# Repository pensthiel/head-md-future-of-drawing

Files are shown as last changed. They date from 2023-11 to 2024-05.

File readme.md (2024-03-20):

### Creation of the git

- *First upload on 2023-10-31*

# Contents

[**Process**](process) - [*log*](process/readme.md)

- Field researche and everything else I've been doing from the start, chronologically.

[**Presentations**](presentations) - [*log*](presentations/readme.md)

- Archives of my presentations

[**Electronics**](electronics) - [*log*](electronics/readme.md)

- Steps and references on building the electronics

[**Object**](object) - [*log*](object/readme.md)

- Thoughts, research and references on the final form of the device/object

[**UI and Programming**](programming) - [*log*Developing the program in Python

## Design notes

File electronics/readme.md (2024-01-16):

# Electronic

Shortcuts:

1. [2023-12-06](#2023-12-06) Setting up the Rasberry PI
2. [2023-12-07](#2023-12-07) Soldering ex.
3. [2023-12-21](#2023-12-21) controlling the projector
4. [2024-01-09](#2024-01-09) To do
5. [2024-01-10](#2024-01-10) Fritzing
6. [2024-01-13](#2024-01-13) Final schematic
7. [2024-01-16](#2024-01-16) Object

<br/><br/>

###### 2023-12-07

## Setting up the Rasberry PI

I plugged the PI to power and a screen but nothing appeared so I watched [this video](https://www.youtube.com/watch?v=2RHuDKq7ONQ) to flash the sd card. IT WORKED:

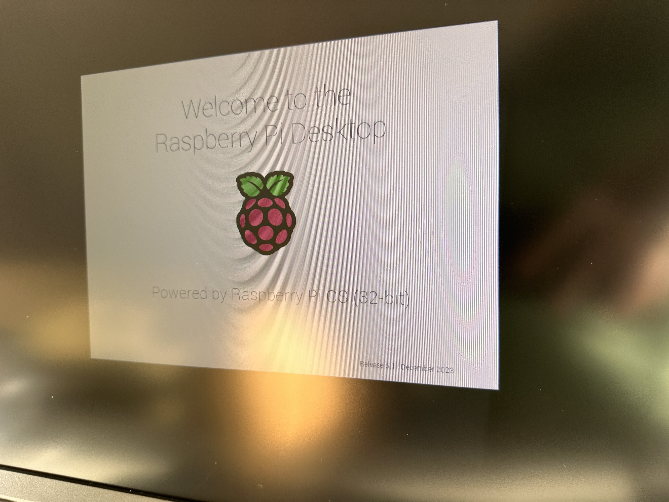
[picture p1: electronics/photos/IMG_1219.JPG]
pi


<br/>

###### 2023-12-06

## Soldering ex.

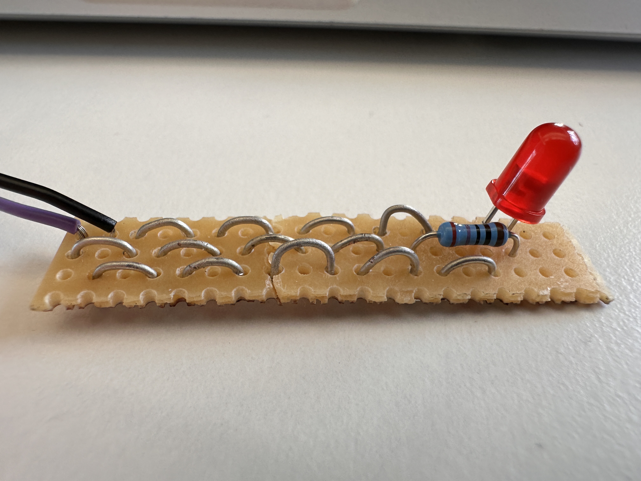
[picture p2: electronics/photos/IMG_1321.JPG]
solder
  
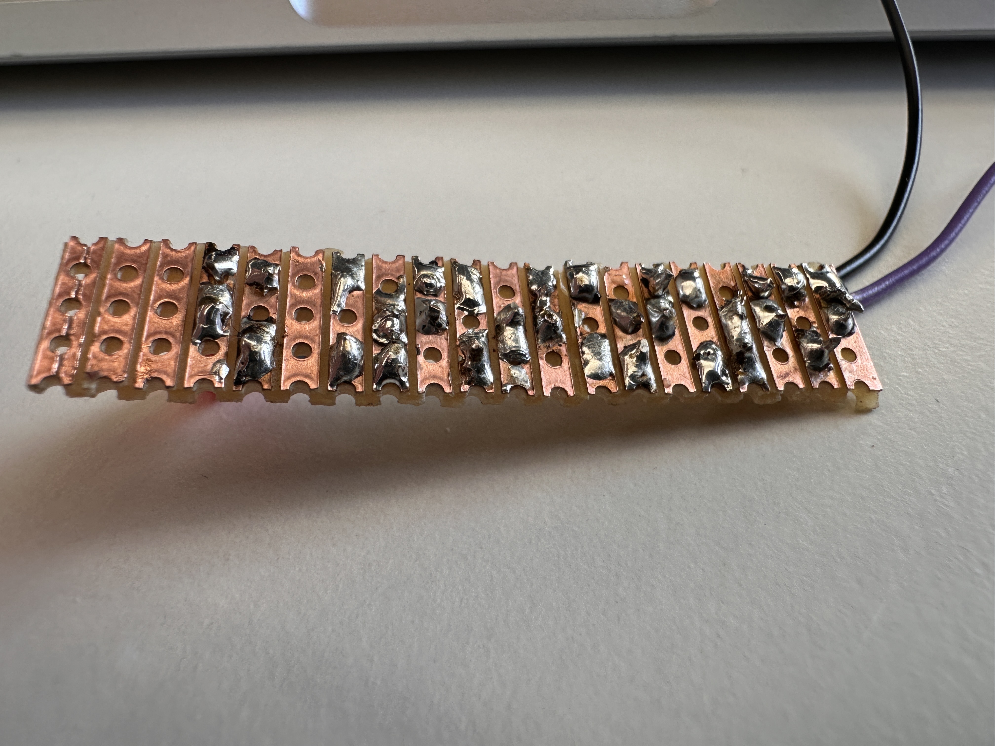
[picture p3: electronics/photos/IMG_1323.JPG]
solder2


<br/>

###### 2023-12-21

## controlling the projector

TRY to control it with HDMI with a Python library.

plan B :  
OCTO-ISOLATORs connected to buttons to control the projector buttons with the pi, you activate it as if u were turning on a led.

Don't forget we'll add LEDs to the house !

<br/>

###### 2024-01-09

## To do

- Projector control solution

I noticed there's an IR sensor and found the remote, I could read the remote's signals with the flipper zero so that I can send those signals from the rasberry with a IR led :-)

#### componants list

- <b><span style="color:rgba(244,63,94,1)">Pi</span></b>

**power switch**

GPIO pins 39 and 40. -> [link](https://www.makeuseof.com/tag/add-power-button-raspberry-pi/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't%2520get,GPIO%2520pins%252039%2520and%252040.)

**cherry button next frame**

GPIO 17 & GND -> [link](http://razzpisampler.oreilly.com/ch07.html)

**cherry button preview movie**

GPIO 18 & GND

**IR led**

[link](https://projects.raspberrypi.org/en/projects/infrared-bird-box/5) , [link](https://asimuzzaman.com/posts/send-infrared-ir-remote-signal-with-python) (directly to the 5 volt supply of the Raspberry Pi with a 220 ohm resistor inline)

**house led x4?**

[link](https://www.maskaravivek.com/post/controlling-multiple-leds-using-raspberry-pis-gpio-ports/) GPIO 27, 22, 23, 24

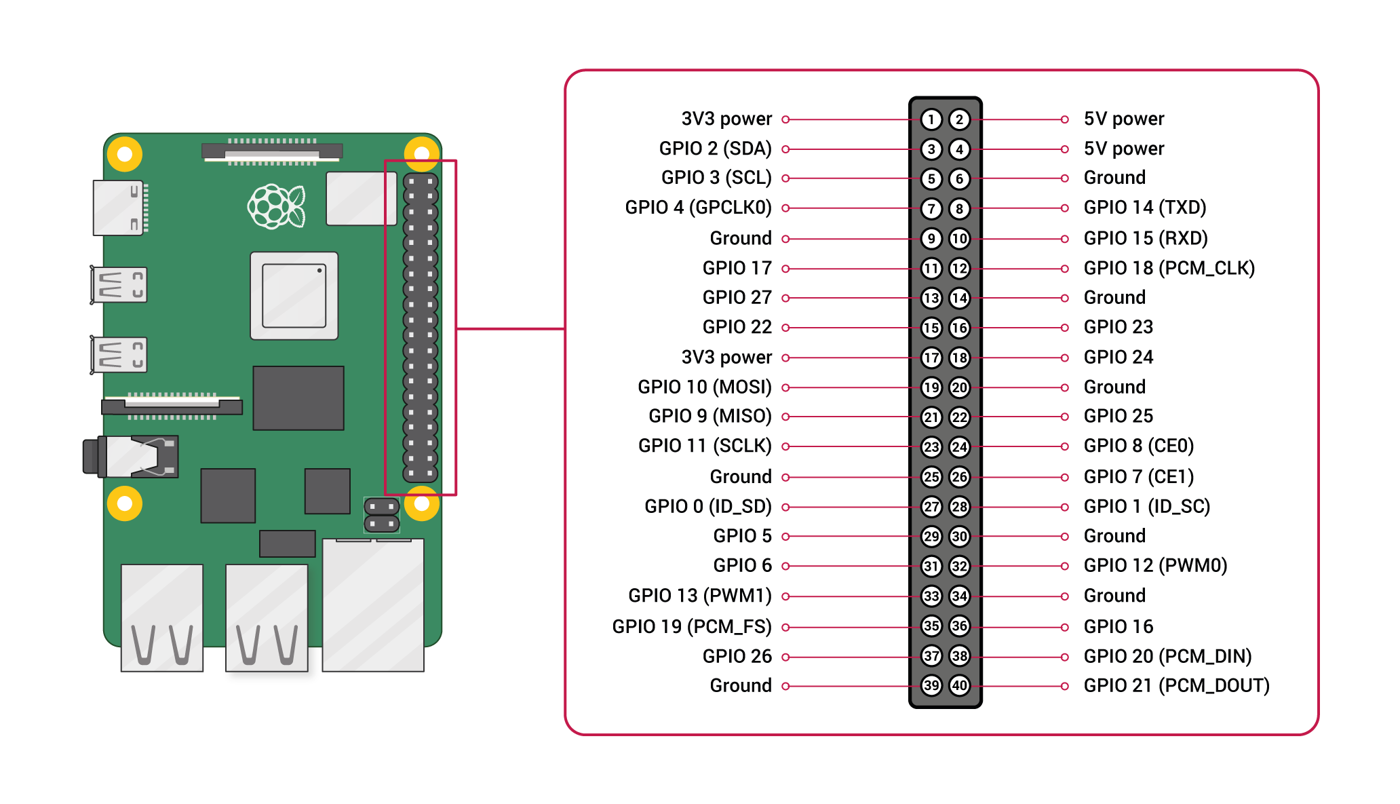
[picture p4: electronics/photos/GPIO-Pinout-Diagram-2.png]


###### 2024-01-10

## Fritzing

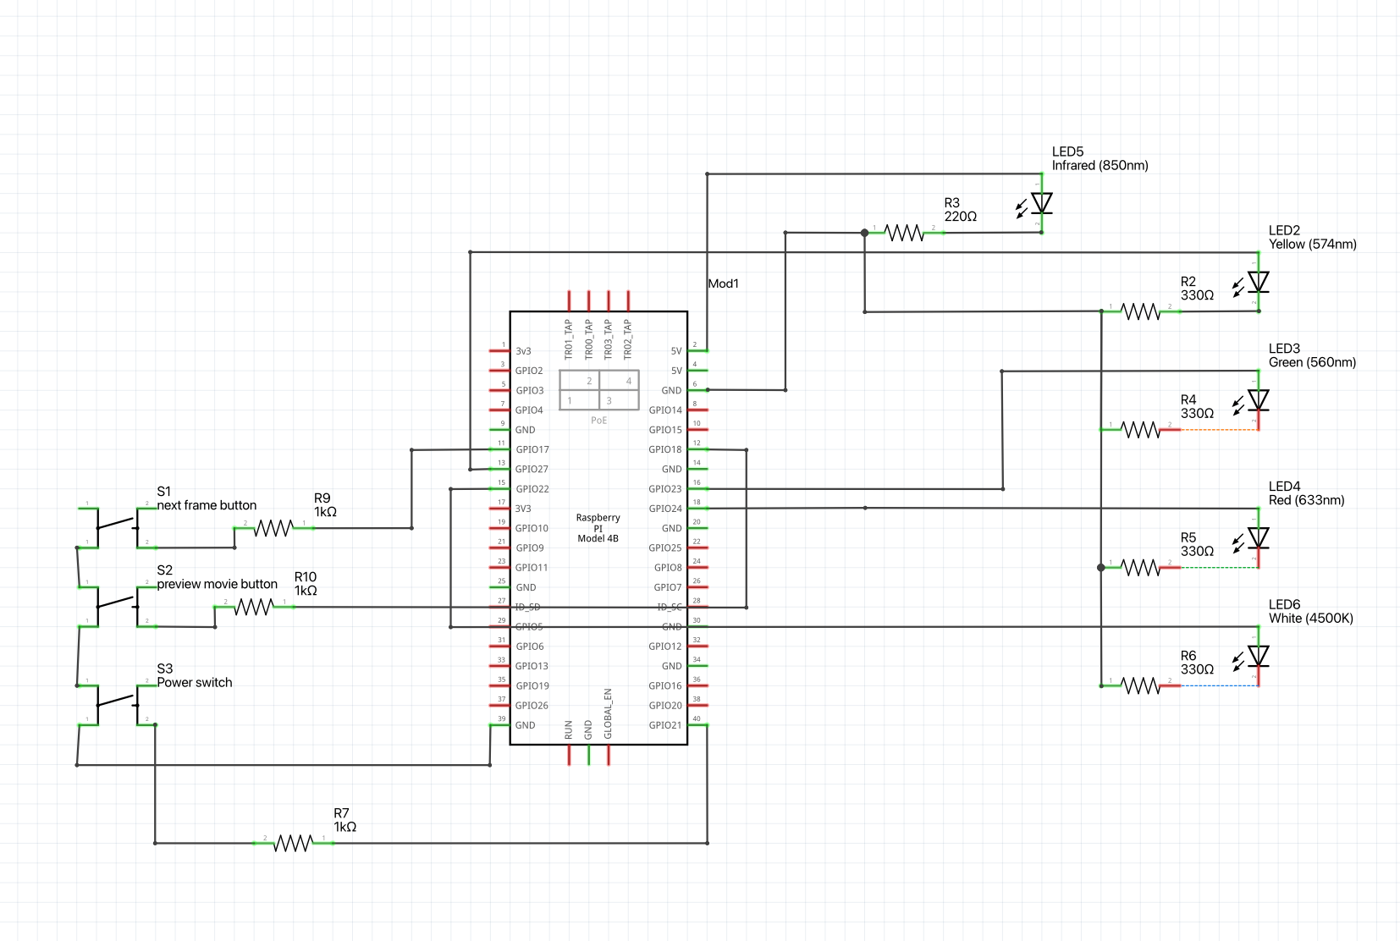
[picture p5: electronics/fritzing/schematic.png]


Needs to be verified by pierre

<br>

###### 2024-01-13

## Final schematic

Here's what we got :

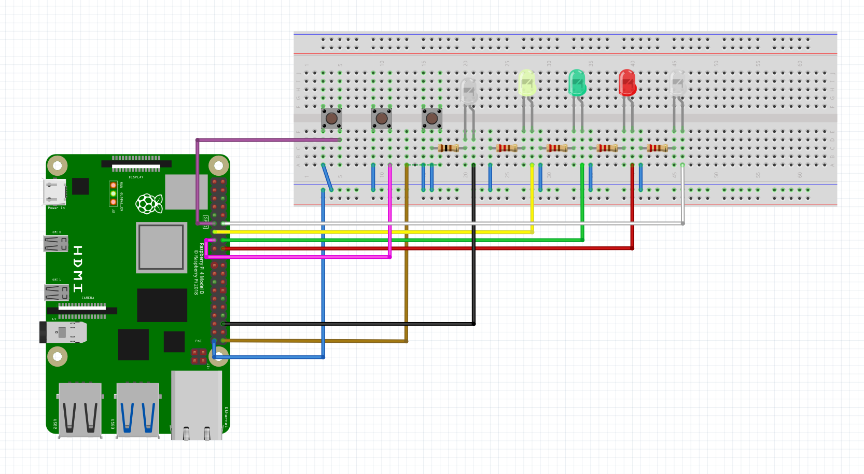
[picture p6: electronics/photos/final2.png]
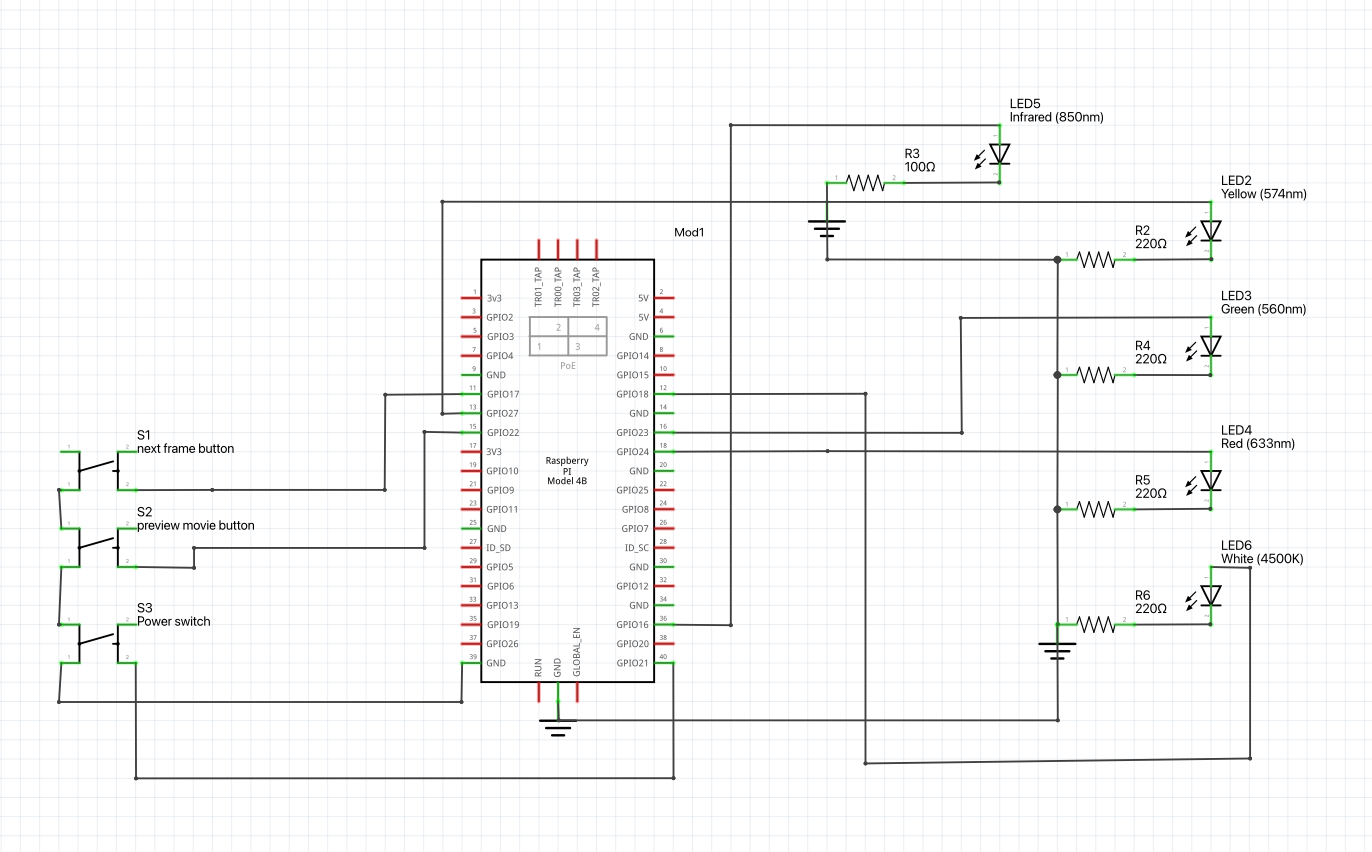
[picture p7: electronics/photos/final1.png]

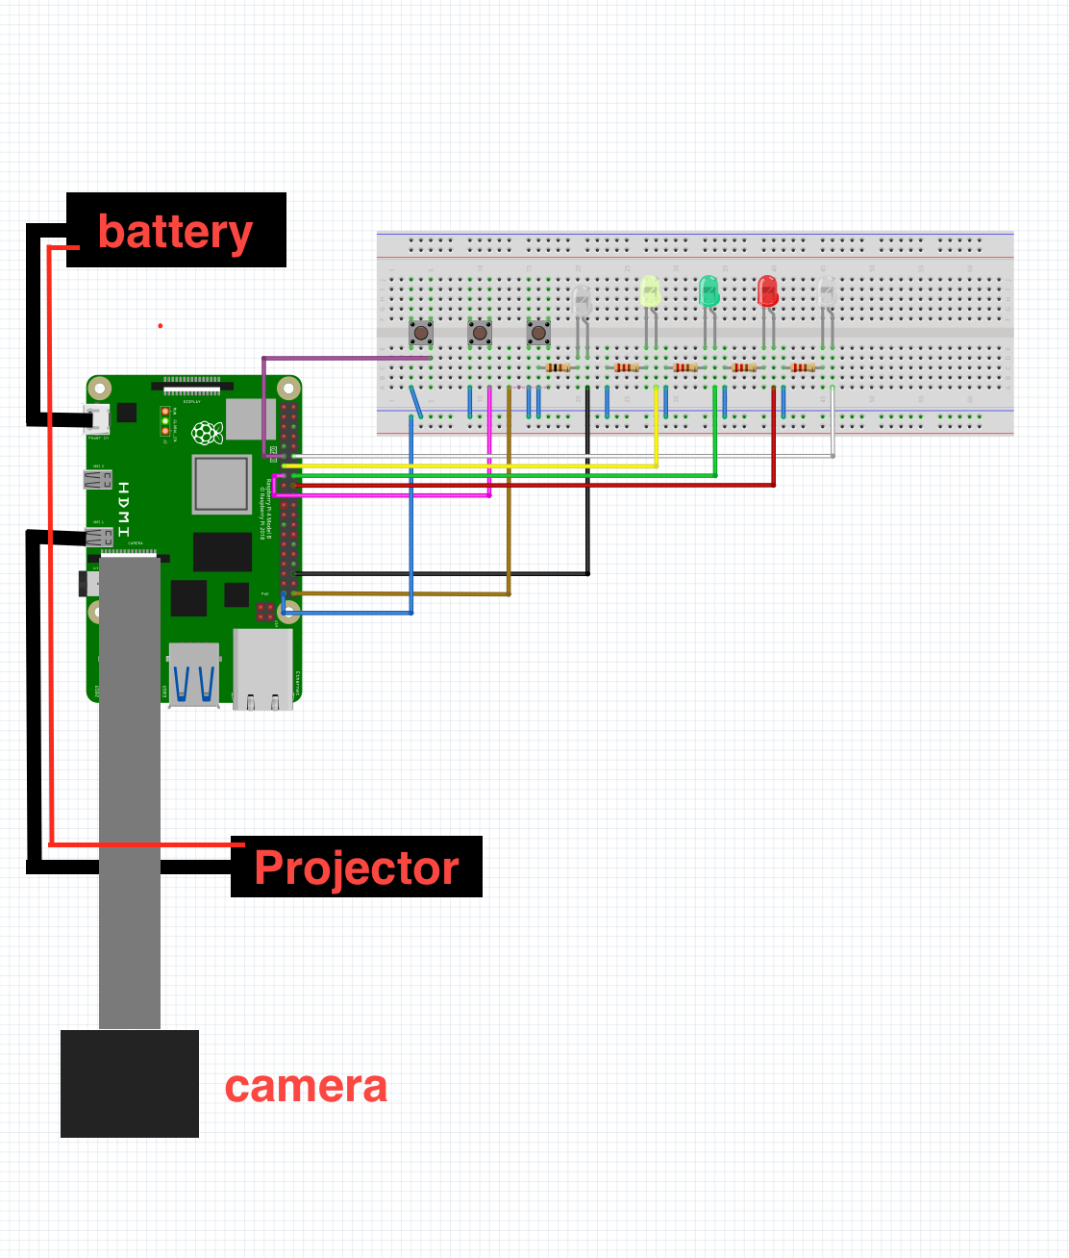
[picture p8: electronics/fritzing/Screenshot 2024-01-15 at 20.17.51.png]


<br>

###### 2024-01-16

## Object

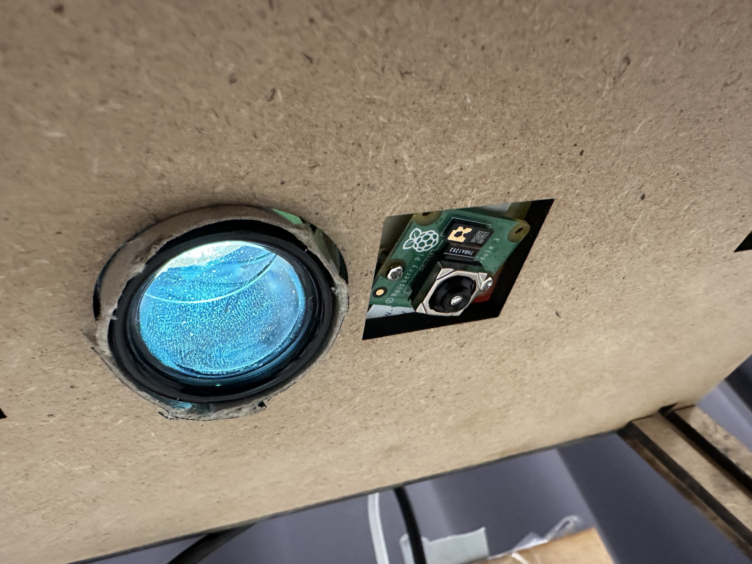
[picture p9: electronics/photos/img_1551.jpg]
photos

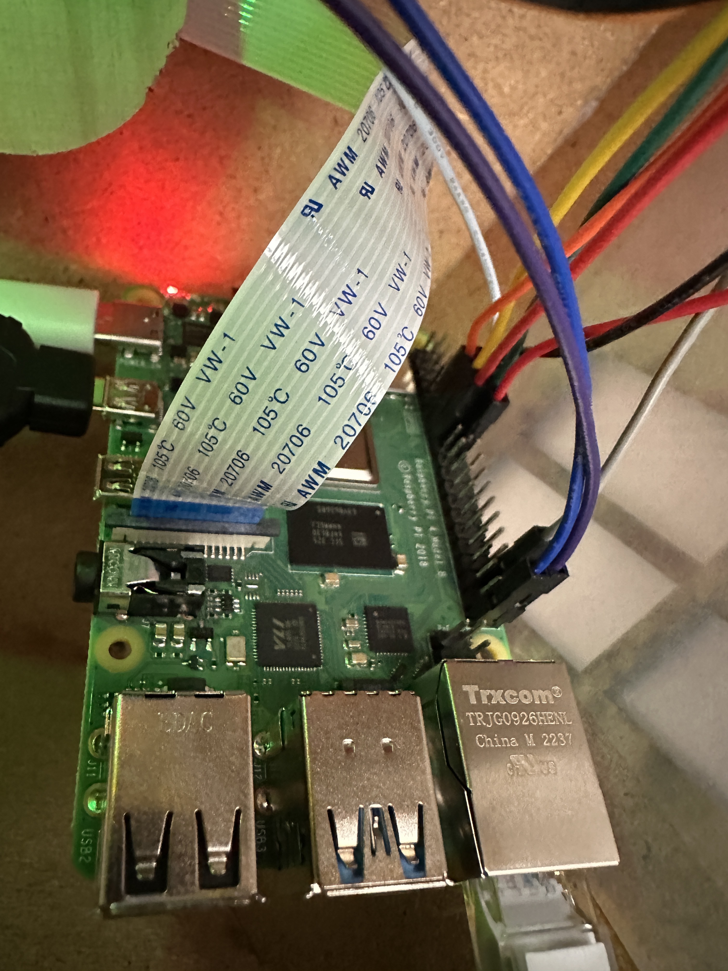
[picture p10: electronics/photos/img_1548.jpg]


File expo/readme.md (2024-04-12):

# For expo

Shortcuts:

1. Todo list
2. <br/>

## Todo list

PICO

- [ ] Find out IR commande for on/off so that we can emulate it

Mac mini programming

- [ ] transfer protocol
- [ ] frame player to display movie
- [ ] program autostart

RPI programming

- [ ] review and clean up code
- [ ] add code for IR signal to control pico (the led has been set up)
- [ ] remove part about playing the frames (since we will do that on mac-mini)
- [ ] find out if we can control the usb power output, and on/off the usb (for the lights)
- [ ] test and tweak timings and maybe add tutorial drawing ?
- [ ] calibrate camera focus and WB/aperture/colors
- [ ] calibrate alignement of camera - projection (write a program to micro-calibrate/deform for the alignment if needed)
- [ ] test sound on the pico speakers

Questions

- [ ] will we have wifi ?
- [ ] does it preview an animation the last few frame ? maybe right after the pic was taken, while we move the object
- [ ] how will ppl understand what to do and that we should move it a frame of indications could show?
- [ ] if there's live contact between rpi and projector we could display the tutorial at certain moments on the pojection on the wall

inside the objects



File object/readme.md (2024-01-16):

# Object

Shortcuts:

1. [2023-12-05](#2023-12-05) Planning the form
2. [2023-12-06](#2023-12-06) form research in Fusion 360
3. [2023-12-19](#2023-12-19) form research in Fusion 360
4. [2023-12-20](#2023-12-20) Components
5. [2023-12-21](#2023-12-21) Form as it is right now
6. [2024-01-08](#2024-01-08) Preparations for laser cutting
7. [2024-01-16](#2024-01-16) Finished!
<br/><br/>

###### 2023-12-05

## Planning the form

sketch  
I tried to measure all of my components to organize how they would fit into a box.

schematic  
sideview

I've gathered that the box should be around 20 x 10 x 10 cm to have space for everything (can probably be smaller though)

I now have to find out how to make it stand about 20 to 30cm above the paper and how the wheels will look.

The initial idea looked like that:  
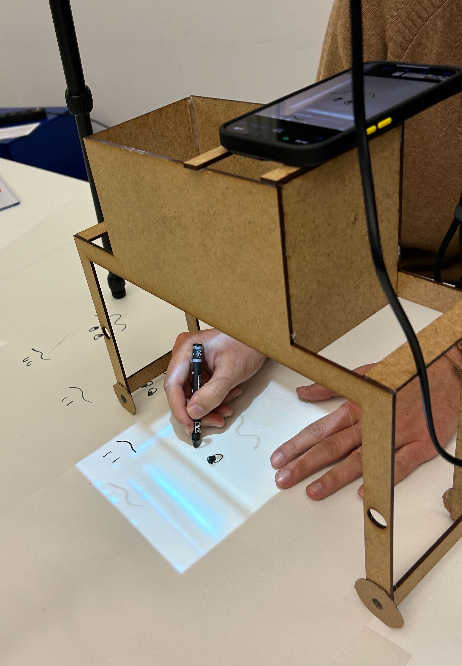
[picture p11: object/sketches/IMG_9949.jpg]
prototype3


This box was 20 x 10 x 12 cm and it was 20 cm above the paper, so an appropriate size already.

I had set the width to be above 30 cm so that it could fit the length of an A4 sheet. Just as a first try.

30cm was long enough because we didn't need to fit both hands under. Smaller could work but it might be uncomfortable to draw. Larger would be more comfortable but too bulky I'm afraid.

<br/>

###### 2023-12-06

## form research in Fusion 360

Here's some experiments  
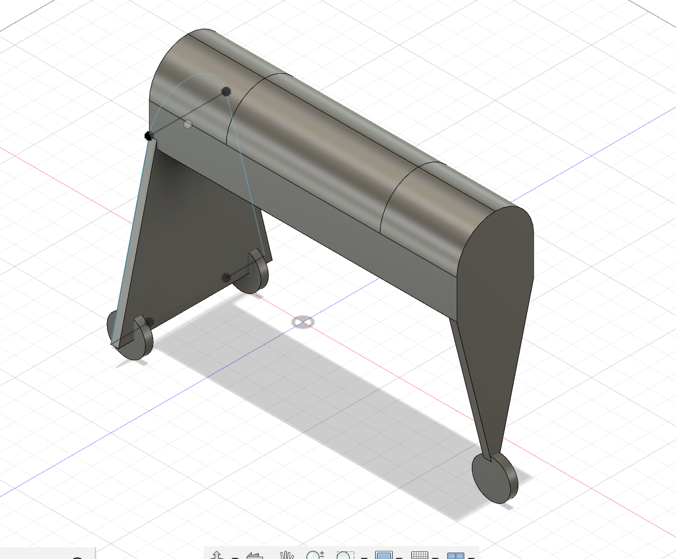
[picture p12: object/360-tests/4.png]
test4
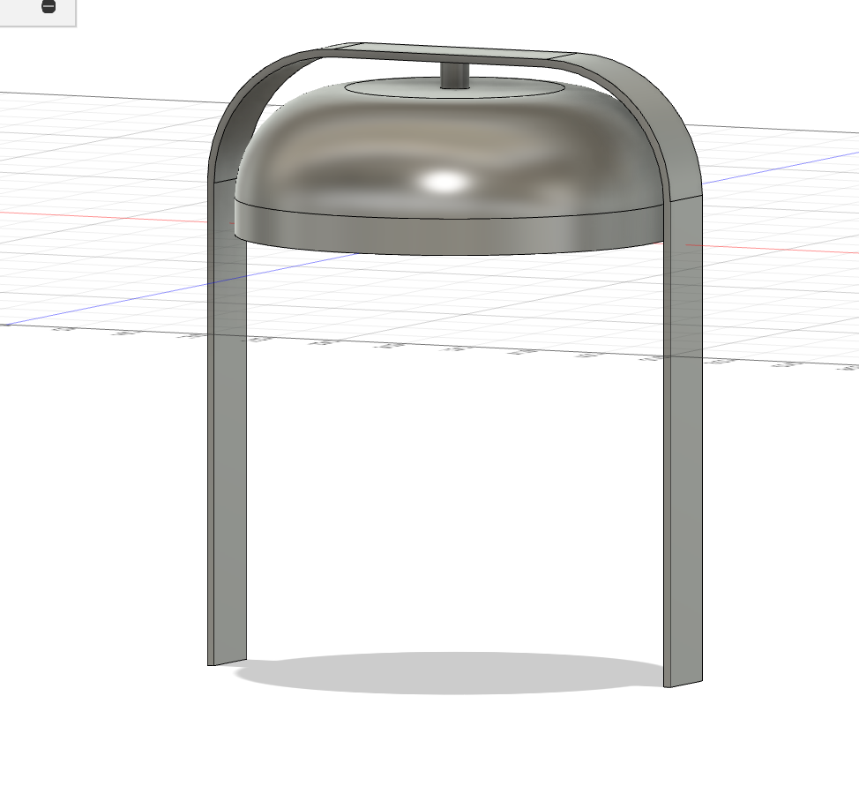
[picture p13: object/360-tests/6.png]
test6
test1 test3  test5 

<br/>

###### 2023-12-19

## form research in Fusion 360

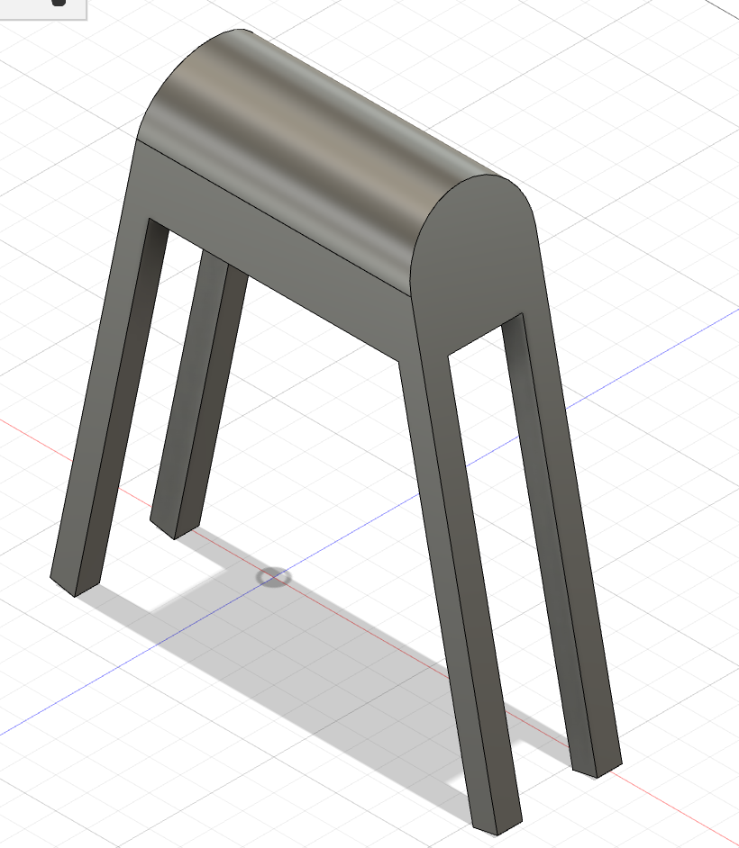
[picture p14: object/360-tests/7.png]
test7
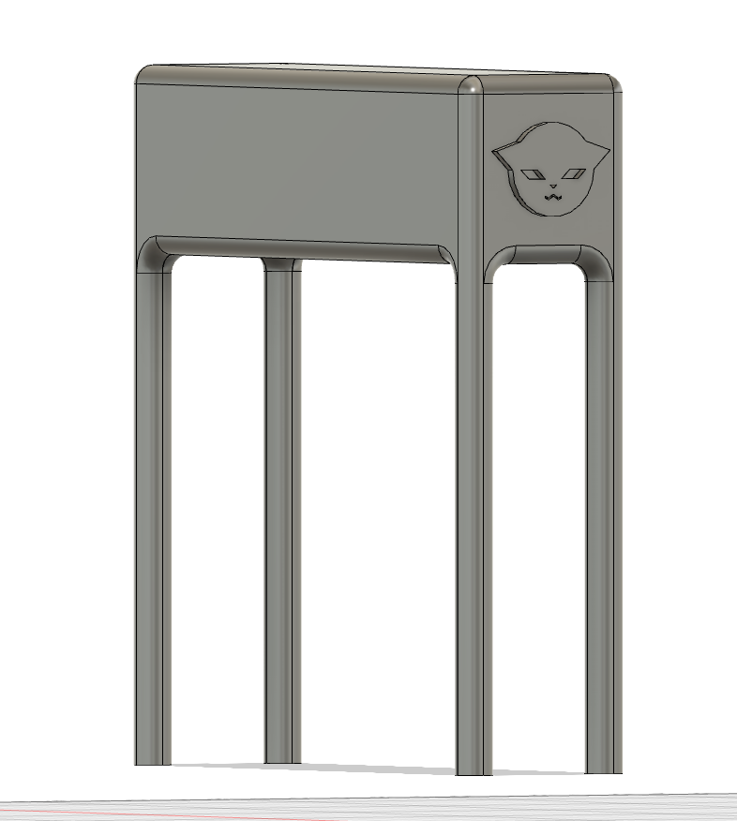
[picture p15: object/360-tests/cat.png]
cat
 

<br/>

###### 2023-12-20

## Components

- Rasberry PI
- battery
- SD card
- mini projector (projects onion skin and acts a display screen)
- PI camera (missing zoom lenses)
- button 1 - next frame (takes pic, moves, projects pic)
- button 2 (plays a video of the saved frames)
- switch on/off
- wheels
- step motor to move wheels
- cervo motor to turn wheels
- motor controller ?
- LEDs if i do the little house design

### Attempts at making the final form

v1  
v1  
v2  
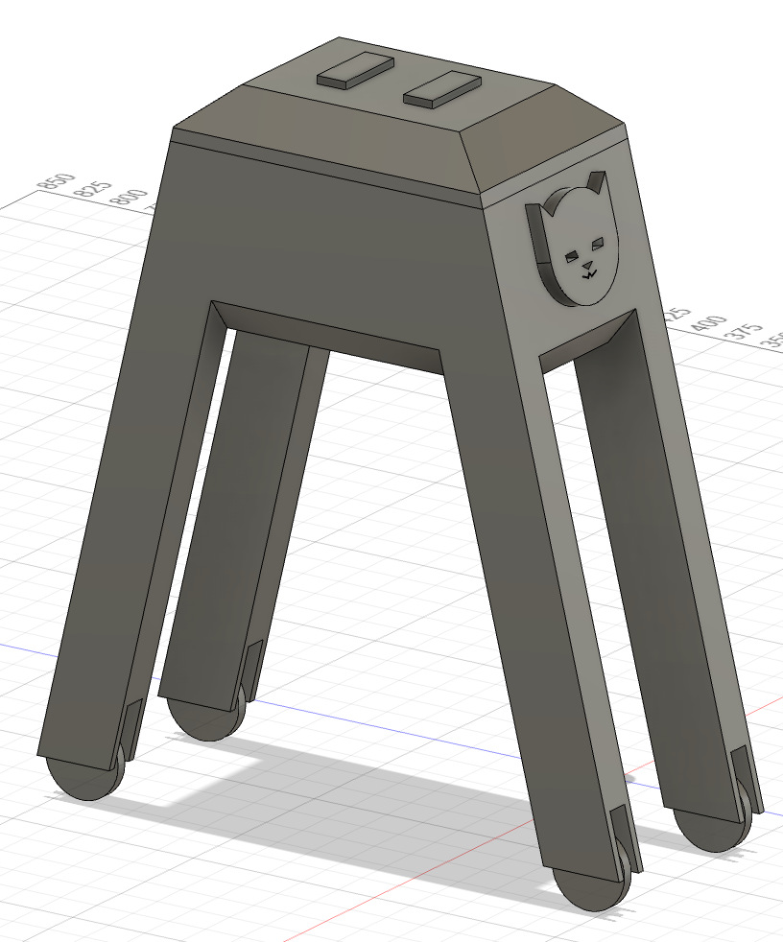
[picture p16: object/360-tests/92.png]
v2


This cat is too chonky, I think I prefer the house, however, I'm afraid the box is not deep enough and will need adjustments. maybe it should be longer too?

It would need to be made with wood.  
Which is warmer, cozier and smells good. I also want to add LEDs and blurry windows so that the house looks like it has lights in.

<br/>

For the house my inspirations were these kind of objects:

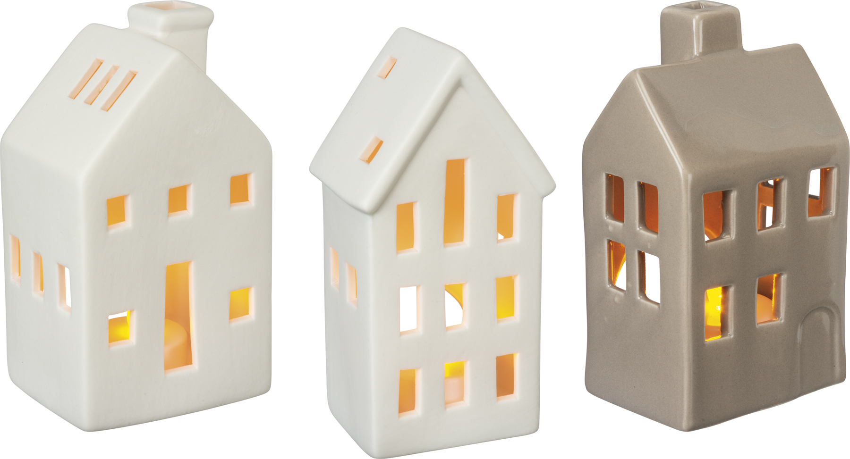
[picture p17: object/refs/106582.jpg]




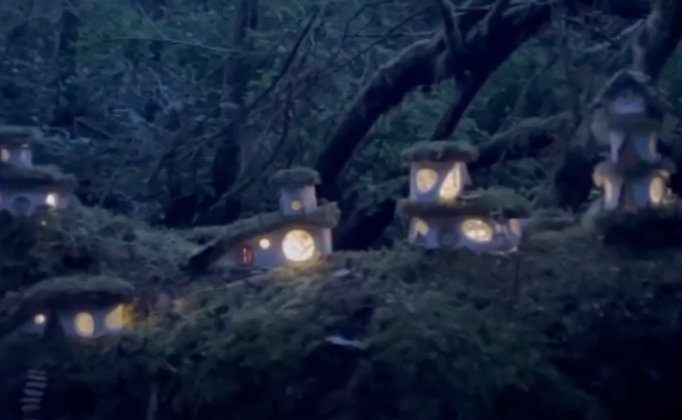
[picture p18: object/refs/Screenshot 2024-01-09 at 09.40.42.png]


Essentially I was thinking of like a dreamy / fairytail vibe, just like how animation films make me feel.

###### 2023-12-21

## Form as it is right now

view1  
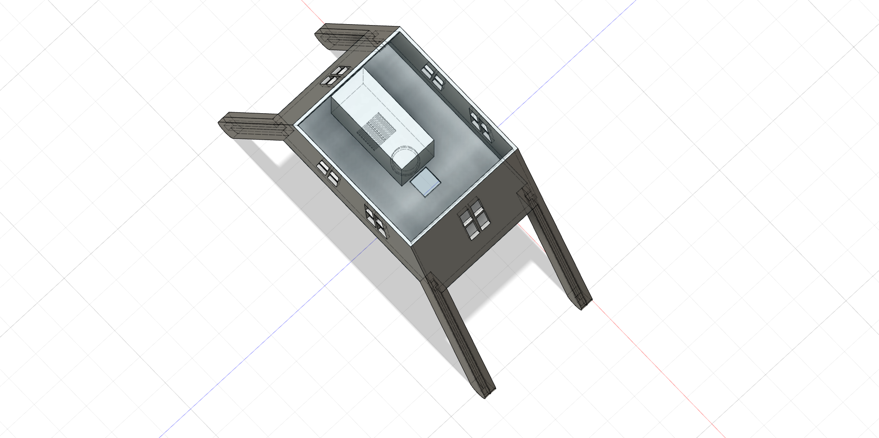
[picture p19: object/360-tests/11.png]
view2
  
view3

<br>

###### 2024-01-08

## Preparations for laser cutting

I've added last-minute holes and stuff to make it work.

flat

With the angles of the borders for later modifications.  
seams  
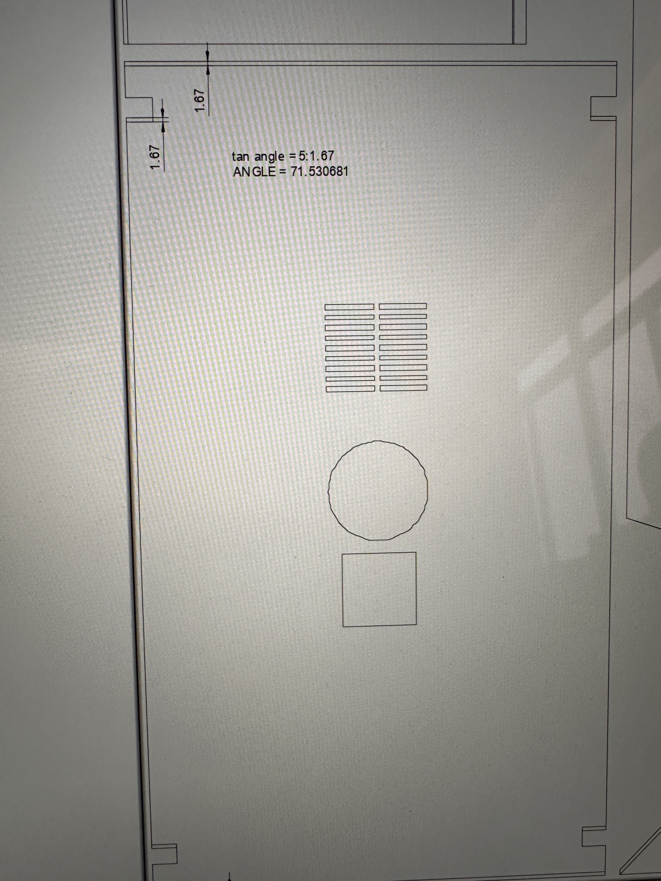
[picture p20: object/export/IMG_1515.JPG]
  
seams  
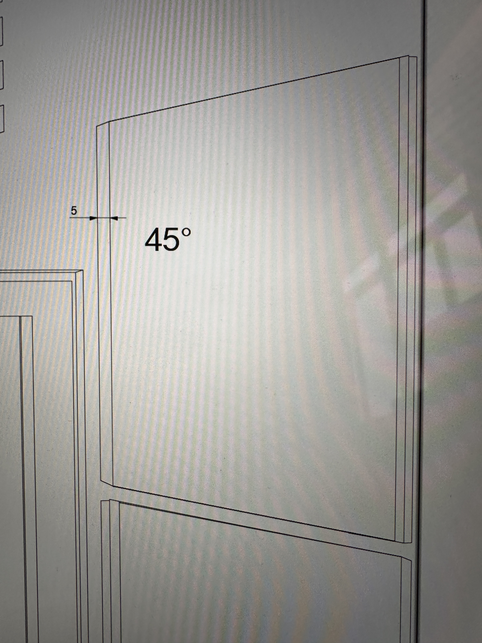
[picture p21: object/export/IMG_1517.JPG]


<br>

###### 2024-01-16

## Finished!

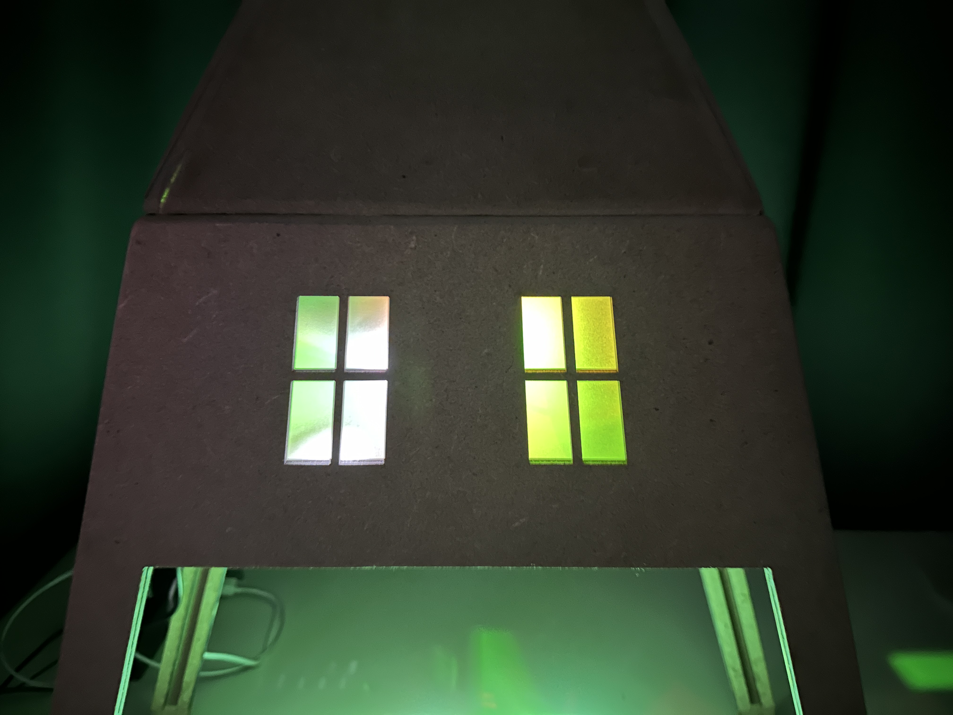
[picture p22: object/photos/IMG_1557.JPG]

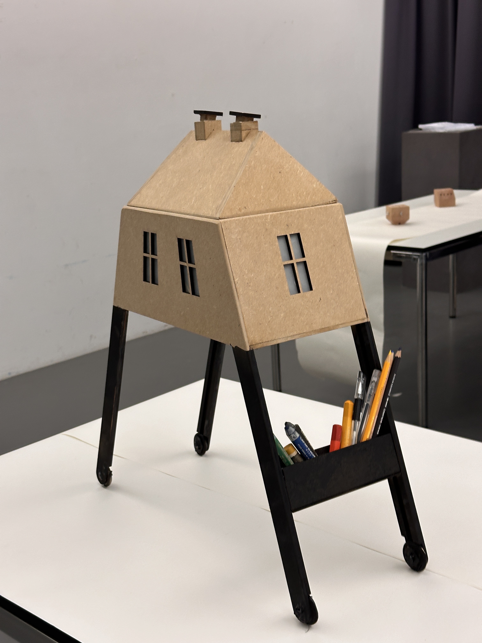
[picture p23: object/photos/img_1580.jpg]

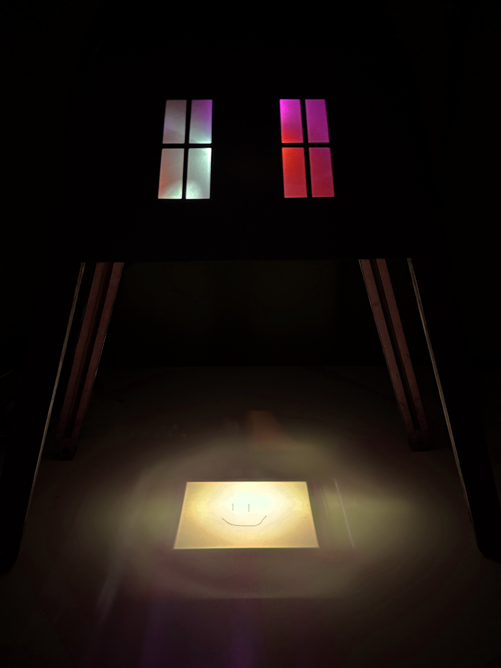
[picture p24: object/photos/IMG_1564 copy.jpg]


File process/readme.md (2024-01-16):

# Process

Shortcuts:

1. [2023-10-30](#2023-10-30) Research 1
2. [2023-10-31](#2023-10-31) Prototype 1
3. [2023-11-01](#2023-11-01) Testing 1
4. [2023-11-03](#2023-11-03) Pitch and key insights
5. [2023-11-13](#2023-11-13) Prototype 2 (fail)
6. [2023-11-14](#2023-11-14) Sketching and prototype number 3
7. [2023-12-04](#2023-12-04) Planning the electronics
8. [2023-12-05](#2023-12-05) Planning the form
9. [2023-12-07](#2023-12-07) ORGANIZATION
10. [2023-12-12](#2023-12-12) Sounds and design
11. [2023-12-13](#2023-12-13) Programming
12. [2023-12-14](#2023-12-14) Test day!
13. [2024-01-08](#2024-01-08) Happy New Year!
14. [2024-01-16](#2024-01-16) Last run

<br/><br/>

###### For 2023-10-16 until 2023-10-26:
Refer to the files in the process folder to view what was made before creating the git.

<br/><br/>

###### 2023-10-30
## Animation machine idea

### Interview
On my first interview test, my questions weren't very good but I had an insightful discussion with someone who said they don't draw much but they used to draw to make little animations, and that drawing is exciting because of the possibilities and all the things you can come up with and create.

### On the topic of animation
Following this discussion, I remembered that I was doing silly little animations too. I then dig up an old collection of little animations I had made in that quick, low expectation high spontaneousity and intuition flow. I realized that for me this is when drawing feels the best when you convey a story without worrying about how you draw when it happens quickly enough that you can almost create the scene in your head in real time, where it doesn't matter if it's stick figures. When it moves it comes alive.

### Ipad animation apps

In an app like "animatic" on the iPad, where you have a stylus to draw and the app is bare bone with very few options, it's very easy to be loose and spontaneous in your drawings, since there are lots of frames to do you want to be very quick and since it goes by fast there is no use in focusing on the details. the less you focus on doing it "well", the more expressive and fun the result will be.
The app is easy to use, and you have the most basic and necessary tools for hand-drawn animation:
Onion skin, new frame and export video.

Animations I've done on the iPad

### Resulting path I might go on

I absolutely love those iPad apps but when drawing on a tablet I lose all the sensory joy of traditional drawing tools such as the Caren d'ache products. My thought was that If I could make an app or tool that can provide tools such as Onion skin and "next frame" but physically to use with traditional tools, I could make hand-drawn or painted animation as accessible and as easy as when I use those iPad apps, we could make works as expressive as my digital examples but with the feeling of physical tools and with the beauty, colors and textures of Caren d'ache tools.

<br/>

### thoughts about the process

How could I redirect field research that way?
- rewrite interview questions
- make animation cadavre exquis with classmates and take notes
- prototype the paper roll mechanisme of my drawing

Things that the device could be doing:
- roll paper like a "parchemin" to get to the next blank frame automatically
- Projector for onion skin?
- camera to capture frames for onion skin
- the camera could double as quality export material like if you have a light and maybe a wall to block external lights and the fact that the drawing will be directly placed correctly for "prise de vue direct" and it would make the process even more accessible if you have direct export and no post process are needed.

### Paper size

Should probably be a small drawing area, as small drawings are quicker, less focused on details and its easier to loosen up..
small is transportable small you can leave on a desk and use it anytime.

### Goal ?

Remove all friction in the traditional animation workflow to make it more *accessible*, quicker, less scary easier to experient animating with all kinds of tools.
ipad-like silly animations but with ~ sensory pleasure ~ and *texture* and ALL THE TOOLS.

### Sketch
Drawing of my initial machine idea

### other unrelated ideas:


<br/><br/>

###### 2023-10-31
## Creation of the git, and building a cardboard prototype
we had a quick presentation of our process with the classe and then I started building my first animation machine prototype to test the idea of the rolling paper...

photos of the cardboard build
2nd picture

I've put a piece of clear plexiglass because I can't really test a projector, but on the iphone there's an app to draw with onion skin using the phone camera, it was made for stopmotion animations and it looks like that:

Stop motion studio
how it works

<br/><br/>

###### 2023-11-01
## Testing the prototype

### Person 1 
(doesn't draw)

She said it reminds her of the animation app on Nintendo DS, which was very simple, didn't have many options and was low stakes.
The toilet paper helped to lower the stakes even more so it was easy for her to relax and draw without pressure.
She really enjoyed it even if she does not normally draw.

### Person 2 
(illustrator)

he was excited by the device and loved using it,  he wanted to continue and not stop.
described that he would not normally do animation and that he had no idea that it could be done this way, the process made it a lot more accessible. 
Toilet paper was not ideal as it tears so it's hard to draw on
- A bigger screen would help
- The size is good
Loved the idea of using other mediums like ink.
Made him want to do a lot more animations.
having just to push 1 button to go to the next frame makes the process super quick and it makes you want to do more.
- wanted an accessible button like you could just draw with one hand, click with the other, draw again, etc... (note: he is left-handed, so the button would need to be movable ?)
said that normally the process for traditional animation is intimidating because you need like a camera or scanner and transparent paper or holes to align the paper but with this machine, it felt effortless.

### Person 3 
(illustrator)

- Had trouble understanding what needed to be done at first ( maybe I should have an illustrated tutorial somewhere ).
- Panicked a bit when she drew on the table.
- She did say "This machine is incredible!".
Drawing on toilet paper is tedious. 
- She had never animated with traditional drawing tools and she had fun, and said it's better than on the tablet. 

cadavre exquis they all made

### Takeaways
- needs better paper (I'm looking for some ticket machine rolls)
- people had fun
- makes traditional animation accessible and makes it a lot less intimidating
button with haptic?
only 2 steps, draw and press the button. simplicity=good
the paper roll feels a lot less scary than a white page, makes it easier to start without fearing of messing up, also because the last drawing disappears in the roll.
- small size makes it quicker
- makes people want to animate, and aniimate more
- we just continued the animation after each person so it made a collaborative cadavre exquis

film I made with the prototype

### Final notes of the day
- if I make it with the same system as the iPhone app I could have a bigger screen.
- the object right now is small enough to be portable or to be kept on my desk.
- having a light would make the pictures more homogenous and the camera gives better quality if the lighting is good but it would need to be an area light or ring light and not a spotlight.
- I thought it might be too small to draw comfortably but actually, since we only draw with one hand and the other hand would be with the button externally this size is good and those who tried like the size.
- height seems good too, too high you wouldn't see the screen and too low you would not be able to use taller paintbrushes....
- you canot be super precise but i think that's a good thing because the animation style is more expressive that way

USE " analogue " INSTEAD OF " traditional ".

### Teachers comments
Should be more than just a tool.
but it's good and works great, think of other forms, of storytelling? could it be a teacher? coach? tutorial but in a creative way? does the roll tell a story? (I would rather the roll stays blank)

### NEXT STEP
Get an A3 page of paper and draw a hundred different animation machines !
(to iterate and find unlikely forms and systems)

<br/>

###### 2023-11-03
## Pitch and key insights

### Project description
I'm on a mission to make analog animation more accessible and enjoyable for everyone, from hobbyists and indie filmmakers to kids. Animation, for me, is the ultimate worry-free way to bring creativity to life. Inspired by user-friendly iPad animation apps, my project aims to bring the simplicity and fun of digital animation to the tangible world. By creating a device that simplifies the animation process, I hope to eliminate the traditional complexities, making it quick and enjoyable. This project is dedicated to utilizing Caran d'Ache tools, providing a wide range of textures and creative possibilities that traditional animation offers.

### PITCH
This project is to build a user-friendly tool that simplifies analogue animation. Inspired by easy-to-use iPad animation apps, I am trying to bring that simplicity to analogue animation. Making animation accessible, quick, and fun for everyone, with the tactile joy of hand-drawn art. The object is dedicated to giving a fun project to do, providing a worry-free way to use the Caran d'Ache tools for minimal friction and maximal accessibility and creativity.

### key insights
I've tried to engage in as many discussions as possible about this subject with anyone I've recently met.
- People who have tried animation had fun drawing in that context, even if they don't normally draw.<br/><br/>
- Any drawings can result in interesting movements, but most people feel the drawings need to be "good," making animation seem inaccessible.<br/><br/>
- Even those who are comfortable with drawing still consider analog animation inaccessible due to the steps, complications, and time it involves. (iPad animation apps alleviate this, but not everyone enjoys digital drawing, and we don't all have an iPad.)<br/><br/>
- Professional animators are also interested in finding processes that can yield different and interesting results, and any reduction in friction is welcome in any process.<br/><br/>
- Traditional animation courses typically begin with a simple ball bouncing, which is a good way to explain how animation works in a simple, accessible manner, helping people get started.<br/><br/>
- I've encountered frustration when trying to convey to people that drawings don't need to look good and that it's possible to draw without worrying about how it looks. But how can I convey that with my project? How can I help people let go of perfectionism?<br/><br/>
- Children can naturally do this, but it becomes harder as we age, affecting everyone, both regular people and experienced illustrators alike.<br/><br/>
- Sometimes when I show examples of "bad" drawings that are fun, it helps.<br/><br/>
- In my studies of illustration and comics, I've encountered multiple ways in which drawing exercises are used to loosen up and help with letting go of perfectionism. These exercises include drawing with closed eyes, using the non-dominant hand, or applying constraints like designers do to enhance creativity. Constraints mean we can't achieve perfection, so we don't demand good results from ourselves, and we're not paralyzed by expectations. This unleashes creativity.<br/><br/>
- I've also attempted to study procrastination, and the desire to excel seems to paralyze people to the point where they can't even try at all.<br/><br/>
- Another thing that will paralyze anyone is feeling like we're not allowed to fail. In one of my experiments, non-illustrators felt that it was easier to draw on toilet paper (which is difficult to work with) than on normal paper because they felt that it was okay to fail on something that is destined to be thrown away. They have a hard time allowing themselves to waste paper.<br/><br/>
- It is most difficult to allow ourselves to fail or waste resources, like paper or nice pens and art tools such as Caran d'Ache products.<br/><br/>
- To be creative, one must be allowed to fail, destroy, and waste resources.<br/><br/>
- In animation, you HAVE to waste paper, so maybe that's why some people manage to draw more freely when drawing on paper rolls.<br/><br/>
- The final project needs to be more than just a tool. <br/><br/>
- For optimal use, one hand should have access to "next frame" button while the other hand is drawing.

<br/>

###### 2023-11-13
## Prototype 2
The tale of a failed experiment ._.


build

Jokes aside, I enjoyed building this, and I love the form and design. However, it doesn't work because physics don't operate that way, and I'm neither a scientist nor an engineer.

demo

<br/>

###### 2023-11-14
## Sketching and prototype number 3
Idea drawings

Projector on paper roll iterations
projector on paper roll drawings

I then realized that instead of the paper roll turning, the device could be moving on a large area of paper so that there is both an animation output and an analog cooperative artwork output.
Then the project becomes a mix of 2 different things, animation and cooperative doodling...

The thought is that for an exhibition context, it would be more interesting and entertaining for the drawings to output to something physical as well as digital.

Form and movement iterations
form and movement drawings

A rail mechanism like on drawing machines would work, but having an RC car type of device driving around would be infinitely more entertaining. Of course, it would be automatic, AI-driven.

Physical test with a projector
projector testing
projector testing

How it would work:
projector testing
projector testing

What the output could look like after many users used the device on the same canvas...
The canvas would be big like 1m x 1m on a table.

But perhaps it would make more sense on the floor? Then it could be even bigger...
But I'm not sure. I'm wondering if this is too much and maybe it was better as a simple tool.

projector testing

At least the projector part works, mine had to be placed far from the canvas but I've been told that some projectors are designed for shorter ranges.

I used my phone here but I would like it to have its own device that does camera + driving algorithm for the wheels + streaming to projector + screen for buttons and animation preview?

### Idea generator?

I would like the screen to feature a button for inspiration if someone doesn't know what story to draw...

button
prompts

As well as some naive art inspiration to loosen up when drawing
button2
naive-art

The text generator would be random words while the image output would be examples of kids' drawings or simple flipbook animations.

anim-example
anim-example2
anim-example3

<br/>

###### 2023-12-04
## Planning the electronics

notebook

I'm trying to find out what I'll need to build the final prototype for the presentation.

- Raspberry PI
- a projector I can dismantle (got one already)
- 2 buttons (included in the Arduino kit)
- USB camera ( I have one but I'm missing the cable)
- power bank (I have one)
- 3d printed wheels and turning mechanism?
- switch to turn on or off the whole thing
- motors for the wheels? 

The first thing will be the camera/projector part.
I can move the object on wheels by hand for the presentation,
coding motors can come later.

<br/>

###### 2023-12-05
## Planning the form

I guess I should rather continue in the "object" folder.

--> [Link](../object/readme.md) <--

<br/>

###### 2023-12-06
## Projector test and wheel turning mechanism

test1

So I moved the lense to get a sharp image on the paper.
That worked but there are 2 things to note:

1. The image was too small so I'll have to place the projector higher, about 30 cm from the paper ( it was 20 cm away here )

2. It does not boot automatically so I'll need to find a way to trigger the booting when I power on the PI.

I also came up with an idea to turn the wheels with the servo motor, idk if it would work.

turning-mechanism

<br/>

###### 2023-12-07
## ORGANISATION / STEPS

1. Electronics / components and cables
    - PI
        - camera
        - projector
        - buttons
        - motors

    CABLES
    - power -> PI
    - power -> Projector
    - camera <-> PI
    - PI -> Projector
    - buttons -> PI
    - switch on/off -> PI and Projector
    - step motor -> PI
    - servo motor -> PI

2. Coding / Make the program
    
    - it should, on a button press, display a white screen, take a picture and then display the picture fullscreen, until the next time the button is pressed.
    - plays film of all the frames at 6 or 12 fps when we press preview.
    - will need to control the motors if we have time. step motor and servo motor.
    - to do :needs to launch at wake on the pi and connect to camera and HDMI projector.

3. Design / decide on the form
    - find a good form
    - fusion 360 final design

4. Details / figure out the buttons and all that
    - on/off for both PI and projector
    - next frame button
    - preview button

5. Build / put it all together
    - cut wood
    - build metal? solder ?
    - assemble / screw / glue

#### Inputs
- camera
- button on/off
- button next frame
- button preview

#### Outputs
- projector
- step motor
- servo motor

#### size
Approx. 40x40x20 cm for the whole thing

#### Power
10'000 mah usb power bank powering the pi and the projector.
(both can work on 5 volt usb)

#### Things I have yet to figure out
- how do I turn on the projector and PI at the same time?
- what materials for the form
- where do the buttons go (most comfortable and accessible place)
- how do I build the wheels
- turning mechanism
- should I cut the cables to make them shorter?
- holes !
    - for ventilaion !
    - to charge the battery !
    - for buttons !

<br/>

###### 2023-12-12
## Sounds and design

I had an Idea!

Since we have speakers, as feedback, when we press "next frame" or "preview", it could make a sound.

I thought of styling the form to make it cute, but I wasn't sure if it was relevant...

However, I thought about it more and actually it would make sense to make it like a cat or something, as a reference to big animation classics such as the Miyasaki ghibli movies, which are probably the biggest inspiration for most animators.

So the sound feedback could be a cute miaou! and for the preview, the cat could be humming a song.

Jonas said would be nice if the projector came out of the face but idk.

<br/>

###### 2023-12-13
## Programming
Refer to the prog readme :-)

--> [Link](../programming/readme.md) <--

<br/>

###### 2023-12-14
## Test day!

test day picture

I asked everyone about where to place the buttons and I had interesting insights:

1. the sides are not ideal because some people are left-handed.
2. the front is more visible and straightforward.
3. it could be icons, no need to write words.
4. doesn't need to be as accessible as I thought since the object moves anyway so the flow is interrupted in any case.
5. if there are buttons on the front it might tilt the object so it might need to be touch-style buttons.

<br/>

###### 2024-01-08
## Happy new year!

Today I've been preparing files for laser cutting (for tomorrow) and I did some Python coding.

I realized we really don't have much time left so I need to focus on the most important steps for next Wednesday.

There's also the PDF file to do as well as the documentation and handover files ! !!! !!

<br/>

###### 2024-01-16
## Last run

We had to rush at the end but I'm pretty happy with my project.
See the final presentation --> [PDF](../presentations/2024-01-final/Dossier 240117_HEAD-MD1_Caran-d-Ache_Thiel_Lauren_Home_Studio/240117_HEAD-MD1_Caran-d-Ache_Lauren-Thiel_Magic-house.pdf)

Check out the code in Programming and the form in Object.
Thank you for reading through!

(Also we have a new name: Magic house)

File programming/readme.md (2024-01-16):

# UI and Programming

1. [2023-12-08](#2023-12-08) Research
2. [2023-12-13](#2023-12-13) Programming day 1
3. [2024-01-08](#2024-01-08) Working script 1
4. [2024-01-08](#2024-01-08) GPIO mapping and Preview program
5. [2024-01-13](#2024-01-13) New cam new program (had to start over)
6. [2024-01-16](#2024-01-16) FINAL CODE

<br/><br/>

###### 2023-12-08

## Research

Doug recommended I use OpenCV to use the camera as imput instead of physical buttons.  
I found [this](https://github.com/amarlearning/Finger-Detection-and-Tracking) but it's in PYTHON, I would like to do everything in python to learn it but teachers will probably recommend using Processing java...

Is Processing Python an option ?????

<br/>

###### 2023-12-13

## Programming day 1

Processing is no good for handling video feeds, I found that out on my first test so I switched to Python. I also realized it has more resources online that are also more accessible.

Hadn't done Python in a while so GPT helped me ease back into it.

1. PI

Had to setup the PI but I had the 32bit version which was no good so I re-flashed it to 64bit

2. github

This was harder than anticipated because git won't let you log in with a password in the terminal anymore. So I had to use SSH which was confusing but Jonas helped me.

The PI is Linux and doesn't have GitHub desktop support so I learned to use the terminal too.

3. Remote Desktop setup

I usually use DWservices which had PI support but it wasn't working at first because of XWayland. Fixed it using raspi-config.

4. Python and OpenCV

I has able to get a simple script with a virtual environment running pretty fast, thanks to the courses I had with Vitas last year.

I tested out an example of using color detection to activate buttons using OpenCV and I got it working but I feel like it wouldn't be reliable enough for use on my projects and it's still better to use real buttons.

There's also not enough space on the screen so if I were putting buttons there they would get activated by mistake.

However, the idea of adding storytelling or instructions on the projected image would still be a good idea and with shape detection like I tested I could detect when someone starts drawing.

5. Base onionskinning program for test day

I tried to make a program, it had to display the video stream and then pictures full screen. I did not succeed in doing that just with openCV, in the end, I used Pygame and some other things..

I had some difficulty coding at first but with that exercise, my skills got a lot better already.

### Things to watch out for

- Need to add zoom lenses or something to the camera so that in can be next to the projector. also will need a lot of fine-tuning.
- the code could be improved, made less resource-intensive, as the PI is having trouble.
- will need to add a blank screen when taking the pic
- gotta make the program to display the film
- i wanna add sound too

<br>

###### 2024-01-08

## Working script 1

#### (to display the pictures taken)

````

import cv2
import pygame
from pygame.locals import *
import os
import random

#how much time we give the pi to save the image
SaveDelay = 2000 # 2 seconds in milliseconds

# Use Pygame's clock to handle the timing
clock = pygame.time.Clock()
start_ticks = pygame.time.get_ticks()  # Starter tick

# Set the current working directory to the script's location
script_dir = os.path.dirname(os.path.abspath(__file__))
os.chdir(script_dir)

# Initialize Pygame
pygame.init()

# Set display size
screen_size = (0, 0)  # Set to (0, 0) for full screen
screen = pygame.display.set_mode(screen_size, pygame.FULLSCREEN)

# Get the current display info
screen_info = pygame.display.Info()
width = screen_info.current_w
height = screen_info.current_h

# Initialize the camera
cap = cv2.VideoCapture(0)  # Use 0 for the default camera

# Fetch the frame width and height
frame_width = cap.get(cv2.CAP_PROP_FRAME_WIDTH)
frame_height = cap.get(cv2.CAP_PROP_FRAME_HEIGHT)

# Calculate the ratio
ratio = frame_width / frame_height
new_width = int(height * ratio)

# Frame count initialization
frame_number = 0
# Generate a random integer from 1 to 10
rand_int = random.randint(1, 1000)
print(f"Random integer between 1 and 1000: {rand_int}")

# Create 'frames' directory if it doesn't exist
os.makedirs(f"frames{rand_int}")
frames_d = (f"frames{rand_int}")

y_key_pressed = False

frame_to_display = None

# Function to save the frame
def save_frame(image, directory=frames_d, prefix='frame', file_format='jpg'):
    global frame_number, frame_to_display  # Declare both as global
    filename = f"{prefix}_{frame_number}.{file_format}"
    filepath = os.path.join(directory, filename)
    cv2.imwrite(filepath, image)
    print(f"{filepath} Saved")
    frame_to_display = filepath
    frame_number += 1  # Increment the frame number

def play_vid(frame):
    frame = cv2.resize(frame, (new_width, height))
    img = cv2.cvtColor(frame, cv2.COLOR_BGR2RGB)
    img = pygame.surfarray.make_surface(img.swapaxes(0, 1))
    screen.blit(img, (0, 0))
    pygame.display.flip()
    print("playing video")

try:
    while True:
        seconds = (pygame.time.get_ticks() - start_ticks) / 1000
        image_loaded = False
        ret, frame = cap.read()

        # Handle events
        for event in pygame.event.get():
            if event.type == pygame.QUIT or (event.type == pygame.KEYDOWN and event.key == pygame.K_q):
                print("q to quit")
                raise StopIteration  # Break out of the loop

            # Check for 'y' key press to save the frame
            if event.type == pygame.KEYDOWN and event.key == pygame.K_y:
                print("key event detected")
                if not y_key_pressed:  # Check if the 'Y' key was not already pressed
                    screen.fill((255, 255, 255))
                    pygame.display.flip()  # Ensure the screen updates before capturing the frame
                    save_frame(frame)  # Save the frame with an auto-incremented number

                    # Delay before loading and displaying the image
                    save_delay_ticks = SaveDelay  
                    start_save_delay_ticks = pygame.time.get_ticks()

                    while pygame.time.get_ticks() - start_save_delay_ticks < save_delay_ticks:
                        pygame.event.pump()
                        clock.tick(60)

                    try:
                        image = pygame.image.load(frame_to_display)
                        print(frame_to_display + " loaded")
                        image = pygame.transform.scale(image, (new_width, height))
                        screen.blit(image, (0, 0))
                        pygame.display.flip()
                        image_loaded = True
                        print(frame_to_display + " displayed")

                    except Exception as e:
                        print(f"Failed to load image: {e}")

                    y_key_pressed = True  # Set the variable to True after the action

        if event.type == pygame.KEYUP and event.key == pygame.K_y:
            y_key_pressed = False  # Reset the variable when the 'Y' key is released

except StopIteration:
    pass  # Exit the loop when 'q' is pressed or the window is closed

finally:
    # Release resources
    pygame.quit()
    cap.release()
````

It seems that on the py it wasn't displaying the right picture because it was taking too much time to save on the drive, but I added a delay to give it some time.

### next

I still haven't scripted the video playback and at the end I'll have to reassign the buttons because right now it triggers with the keyboard.

to install to pi:

````
sudo pip3 install gpiozero
````

[this](https://www.makeuseof.com/tag/add-power-button-raspberry-pi/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't%252520get,GPIO%252520pins%25252039%252520and%25252040.)

````
$ sudo apt-get install python-rpi.gpio python3-rpi.gpi

````

````

sudo nano /boot/config.txt
````

There, find these lines:

````
#dtoverlay=gpio-ir,gpio_pin=17
#dtoverlay=gpio-ir-tx,gpio_pin=18
````

And uncomment only those lines to enable IR transmission:

````
dtoverlay=gpio-ir,gpio_pin=17
dtoverlay=gpio-ir-tx,gpio_pin=18
````

Now restart the Raspberry Pi by running `sudo reboot`.

````
sudo apt update
sudo apt install lirc -y
````

sudo nano /etc/lirc/lirc_options.conf

````
driver          = default
device          = /dev/lirc0
````

`sudo reboot` and after rebooting, check whether the LIRC daemon is running or not.

````
sudo /etc/init.d/lircd status
````

you will see you will see `**active (running)**`

pip install lirc

<br>

###### 2024-01-08

## GPIO mapping and Preview program

So this code works about the wiring is unstable on the buttons, I wanted to be able to unplug replug but that won't work

````
import cv2
import pygame
from pygame.locals import *
from gpiozero import Button
import RPi.GPIO as GPIO # Import Raspberry Pi GPIO library
import os
import random

GPIO.setmode(GPIO.BCM)     # set up BCM GPIO numbering  

GPIO.setup(17, GPIO.IN, pull_up_down=GPIO.PUD_UP)   # NEXT FRAME
GPIO.setup(22, GPIO.IN, pull_up_down=GPIO.PUD_UP)   # PREVIEW

GPIO.setup(21, GPIO.IN, pull_up_down=GPIO.PUD_UP)   # shutdown?

GPIO.setup(18, GPIO.OUT)   # output (LED)  WHITE
GPIO.setup(24, GPIO.OUT)    # RED
GPIO.setup(27, GPIO.OUT)    # YELLOW
GPIO.setup(23, GPIO.OUT)    # GREEN

GPIO.setup(16, GPIO.OUT) # IR 

# Initialize Pygame
pygame.init()

# LED ON yELLOW
GPIO.output(27,GPIO.HIGH) 

#how much time we give the pi to save the image
SaveDelay = 2000 # 2 seconds in milliseconds
VidFrameRate = 100

# Use Pygame's clock to handle the timing
clock = pygame.time.Clock()
start_ticks = pygame.time.get_ticks()  # Starter tick

# Set the current working directory to the script's location
script_dir = os.path.dirname(os.path.abspath(__file__))
os.chdir(script_dir)

# Set display size
screen_size = (0, 0)  # Set to (0, 0) for full screen
screen = pygame.display.set_mode(screen_size, pygame.FULLSCREEN)

# Get the current display info
screen_info = pygame.display.Info()
width = screen_info.current_w
height = screen_info.current_h

# Initialize the camera
cap = cv2.VideoCapture(0)  # Use 0 for the default camera

# Fetch the frame width and height
frame_width = cap.get(cv2.CAP_PROP_FRAME_WIDTH)
frame_height = cap.get(cv2.CAP_PROP_FRAME_HEIGHT)

# Calculate the ratio
ratio = frame_width / frame_height
new_width = int(height * ratio)

# Frame count initialization
frame_number = 0
preview_number = 0
# Generate a random integer from 1 to 10
rand_int = random.randint(1, 1000)
print(f"Random integer between 1 and 1000: {rand_int}")

# Create 'frames' directory if it doesn't exist
os.makedirs(f"frames{rand_int}")
frames_d = (f"frames{rand_int}")

y_key_pressed = False

frame_to_display = None
next_button_pressed = False
preview_button_pressed = False
filepath2 = None

# Function to save the frame
def save_frame(image, directory=frames_d, prefix='frame', file_format='jpg'):
    global frame_number, frame_to_display  # Declare both as global
    filename = f"{prefix}_{frame_number}.{file_format}"
    filepath = os.path.join(directory, filename)
    cv2.imwrite(filepath, image)
    print(f"{filepath} Saved")
    frame_to_display = filepath
    frame_number += 1  # Increment the frame number

#def play_vid(frame):
#   frame = cv2.resize(frame, (new_width, height))
#   img = cv2.cvtColor(frame, cv2.COLOR_BGR2RGB)
#   img = pygame.surfarray.make_surface(img.swapaxes(0, 1))
#   screen.blit(img, (0, 0))
#   pygame.display.flip()
#   print("playing video")

try:

    while True:
        seconds = (pygame.time.get_ticks() - start_ticks) / 1000
        image_loaded = False
        ret, frame = cap.read()

        # TEST
        if not GPIO.input(21): 
            print("black button is LOW (pressed), playing the next frame event as test")
            next_button_pressed = True

        # NEXT BUTTON
        if not GPIO.input(17): # if port 17 == 0  
            print("next frame button is LOW (pressed)")
            next_button_pressed = True
        # PREVIEW 
        if not GPIO.input(22): 
            print("preview button is LOW (pressed)")
            preview_button_pressed = True

        if next_button_pressed:

                screen.fill((255, 255, 255))
                pygame.display.flip()  # Ensure the screen updates before capturing the frame
                save_frame(frame)  # Save the frame with an auto-incremented number

                # Delay before loading and displaying the image
                save_delay_ticks = SaveDelay  
                start_save_delay_ticks = pygame.time.get_ticks()

                while pygame.time.get_ticks() - start_save_delay_ticks < save_delay_ticks:
                    pygame.event.pump()
                    clock.tick(60)

                try:
                    image = pygame.image.load(frame_to_display)
                    print(frame_to_display + " loaded")
                    image = pygame.transform.scale(image, (new_width, height))
                    screen.blit(image, (0, 0))
                    pygame.display.flip()
                    image_loaded = True
                    print(frame_to_display + " displayed")

                except Exception as e:
                    print(f"Failed to load image: {e}")
                
                # Delay before u can press the button again
                save_delay_ticks = SaveDelay  
                start_save_delay_ticks = pygame.time.get_ticks()
                while pygame.time.get_ticks() - start_save_delay_ticks < save_delay_ticks:
                    pygame.event.pump()
                    clock.tick(60)
                next_button_pressed = False  # Set the variable to True after the action

        # PREVIEW 
        if preview_button_pressed:

            filepath2 = os.path.join(frames_d, f"frame{preview_number}.jpg")
            image = pygame.image.load(filepath2)
            print(filepath2 + " loaded")
            image = pygame.transform.scale(image, (new_width, height))
            screen.blit(image, (0, 0))
            pygame.display.flip()
            image_loaded = True
            print(frame_to_display + " displayed")
            preview_number += 1
            VidFrameRate_ticks = VidFrameRate 
            start_VidFrameRate_ticks = pygame.time.get_ticks()
            while pygame.time.get_ticks() - start_VidFrameRate_ticks < VidFrameRate_ticks:
                pygame.event.pump()
                clock.tick(60)

            if preview_number > frame_number:
                preview_number = 0
                preview_button_pressed = False

        # Handle events
        for event in pygame.event.get():
            if event.type == pygame.QUIT or (event.type == pygame.KEYDOWN and event.key == pygame.K_q):
                print("q to quit")
                raise StopIteration  # Break out of the loop

            # Check for 'y' key press to save the frame
            if event.type == pygame.KEYDOWN and event.key == pygame.K_y:
                print("key event detected")
                if not y_key_pressed:  # Check if the 'Y' key was not already pressed
                    screen.fill((255, 255, 255))
                    pygame.display.flip()  # Ensure the screen updates before capturing the frame
                    save_frame(frame)  # Save the frame with an auto-incremented number

                    # Delay before loading and displaying the image
                    save_delay_ticks = SaveDelay  
                    start_save_delay_ticks = pygame.time.get_ticks()

                    while pygame.time.get_ticks() - start_save_delay_ticks < save_delay_ticks:
                        pygame.event.pump()
                        clock.tick(60)

                    try:
                        image = pygame.image.load(frame_to_display)
                        print(frame_to_display + " loaded")
                        image = pygame.transform.scale(image, (new_width, height))
                        screen.blit(image, (0, 0))
                        pygame.display.flip()
                        image_loaded = True
                        print(frame_to_display + " displayed")

                    except Exception as e:
                        print(f"Failed to load image: {e}")

                    y_key_pressed = True  # Set the variable to True after the action

            if event.type == pygame.KEYUP and event.key == pygame.K_y:
                y_key_pressed = False  # Reset the variable when the 'Y' key is released

except StopIteration:
    pass  # Exit the loop when 'q' is pressed or the window is closed

finally:
    # Release resources
    pygame.quit()
    cap.release()
    GPIO.cleanup()

````

###### 2024-01-13

## New cam new programe

Okay so we finally received the componants but when I replaced the usb cam by the PI cam 3 (because the other one couldnt do what i needed) I ran into a big problem : 

Pi cameras work very differantly, thought I needed picamera but it dont work so picamera2 but I couldnt install, saw its not compatible on some OS but then after 3 days fo debugging and trying things i finally got picamera 2 to work, turns out it doesnt work in a virtual enviroment so i switched to installing my pakages system wide and ran my script there.

Then It's a whole other libabry so I had to reado the code from scratch and AIs weren't much help because picamera2 is pretty recent so i had to go in and read the whole [doc](chrome-extension://efaidnbmnnnibpcajpcglclefindmkaj/https://datasheets.raspberrypi.com/camera/picamera2-manual.pdf)

after some trials, errors and lots of debugging i got that:

````
#!/usr/bin/python3

# Import necessary libraries
from picamera2 import Picamera2, Preview
import RPi.GPIO as GPIO
import os
import random
import time
import pygame
from pygame.locals import *

GPIO.setmode(GPIO.BCM)
GPIO.setup(17, GPIO.IN, pull_up_down=GPIO.PUD_UP)  # NEXT FRAME
GPIO.setup(22, GPIO.IN, pull_up_down=GPIO.PUD_UP)  # PREVIEW
GPIO.setup(21, GPIO.IN, pull_up_down=GPIO.PUD_UP)  # test/quit button
GPIO.setup(18, GPIO.OUT)  # output (LED)  WHITE
GPIO.setup(24, GPIO.OUT)  # RED
GPIO.setup(27, GPIO.OUT)  # YELLOW
GPIO.setup(23, GPIO.OUT)  # GREEN
GPIO.setup(16, GPIO.OUT)  # IR

# Initialize Pygame
pygame.init()
screen_size = (0, 0)  # Set to (0, 0) for full screen
screen = pygame.display.set_mode(screen_size, pygame.FULLSCREEN) # Set display size
screen_info = pygame.display.Info() # Get the current display info
width = screen_info.current_w
height = screen_info.current_h

# Create a Picamera2 instance
picam2 = Picamera2()
print("picam init")

zoom = 0.95 # copped image /1

# Set the current working directory to the script's location
script_dir = os.path.dirname(os.path.abspath(__file__))
os.chdir(script_dir)

# Generate a random integer from 1 to 1000
rand_int = random.randint(1, 1000)
print(f"Random integer between 1 and 1000: {rand_int}")

# Create 'frames' directory if it doesn't exist
os.makedirs(f"frames{rand_int}")
frames_d = (f"frames{rand_int}")

y_key_pressed = False
frame_to_display = None
next_button_pressed = False
preview_button_pressed = False
filepath = None
filepath2 = None

# Frame count initialization
frame_number = 0
preview_number = 0

preview_config = picam2.create_preview_configuration()
picam2.configure(preview_config)
picam2.start()
print("picam2 started")
# Wait for 2 seconds to allow the camera to initialize
time.sleep(2)

picam2.capture_metadata()
size = picam2.capture_metadata()['ScalerCrop'][2:]
full_res = picam2.camera_properties['PixelArraySize']
picam2.capture_metadata()
size = [int(s * zoom) for s in size]
offset = [(r - s) // 2 for r, s in zip(full_res, size)]
picam2.set_controls({"ScalerCrop": offset + size})

def save_frame(directory=frames_d, prefix='frame', file_format='jpg'):
    try:
        global frame_number, frame_to_display  # Declare both as global
        filename = f"{prefix}_{frame_number}.{file_format}"
        print(filename)
        filepath = os.path.join(directory, filename)
        print(filepath)
        screen.fill((255, 255, 255))
        picam2.capture_metadata()
        picam2.capture_file(filepath)
        frame_to_display = filepath
        frame_number += 1
        led_signal()
    except Exception as error:
        print(f"Failed to take and save frame: {error}")

def debounce(button_pin):
    time.sleep(0.05)  # Adjust the sleep time based on your requirements
    return GPIO.input(button_pin)

def LEDS_on():
    GPIO.output(18, GPIO.HIGH)
    GPIO.output(24, GPIO.HIGH)
    GPIO.output(27, GPIO.HIGH)
    GPIO.output(23, GPIO.HIGH)

def LEDS_off():
    GPIO.output(18, GPIO.LOW)
    GPIO.output(24, GPIO.LOW)
    GPIO.output(27, GPIO.LOW)
    GPIO.output(23, GPIO.LOW)

def led_signal():
    LEDS_off()
    time.sleep(0.05)
    LEDS_on()

screen.fill((200, 150, 250))
LEDS_on()
try:
    while True:
        pygame.display.flip()

        if not debounce(17):
            print("next button pressed")
            next_button_pressed = True
        
        if not debounce(21):
            print("exit button pressed")
            break

        if not debounce(22):
            print("preview button pressed")
            preview_button_pressed = True

        if next_button_pressed:
            print("next frame starts")
            try:
                screen.fill((255, 255, 255))
                save_frame()
            except Exception as next_frame_error:
                print(f"couldn't complete save_frame {next_frame_error}")
            try:
                if os.path.exists(frame_to_display):  # Checking for file existence outside the loop can speed things up significantly
                    try:
                        image = pygame.image.load(frame_to_display)
                        scaled_image = pygame.transform.scale(image, (width, height))
                        screen.blit(scaled_image, (0, 0)) 
                        pygame.display.flip()
                        led_signal()
                    
                    except Exception as load_error:
                        print(f"Failed to load image: {load_error}")
                    
            except Exception as file_error:
                print("Error occurred while loading image.")  # Use error handling to catch and report any issues smoothly.

            next_button_pressed = False

        if preview_button_pressed:
            print("preview starts")
            filepath2 = os.path.join(frames_d, f"frame_{preview_number}.jpg")
            preview_number += 1
            print(filepath2)
            if os.path.exists(filepath2):  # Checking for file existence outside the loop can speed up significantly
                try:
                    if not image is None and not image.get_rect().size == (0, 0):
                        image = pygame.image.load(filepath2)
                        scaled_image = pygame.transform.scale(image, (width, height))
                        print(filepath2 + " loaded")
                        screen.blit(scaled_image, (0, 0))
                        print(filepath2 + " displayed")
                        time.sleep(0.1)
                
                except Exception as file_error:
                    print("Error occurred while loading the image.")   # Use error handling to catch and report any issues smoothly.
          
            else:
                print("can't preview: Directory empty")
                preview_button_pressed = False

            if preview_number > frame_number:
                preview_number = 0
                preview_button_pressed = False

        for event in pygame.event.get():
            if event.type == pygame.QUIT or (event.type == pygame.KEYDOWN and event.key == pygame.K_q):
                led_signal()
                print("q to quit")
                break
            
            if event.type == pygame.KEYDOWN and event.key == pygame.K_y:
                print("y key event detected")
                if not y_key_pressed:
                    print("next frame triggered with y key")
                    next_button_pressed = True
                    y_key_pressed = True  # Set the variable to True after the action
                    
                if event.type == pygame.KEYUP and event.key == pygame.K_y:
                    y_key_pressed = False  # Reset the variable when the 'Y' key is released

finally:
    # Release resources
    GPIO.cleanup()
    picam2.stop()
    pygame.quit()
    quit()

````

<br>

###### 2024-01-16

## FINAL CODE

Added audio and fixed some stuff
````
#!/usr/bin/python3

# Import necessary libraries
from picamera2 import Picamera2, Preview
import RPi.GPIO as GPIO
import os
import random
import time
import pygame
from pygame.locals import *

zoom = 0.75 # copped image /1
offset_tweak_left = 195  # Change this value as needed
offset_tweak_top = -60  # Change this value as needed

GPIO.setmode(GPIO.BCM)
GPIO.setup(17, GPIO.IN, pull_up_down=GPIO.PUD_UP)  # NEXT FRAME
GPIO.setup(22, GPIO.IN, pull_up_down=GPIO.PUD_UP)  # PREVIEW
GPIO.setup(21, GPIO.IN, pull_up_down=GPIO.PUD_UP)  # test/quit button
GPIO.setup(18, GPIO.OUT)  # output (LED)  WHITE
GPIO.setup(24, GPIO.OUT)  # RED
GPIO.setup(27, GPIO.OUT)  # YELLOW
GPIO.setup(23, GPIO.OUT)  # GREEN
GPIO.setup(26, GPIO.OUT)  # big yellow
GPIO.setup(16, GPIO.OUT)  # IR

pygame.mixer.pre_init()
# Initialize Pygame
pygame.init()
screen_size = (0, 0)  # Set to (0, 0) for full screen
screen = pygame.display.set_mode(screen_size, pygame.FULLSCREEN) # Set display size
screen_info = pygame.display.Info() # Get the current display info
width = screen_info.current_w
height = screen_info.current_h

# Create a Picamera2 instance
picam2 = Picamera2()
print("picam init")

# Set the current working directory to the script's location
script_dir = os.path.dirname(os.path.abspath(__file__))
os.chdir(script_dir)

bell = pygame.mixer.Sound("samples/bell.mp3")
music = pygame.mixer.Sound("samples/music.mp3")
#pygame.mixer.Sound.play(bell)
#pygame.mixer.music.stop()
print("bell sound file path:", os.path.abspath("samples/bell.mp3"))
print("music sound file path:", os.path.abspath("samples/music.mp3"))
#pygame.mixer.Sound.play(music)
#pygame.mixer.music.stop()

# Generate a random integer from 1 to 1000
rand_int = random.randint(1, 1000)
print(f"Random integer between 1 and 1000: {rand_int}")

# Create 'frames' directory if it doesn't exist
os.makedirs(f"frames{rand_int}")
frames_d = (f"frames{rand_int}")

y_key_pressed = False
w_key_pressed = False
a_key_pressed = False
s_key_pressed = False
d_key_pressed = False
frame_to_display = None
next_button_pressed = False
preview_button_pressed = False
filepath = None
filepath2 = None

# Frame count initialization
frame_number = 0
preview_number = 0

preview_config = picam2.create_preview_configuration()
picam2.configure(preview_config)
picam2.start()
print("picam2 started")
# Wait for 2 seconds to allow the camera to initialize
time.sleep(2)

picam2.capture_metadata()
size = picam2.capture_metadata()['ScalerCrop'][2:]
full_res = picam2.camera_properties['PixelArraySize']
picam2.capture_metadata()
size = [int(s * zoom) for s in size]
#offset = [(r - s) // 2 for r, s in zip(full_res, size)]
#picam2.set_controls({"ScalerCrop": offset + size})

# Calculate offset based on the initial values
offset_width = (full_res[0] - size[0]) // 2 + offset_tweak_left
offset_height = (full_res[1] - size[1]) // 2 + offset_tweak_top

# Create a list with the individual offset values
offset = [offset_width, offset_height]
print(f"offset : {offset}")
# Set controls with individual offset values
picam2.set_controls({"ScalerCrop": offset + size})

def save_frame(directory=frames_d, prefix='frame', file_format='jpg'):
    try:
        global frame_number, frame_to_display  # Declare both as global
        filename = f"{prefix}_{frame_number}.{file_format}"
        print(filename)
        filepath = os.path.join(directory, filename)
        print(filepath)

        # Fill the screen with a white background
        screen.fill((255, 255, 255))
        pygame.display.flip()  # Update the display
        time.sleep(0.1)
        picam2.capture_metadata()
        screen.fill((255, 255, 255))
        pygame.display.flip()  # Update the display a second time
        time.sleep(0.1)
        picam2.capture_file(filepath)
        frame_to_display = filepath
        frame_number += 1
        led_signal()
    except Exception as error:
        print(f"Failed to take and save frame: {error}")

def debounce(button_pin):
    time.sleep(0.05)  # Adjust the sleep time based on your requirements
    return GPIO.input(button_pin)

def LEDS_on():
    GPIO.output(18, GPIO.HIGH)
    GPIO.output(24, GPIO.HIGH)
    GPIO.output(27, GPIO.HIGH)
    GPIO.output(23, GPIO.HIGH)
    GPIO.output(26, GPIO.HIGH)

def LEDS_off():
    GPIO.output(18, GPIO.LOW)
    GPIO.output(24, GPIO.LOW)
    GPIO.output(27, GPIO.LOW)
    GPIO.output(23, GPIO.LOW)
    GPIO.output(26, GPIO.LOW)

def led_signal():
    LEDS_off()
    time.sleep(0.05)
    LEDS_on()

screen.fill((200, 150, 250))
LEDS_on()
try:
    while True:
        pygame.display.flip()

        if not debounce(17):
            print("next button pressed")
            next_button_pressed = True
        
        if not debounce(21):
            print("exit button pressed")
            break

        if not debounce(22):
            print("preview button pressed")
            preview_button_pressed = True

        if next_button_pressed:
            print("next frame starts")
            try:
                pygame.mixer.Sound.play(bell)
            except Exception as e:
                print("Error playing sound:", e)
            try:
                save_frame()
            except Exception as next_frame_error:
                print(f"couldn't complete save_frame {next_frame_error}")
            try:
                if os.path.exists(frame_to_display):  # Checking for file existence outside the loop can speed things up significantly
                    try:
                        image = pygame.image.load(frame_to_display)
                        scaled_image = pygame.transform.scale(image, (width, height))
                        screen.blit(scaled_image, (0, 0)) 
                        pygame.display.flip()

                    except Exception as load_error:
                        print(f"Failed to load image: {load_error}")
                    
            except Exception as file_error:
                print("Error occurred while loading image.")  # Use error handling to catch and report any issues smoothly.

            led_signal()
            next_button_pressed = False

        if preview_button_pressed:
            print("preview starts")
            try:
                pygame.mixer.Sound.play(music)
            except Exception as e:
                print("Error playing sound:", e)
            filepath2 = os.path.join(frames_d, f"frame_{preview_number}.jpg")
            preview_number += 1
            print(filepath2)
            if os.path.exists(filepath2):  # Checking for file existence outside the loop can speed up significantly
                try:
                    if not image is None and not image.get_rect().size == (0, 0):
                        image = pygame.image.load(filepath2)
                        scaled_image = pygame.transform.scale(image, (width, height))
                        print(filepath2 + " loaded")
                        screen.blit(scaled_image, (0, 0))
                        print(filepath2 + " displayed")
                        time.sleep(0.1)
                
                except Exception as file_error:
                    print("Error occurred while loading the image.")   # Use error handling to catch and report any issues smoothly.
          
            else:
                print("can't preview: Directory empty")
                preview_button_pressed = False

            if preview_number > (frame_number - 1):
                preview_number = 0
                pygame.mixer.sound.stop(music)
                preview_button_pressed = False

            if preview_number > 50:
                preview_number = 0
                pygame.mixer.sound.stop()
                preview_button_pressed = False

        for event in pygame.event.get():
            if event.type == pygame.QUIT or (event.type == pygame.KEYDOWN and event.key == pygame.K_q):
                led_signal()
                print("q to quit")
                break
            
            if event.type == pygame.KEYDOWN and event.key == pygame.K_y:
                print("y key event detected")
                if not y_key_pressed:
                    print("next frame triggered with y key")
                    next_button_pressed = True
                    y_key_pressed = True  # Set the variable to True after the action
                    
                if event.type == pygame.KEYUP and event.key == pygame.K_y:
                    y_key_pressed = False  # Reset the variable when the 'Y' key is released
            
            if event.type == pygame.KEYDOWN and event.key == pygame.K_w:
                if not w_key_pressed:
                    print("up")
                    #offset_tweak_left = 320  # Change this value as needed
                    offset_tweak_top += 2

                    print(f": {offset_tweak_top}")
                    w_key_pressed = True  # Set the variable to True after the actio
                if event.type == pygame.KEYUP and event.key == pygame.K_w:
                    w_key_pressed = False  # Reset the variable when the 'Y' key is released

            if event.type == pygame.KEYDOWN and event.key == pygame.K_a:
                if not a_key_pressed:
                    print("left")
                    offset_tweak_left += 2  # Change this value as needed
       
                    print(f"left: {offset_tweak_left}")
                    a_key_pressed = True  # Set the variable to True after the actio
                if event.type == pygame.KEYUP and event.key == pygame.K_a:
                    a_key_pressed = False  # Reset the variable when the 'Y' key is released

            if event.type == pygame.KEYDOWN and event.key == pygame.K_d:
                if not d_key_pressed:
                    print("right")
                    offset_tweak_left -= 2 # Change this value
    
                    print(f"left: {offset_tweak_left}")
                    d_key_pressed = True  # Set the variable to True after the actio
                if event.type == pygame.KEYUP and event.key == pygame.K_d:
                    d_key_pressed = False  # Reset the variable when the 'Y' key is released

            if event.type == pygame.KEYDOWN and event.key == pygame.K_s:
                if not s_key_pressed:
                    print("down")
                    #offset_tweak_left -= 2 # Change this value
                    offset_tweak_top -= 2

                    print(offset_tweak_top)
                    s_key_pressed = True  # Set the variable to True after the actio
                if event.type == pygame.KEYUP and event.key == pygame.K_s:
                    s_key_pressed = False  # Reset the variable when the 'Y' key is released

except KeyboardInterrupt:
    pass  # Handle the Ctrl+C interrupt to gracefully exit the program

finally:
    # Release resources
    pygame.mixer.quit()
    GPIO.cleanup()
    picam2.stop()
    pygame.quit()
    quit()

````

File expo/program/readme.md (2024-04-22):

Original python code:

````
#!/usr/bin/python3

# Import necessary libraries
from picamera2 import Picamera2, Preview
import RPi.GPIO as GPIO
import os
import random
import time
import pygame
from pygame.locals import *

# Tweaking variables
zoom = 0.75
offset_tweak_left = 185 
offset_tweak_top = -10

# Initialize GPIO settings
GPIO.setmode(GPIO.BCM)
# Define GPIO pins for buttons and LEDs
GPIO.setup(17, GPIO.IN, pull_up_down=GPIO.PUD_UP)  # NEXT FRAME button
GPIO.setup(22, GPIO.IN, pull_up_down=GPIO.PUD_UP)  # PREVIEW button
GPIO.setup(21, GPIO.IN, pull_up_down=GPIO.PUD_UP)  # test/quit button
# Define GPIO pins for LEDs
GPIO.setup(18, GPIO.OUT)  # WHITE LED
GPIO.setup(24, GPIO.OUT)  # RED LED
GPIO.setup(27, GPIO.OUT)  # YELLOW LED
GPIO.setup(23, GPIO.OUT)  # GREEN LED
GPIO.setup(26, GPIO.OUT)  # BIG YELLOW LED
GPIO.setup(16, GPIO.OUT)  # IR LED

# Initialize Pygame
pygame.mixer.pre_init()
pygame.init()

# Get screen dimensions
screen_size = (0, 0)
screen = pygame.display.set_mode(screen_size, pygame.FULLSCREEN)
screen_info = pygame.display.Info()
width = screen_info.current_w
height = screen_info.current_h

# Initialize Picamera2
picam2 = Picamera2()
print("picam init")

# Set the current working directory to the script's location
script_dir = os.path.dirname(os.path.abspath(__file__))
os.chdir(script_dir)

# Load sound files
bell = pygame.mixer.Sound("samples/bell.mp3")
music = pygame.mixer.Sound("samples/music.mp3")
print("bell sound file path:", os.path.abspath("samples/bell.mp3"))
print("music sound file path:", os.path.abspath("samples/music.mp3"))

# Generate a random directory name for frames
rand_int = random.randint(1, 1000)
print(f"Random integer between 1 and 1000: {rand_int}")
os.makedirs(f"frames{rand_int}")
frames_d = (f"frames{rand_int}")

# Initialize key press flags
y_key_pressed = False
w_key_pressed = False
a_key_pressed = False
s_key_pressed = False
d_key_pressed = False

# Initialize frame numbers
frame_number = 0
preview_number = 0

# Configure Picamera2 preview
preview_config = picam2.create_preview_configuration()
picam2.configure(preview_config)
picam2.start()
print("picam2 started")
time.sleep(2)  # Wait for 2 seconds to allow the camera to initialize

# Capture metadata to determine image size
picam2.capture_metadata()
size = picam2.capture_metadata()['ScalerCrop'][2:]
full_res = picam2.camera_properties['PixelArraySize']
size = [int(s * zoom) for s in size]

# Calculate offset
offset_width = (full_res[0] - size[0]) // 2 + offset_tweak_left
offset_height = (full_res[1] - size[1]) // 2 + offset_tweak_top
offset = [offset_width, offset_height]
print(f"offset : {offset}")
picam2.set_controls({"ScalerCrop": offset + size})

# Function to save a frame
def save_frame(directory=frames_d, prefix='frame', file_format='jpg'):
    try:
        global frame_number, frame_to_display
        filename = f"{prefix}_{frame_number}.{file_format}"
        filepath = os.path.join(directory, filename)
        screen.fill((255, 255, 255))
        pygame.display.flip()
        time.sleep(0.1)
        picam2.capture_metadata()
        screen.fill((255, 255, 255))
        pygame.display.flip()
        time.sleep(0.1)
        picam2.capture_file(filepath)
        frame_to_display = filepath
        frame_number += 1
        led_signal()
    except Exception as error:
        print(f"Failed to take and save frame: {error}")

# Function to debounce button presses
def debounce(button_pin):
    time.sleep(0.05)
    return GPIO.input(button_pin)

# Functions to control LEDs
def LEDS_on():
    GPIO.output(18, GPIO.HIGH)
    GPIO.output(24, GPIO.HIGH)
    GPIO.output(27, GPIO.HIGH)
    GPIO.output(23, GPIO.HIGH)
    GPIO.output(26, GPIO.HIGH)

def LEDS_off():
    GPIO.output(18, GPIO.LOW)
    GPIO.output(24, GPIO.LOW)
    GPIO.output(27, GPIO.LOW)
    GPIO.output(23, GPIO.LOW)
    GPIO.output(26, GPIO.LOW)

# Function to flash LEDs
def led_signal():
    LEDS_off()
    time.sleep(0.05)
    LEDS_on()

# Hide the mouse cursor
pygame.mouse.set_visible(False)
screen.fill((200, 150, 250))
LEDS_on()

try:
    while True:
        pygame.display.flip()

        # Check button presses
        if not debounce(17):
            next_button_pressed = True
        if not debounce(21):
            break
        if not debounce(22):
            preview_button_pressed = True

        # Handle next button press
        if next_button_pressed:
            pygame.mixer.Sound.play(bell)
            save_frame()
            if os.path.exists(frame_to_display):
                try:
                    image = pygame.image.load(frame_to_display)
                    scaled_image = pygame.transform.scale(image, (width, height))
                    screen.blit(scaled_image, (0, 0))
                    pygame.display.flip()
                except Exception as load_error:
                    print(f"Failed to load image: {load_error}")
            led_signal()
            next_button_pressed = False

        # Handle preview button press
        if preview_button_pressed:
            pygame.mixer.Sound.play(music)
            filepath2 = os.path.join(frames_d, f"frame_{preview_number}.jpg")
            preview_number += 1
            if os.path.exists(filepath2):
                try:
                    image = pygame.image.load(filepath2)
                    scaled_image = pygame.transform.scale(image, (width, height))
                    screen.blit(scaled_image, (0, 0))
                    pygame.display.flip()
                    time.sleep(0.1)
                except Exception as file_error:
                    print("Error occurred while loading the image.")
            else:
                print("can't preview: Directory empty")
                preview_button_pressed = False
            if preview_number == frame_number or preview_number == 50:
                preview_number = 0
                pygame.mixer.stop()
                preview_button_pressed = False

        # Event handling
        for event in pygame.event.get():
            if event.type == pygame.QUIT or (event.type == pygame.KEYDOWN and event.key == pygame.K_q):
                break
            if event.type == pygame.KEYDOWN and event.key == pygame.K_y:
                if not y_key_pressed:
                    next_button_pressed = True
                    y_key_pressed = True
                if event.type == pygame.KEYUP and event.key == pygame.K_y:
                    y_key_pressed = False
            if event.type == pygame.KEYDOWN and event.key == pygame.K_w:
                if not w_key_pressed:
                    offset_tweak_top += 2
                    w_key_pressed = True
                if event.type == pygame.KEYUP and event.key == pygame.K_w:
                    w_key_pressed = False
            if event.type == pygame.KEYDOWN and event.key == pygame.K_a:
                if not a_key_pressed:
                    offset_tweak_left += 2
                    a_key_pressed = True
                if event.type == pygame.KEYUP and event.key == pygame.K_a:
                    a_key_pressed = False
            if event.type == pygame.KEYDOWN and event.key == pygame.K_d:
                if not d_key_pressed:
                    offset_tweak_left -= 2
                    d_key_pressed = True
                if event.type == pygame.KEYUP and event.key == pygame.K_d:
                    d_key_pressed = False
            if event.type == pygame.KEYDOWN and event.key == pygame.K_s:
                if not s_key_pressed:
                    offset_tweak_top -= 2
                    s_key_pressed = True
                if event.type == pygame.KEYUP and event.key == pygame.K_s:
                    s_key_pressed = False

except KeyboardInterrupt:
    pass

finally:
    # Cleanup and exit
    pygame.mixer.quit()
    GPIO.cleanup()
    picam2.stop()
    pygame.quit()
    quit()

````

to control usb:

````
import uhubctl

hubs = uhubctl.discover_hubs()

for hub in hubs:
    print(f"Found hub: {hub}")

    for port in hub.ports:
        print(f"   Found port: {port}")
        
        # You can use the optional argument `cached_results=False` for each of 
        # these 3 methods in order to invalidate the internal cache,
        # which is used for performance reasons
        print(f"      Description: {port.description()}")
        print(f"      Vendor ID: {port.vendor_id()}")
        print(f"      Product ID: {port.product_id()}")
````

[https://github.com/nbuchwitz/python3-uhubctl](https://github.com/nbuchwitz/python3-uhubctl)

````
from uhubctl import Hub, Port

hub = Hub("1-1")
port = hub.add_port(1)

print("Switch port 1-1.1 off")
port.status = False

print("Switch port 1-1.1 on")
port.status = True

print("Get port 1-1.1 status")
print(port.status)
````

add "move the house !" frame

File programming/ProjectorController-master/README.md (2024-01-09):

# ProjectorController

ProjectorController is a CLI written in Python which eases communication with Christie Digital® projectors supporting TCP/IP serial commands.

## Usage

**Note:** This software can currently only be used as a standalone tool - API is coming soon.

- For Windows users, execute `./windows/run.bat`

- For Unix users, execute `./unix/run.sh`

Afterwards, just follow the on-screen instructions. For help, type `-h` or `--help` on the command line.

## Contributing

Pull requests are welcome. For major changes or feature requests, please open an issue first to discuss your needs.

## License

This project is licensed under the terms of the [GNU General Public License Version 3](https://www.gnu.org/licenses/gpl-3.0.en.html) for non-commercial use only.

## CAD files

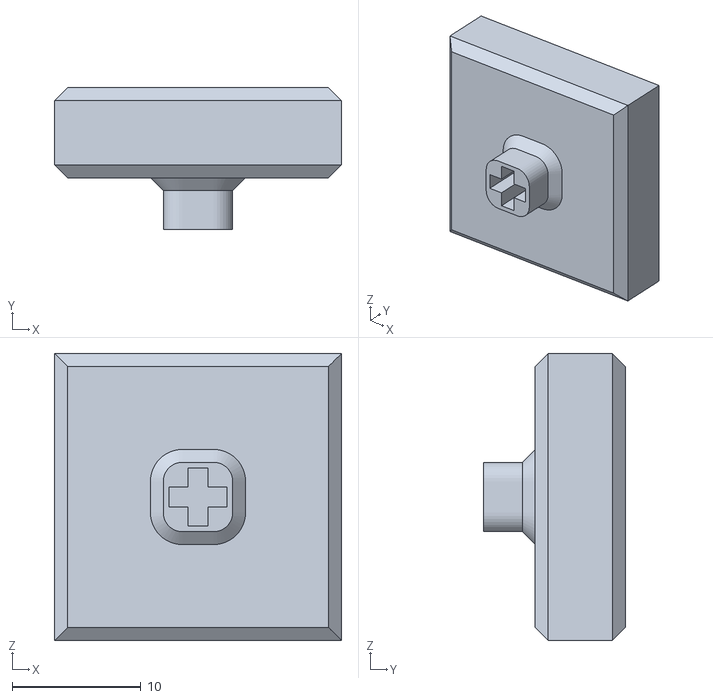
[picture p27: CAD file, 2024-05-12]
expo/3d/button_v6.stl
22.3 x 11.0 x 22.3

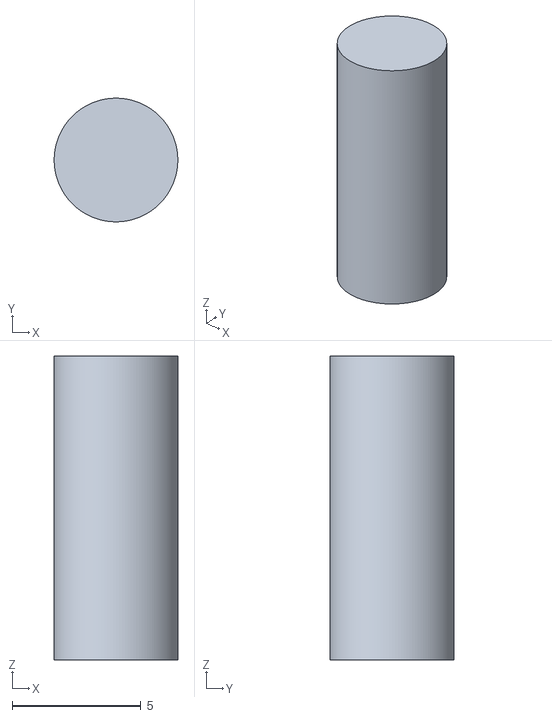
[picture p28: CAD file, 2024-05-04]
expo/3d/roueroulement.stl
4.80 x 4.80 x 11.8

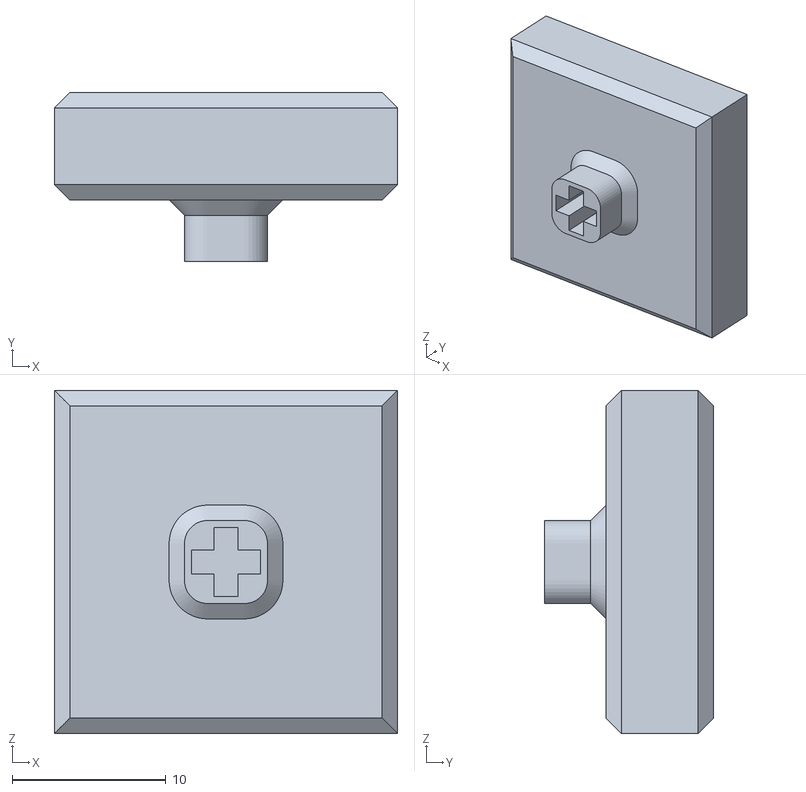
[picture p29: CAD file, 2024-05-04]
expo/3d/buttonv5.stl
22.3 x 11.0 x 22.3

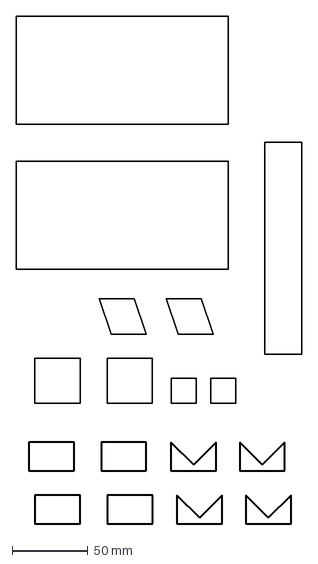
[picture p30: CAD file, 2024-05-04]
expo/3d/cnc-4mm.dxf
188.6 x 335.7 mm

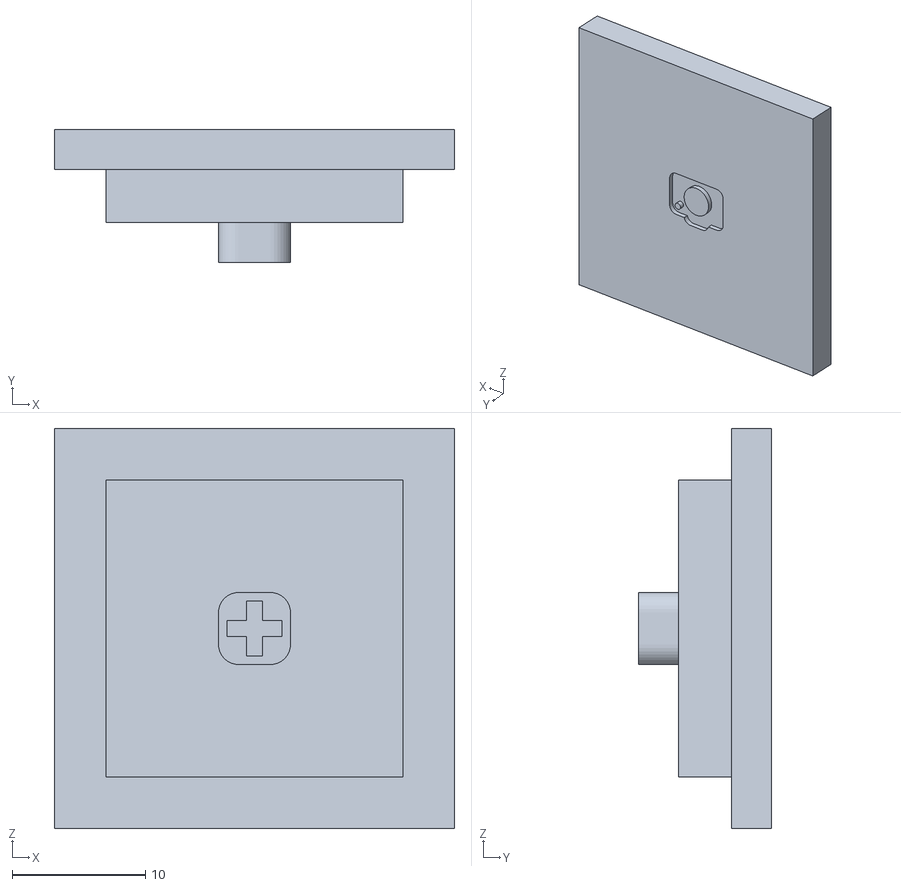
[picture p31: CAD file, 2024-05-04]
expo/3d/buttonv1.stl
30.0 x 10.0 x 30.0

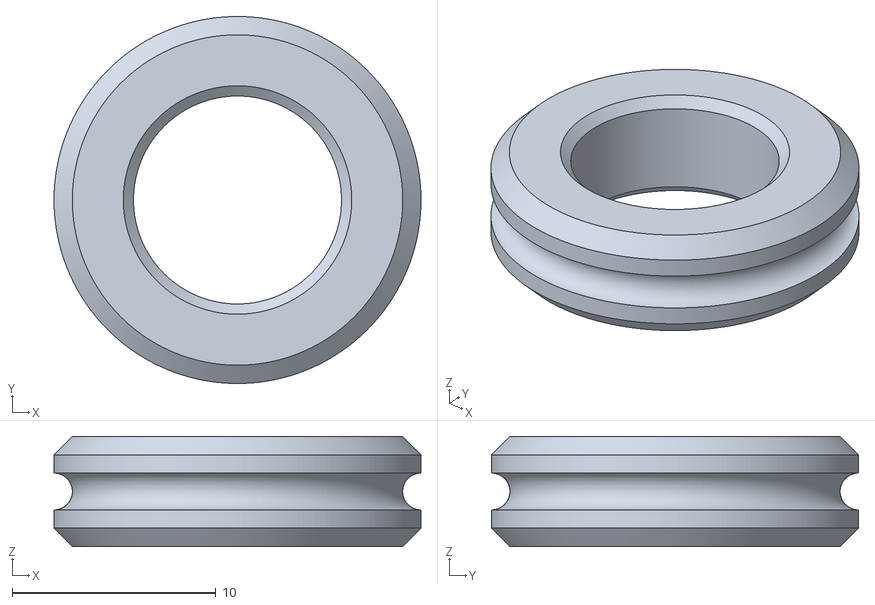
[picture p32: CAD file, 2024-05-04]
expo/3d/roue.stl
18.0 x 18.0 x 5.40

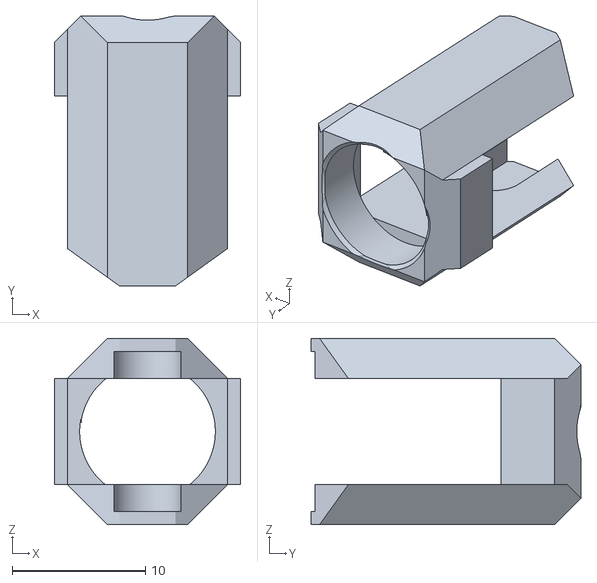
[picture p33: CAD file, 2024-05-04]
expo/3d/roueholder.stl
14.0 x 20.3 x 14.0

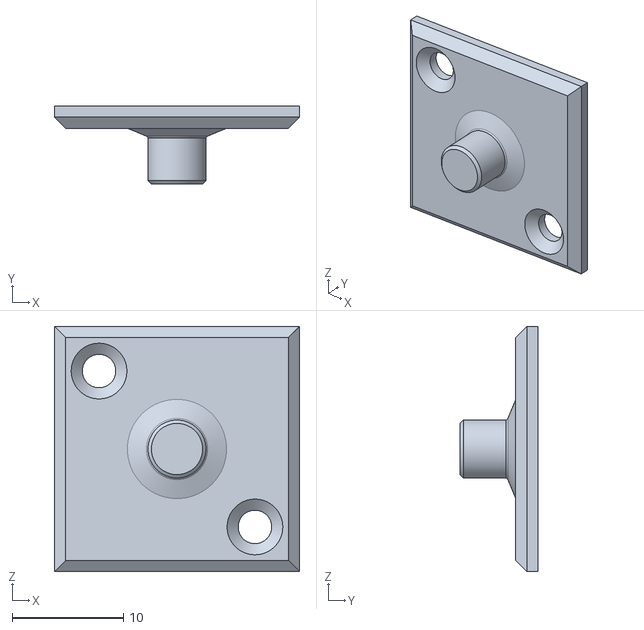
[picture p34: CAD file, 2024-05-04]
expo/3d/rouetop.stl
22.0 x 7.00 x 22.0

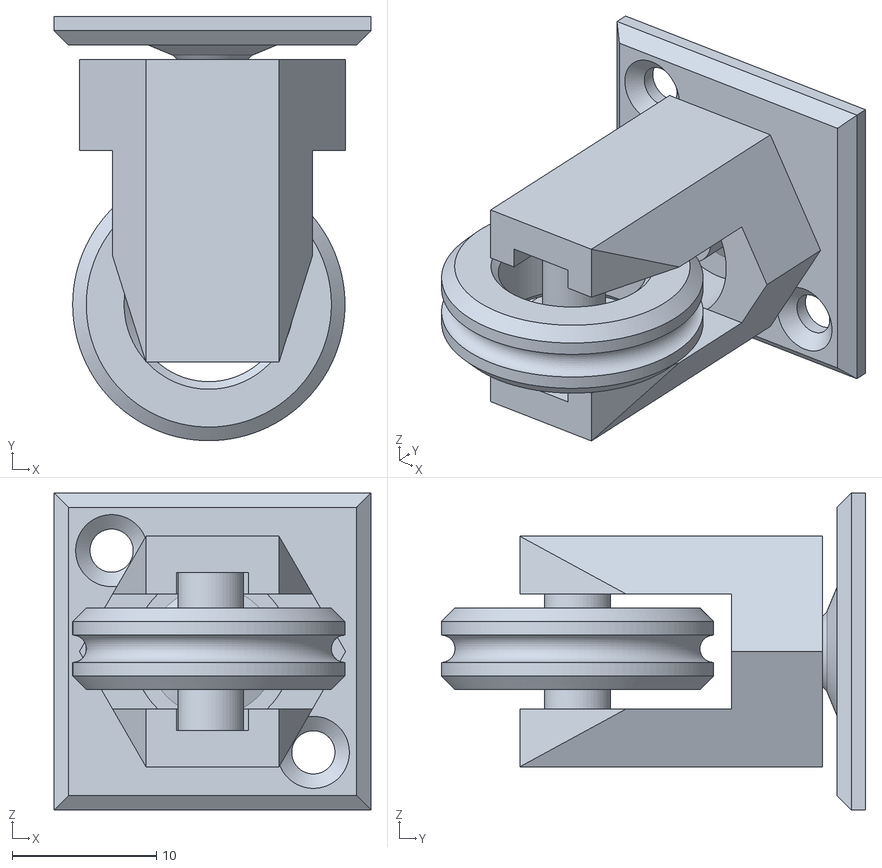
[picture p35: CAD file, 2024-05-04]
expo/3d/roues v4.stl
22.0 x 29.4 x 22.0

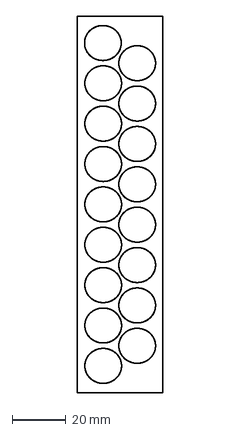
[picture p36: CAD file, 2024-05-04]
expo/3d/round.dxf
31.6 x 140.0 mm

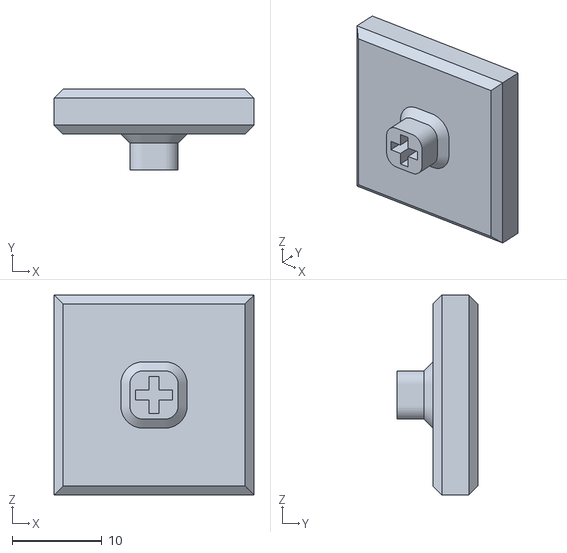
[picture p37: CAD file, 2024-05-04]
expo/3d/buttonv2.stl
22.3 x 9.00 x 22.3

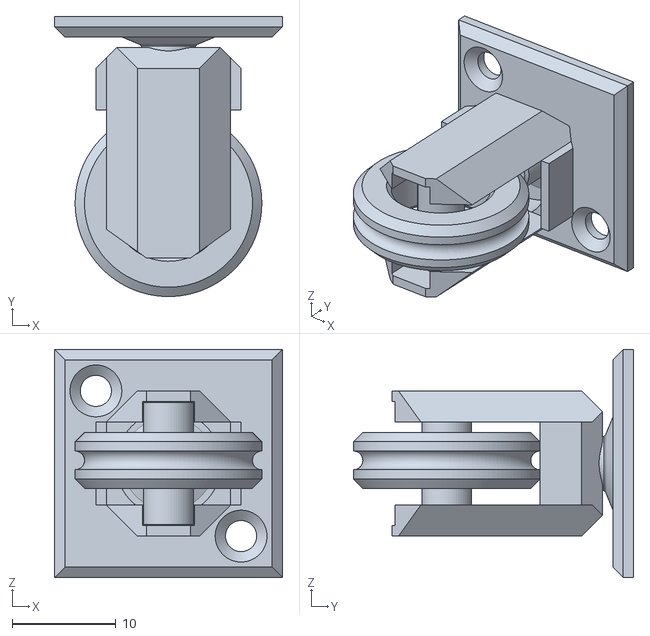
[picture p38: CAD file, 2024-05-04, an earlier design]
expo/3d/roues v3.stl
22.0 x 27.0 x 22.0

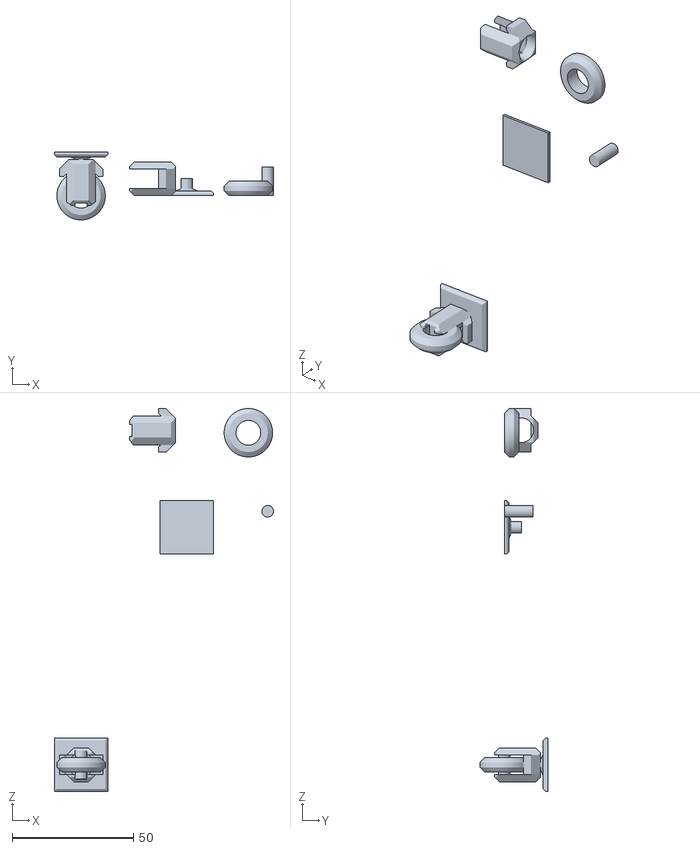
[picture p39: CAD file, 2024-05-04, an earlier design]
expo/3d/roues v2.stl
90.4 x 28.0 x 158.0

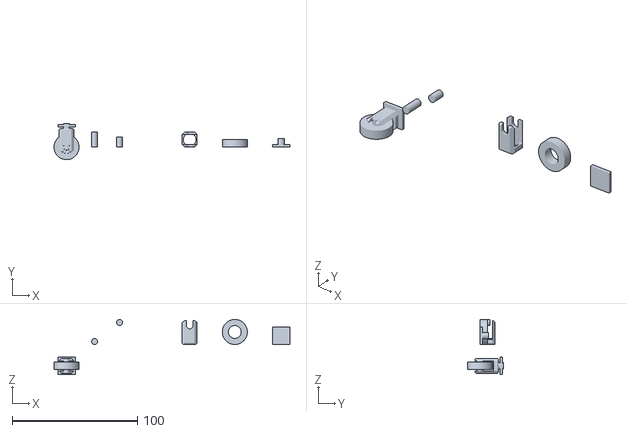
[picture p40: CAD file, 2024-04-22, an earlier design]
expo/3d/roues.stl
188.2 x 29.0 x 44.0

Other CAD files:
expo/3d/2024-03-20-magic-house.f3d
expo/3d/button v6.f3d
object/360-tests/cat v1.f3d
object/360-tests/form 8 v3.f3d
object/360-tests/form 9 v6.f3d
object/360-tests/form10 v5.f3d
object/360-tests/test_1 v3.f3d
object/360-tests/test_3 v2.f3d
object/360-tests/test_4 v1.f3d
object/360-tests/test_5 v1.f3d
object/360-tests/test_6 v2.f3d
object/360-tests/test_7 v2.f3d
object/export/Lauren_Thiel_animation_studio.f3d

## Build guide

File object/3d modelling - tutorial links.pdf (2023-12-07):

## YouTube Tutorials, Links

## Fusion 360

Autodesk Fusion 360 tutorial playlist (https://www.youtube.com/playlist?list=PLrZ2zKOtC_-C4rWfapgngoe9o2-ng8ZBr)

Demo Laure - Pencil Sharpener 2021 (https://www.youtube.com/watch?v=RM_Z7DA7P8E) Demo Laure -Soap Dispenser 2021 (https://youtu.be/NpFWygMTq0M?si=OqvVUuQTwHSrIGBs) Demo Laure -Tape Dispenser 2021 (https://youtu.be/iOxGRvAEJWI?si=wYyl5FscbPP_DP4v)

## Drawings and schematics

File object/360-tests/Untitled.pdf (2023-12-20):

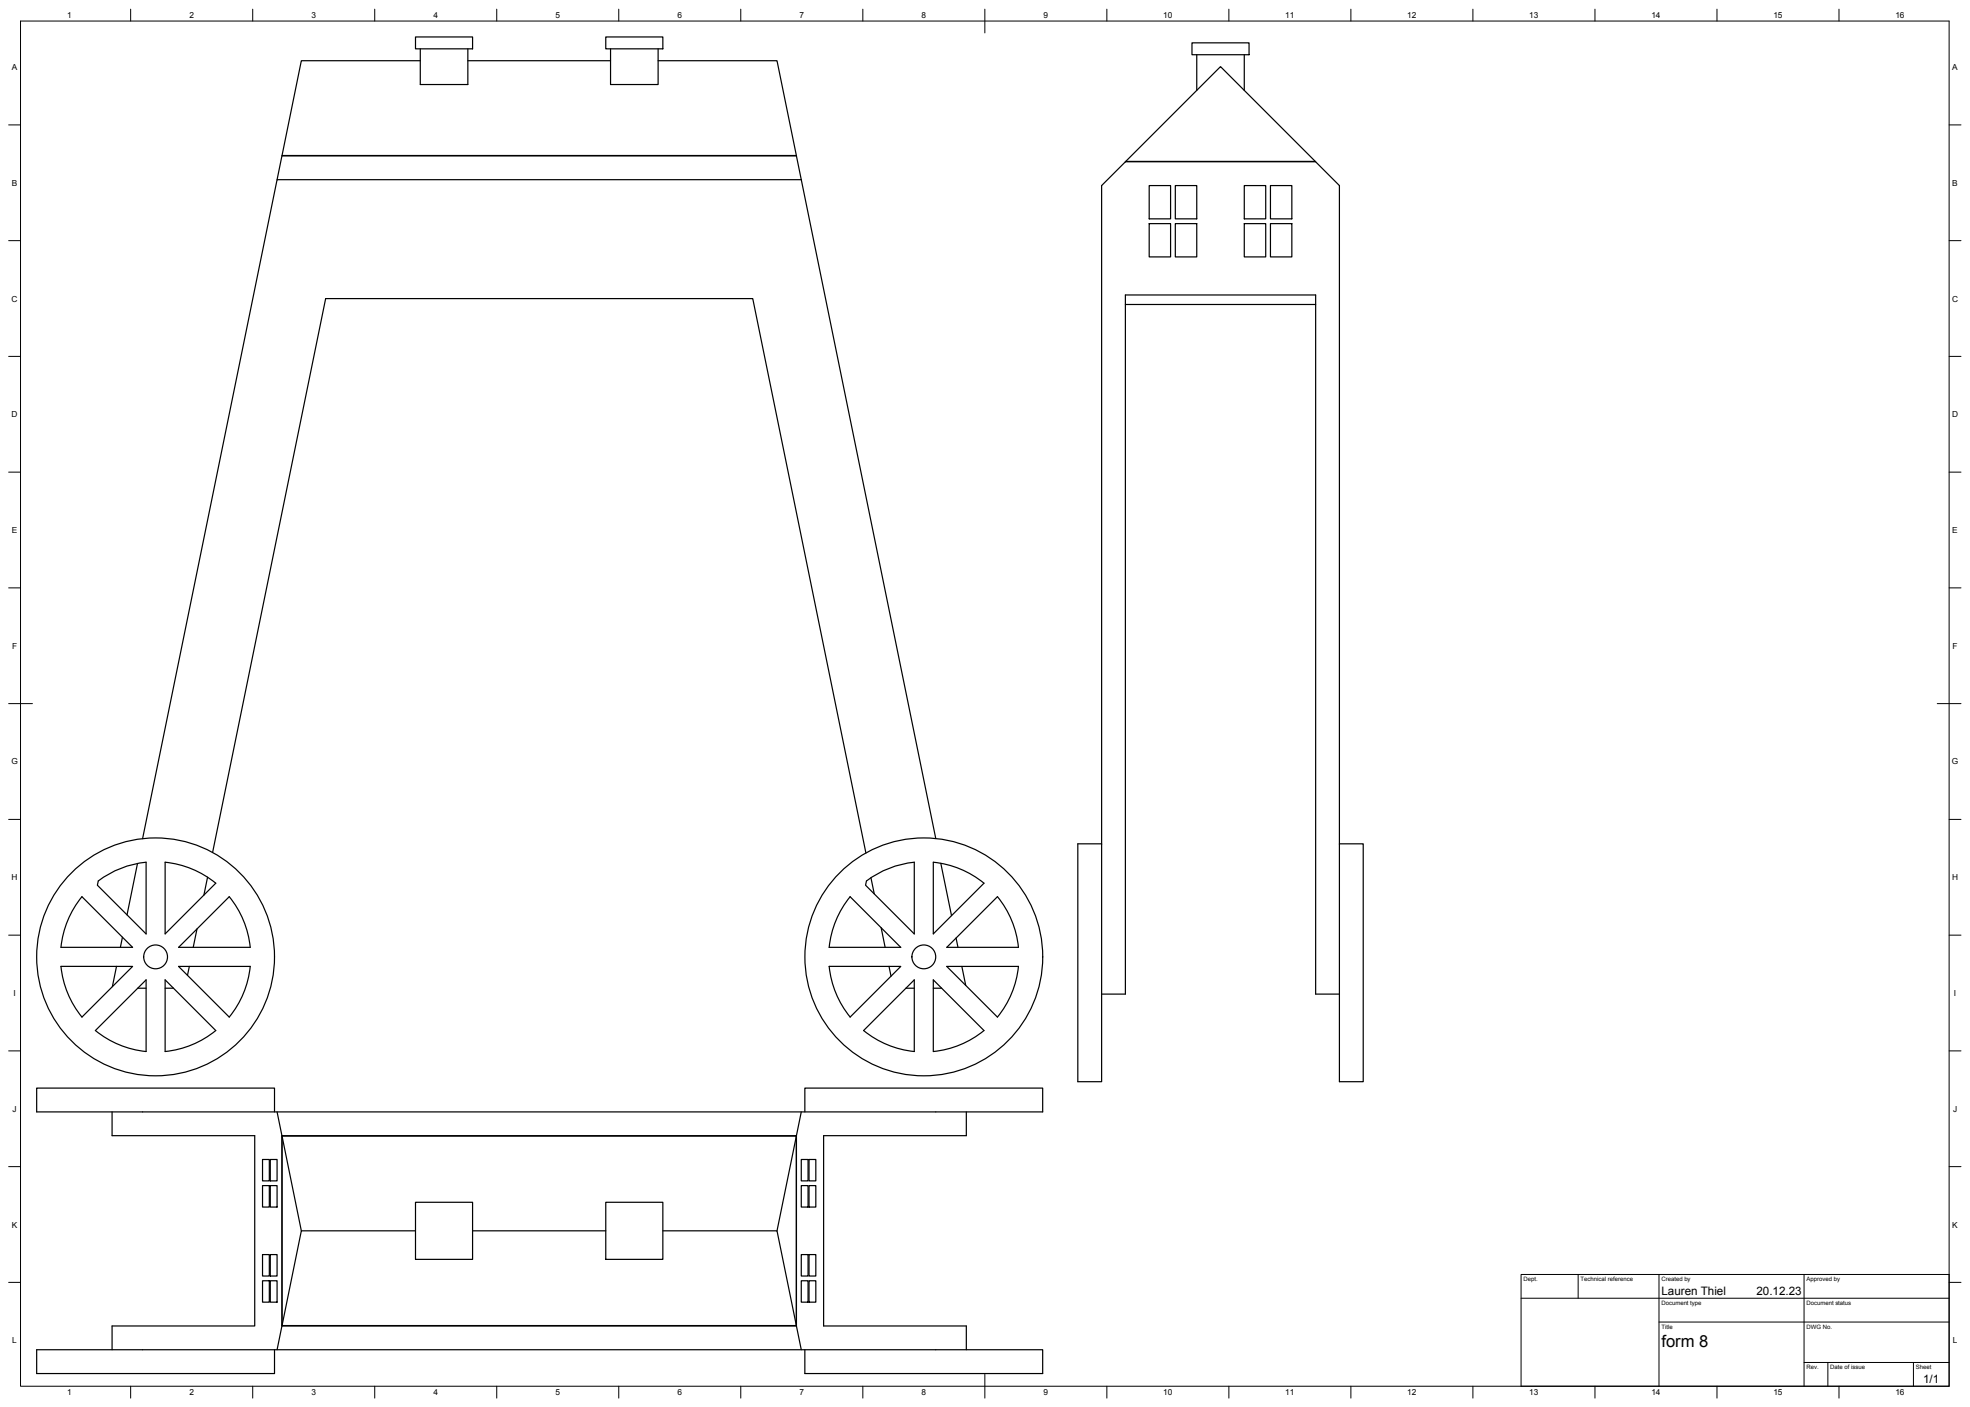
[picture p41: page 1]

Dept. | Technical reference | Created by Lauren Thiel 20.12.23 | Approved by

Document type | Document status

Title form 8 | DWG No.

Rev. | Date of issue | Sheet 1/1

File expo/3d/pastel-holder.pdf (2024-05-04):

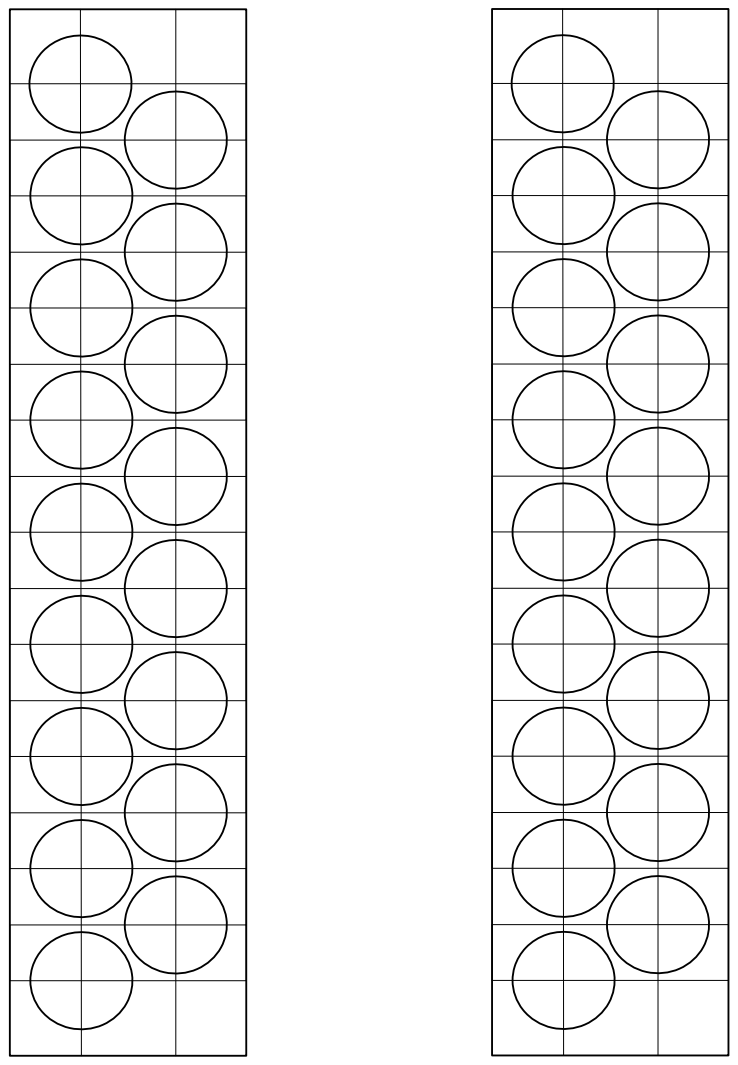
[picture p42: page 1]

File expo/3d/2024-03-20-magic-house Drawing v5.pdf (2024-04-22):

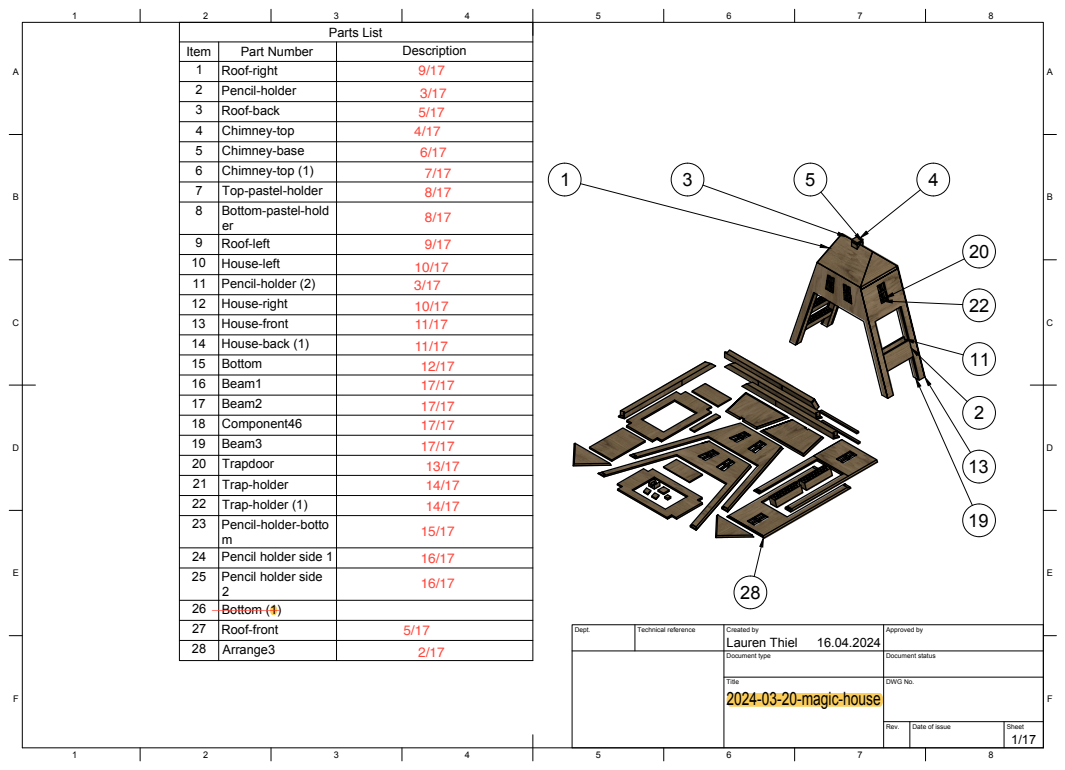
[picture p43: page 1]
8 BCDEF; ABCDEF; Title; DWG No.; Rev.; Date of issue; Sheet; Parts List; Item; Part Number; Description 1; Roof-right 2; Pencil-holder 3; Roof-back 4; Chimney-top 5; Chimney-base 6; Chimney-top (1) 7; Top-pastel-holder 8; Bottom-pastel-hold

Roof-left er 9

10 | House-left
11 | Pencil-holder (2)
12 | House-right
13 | House-front
14 | House-back (1)
15 | Bottom
16 | Beam1
17 | Beam2
18 | Component46
19 | Beam3
20 | Trapdoor
21 | Trap-holder
22 | Trap-holder (1)
23 | Pencil-holder-botto m

24 | Pencil holder side 1
25 | Pencil holder side 2

26 | Bottom (1)
27 | Roof-front
28 | Arrange3

Dept. | Technical reference | Created by Lauren Thiel 16.04.2024 | Approved by

Document type | Document status

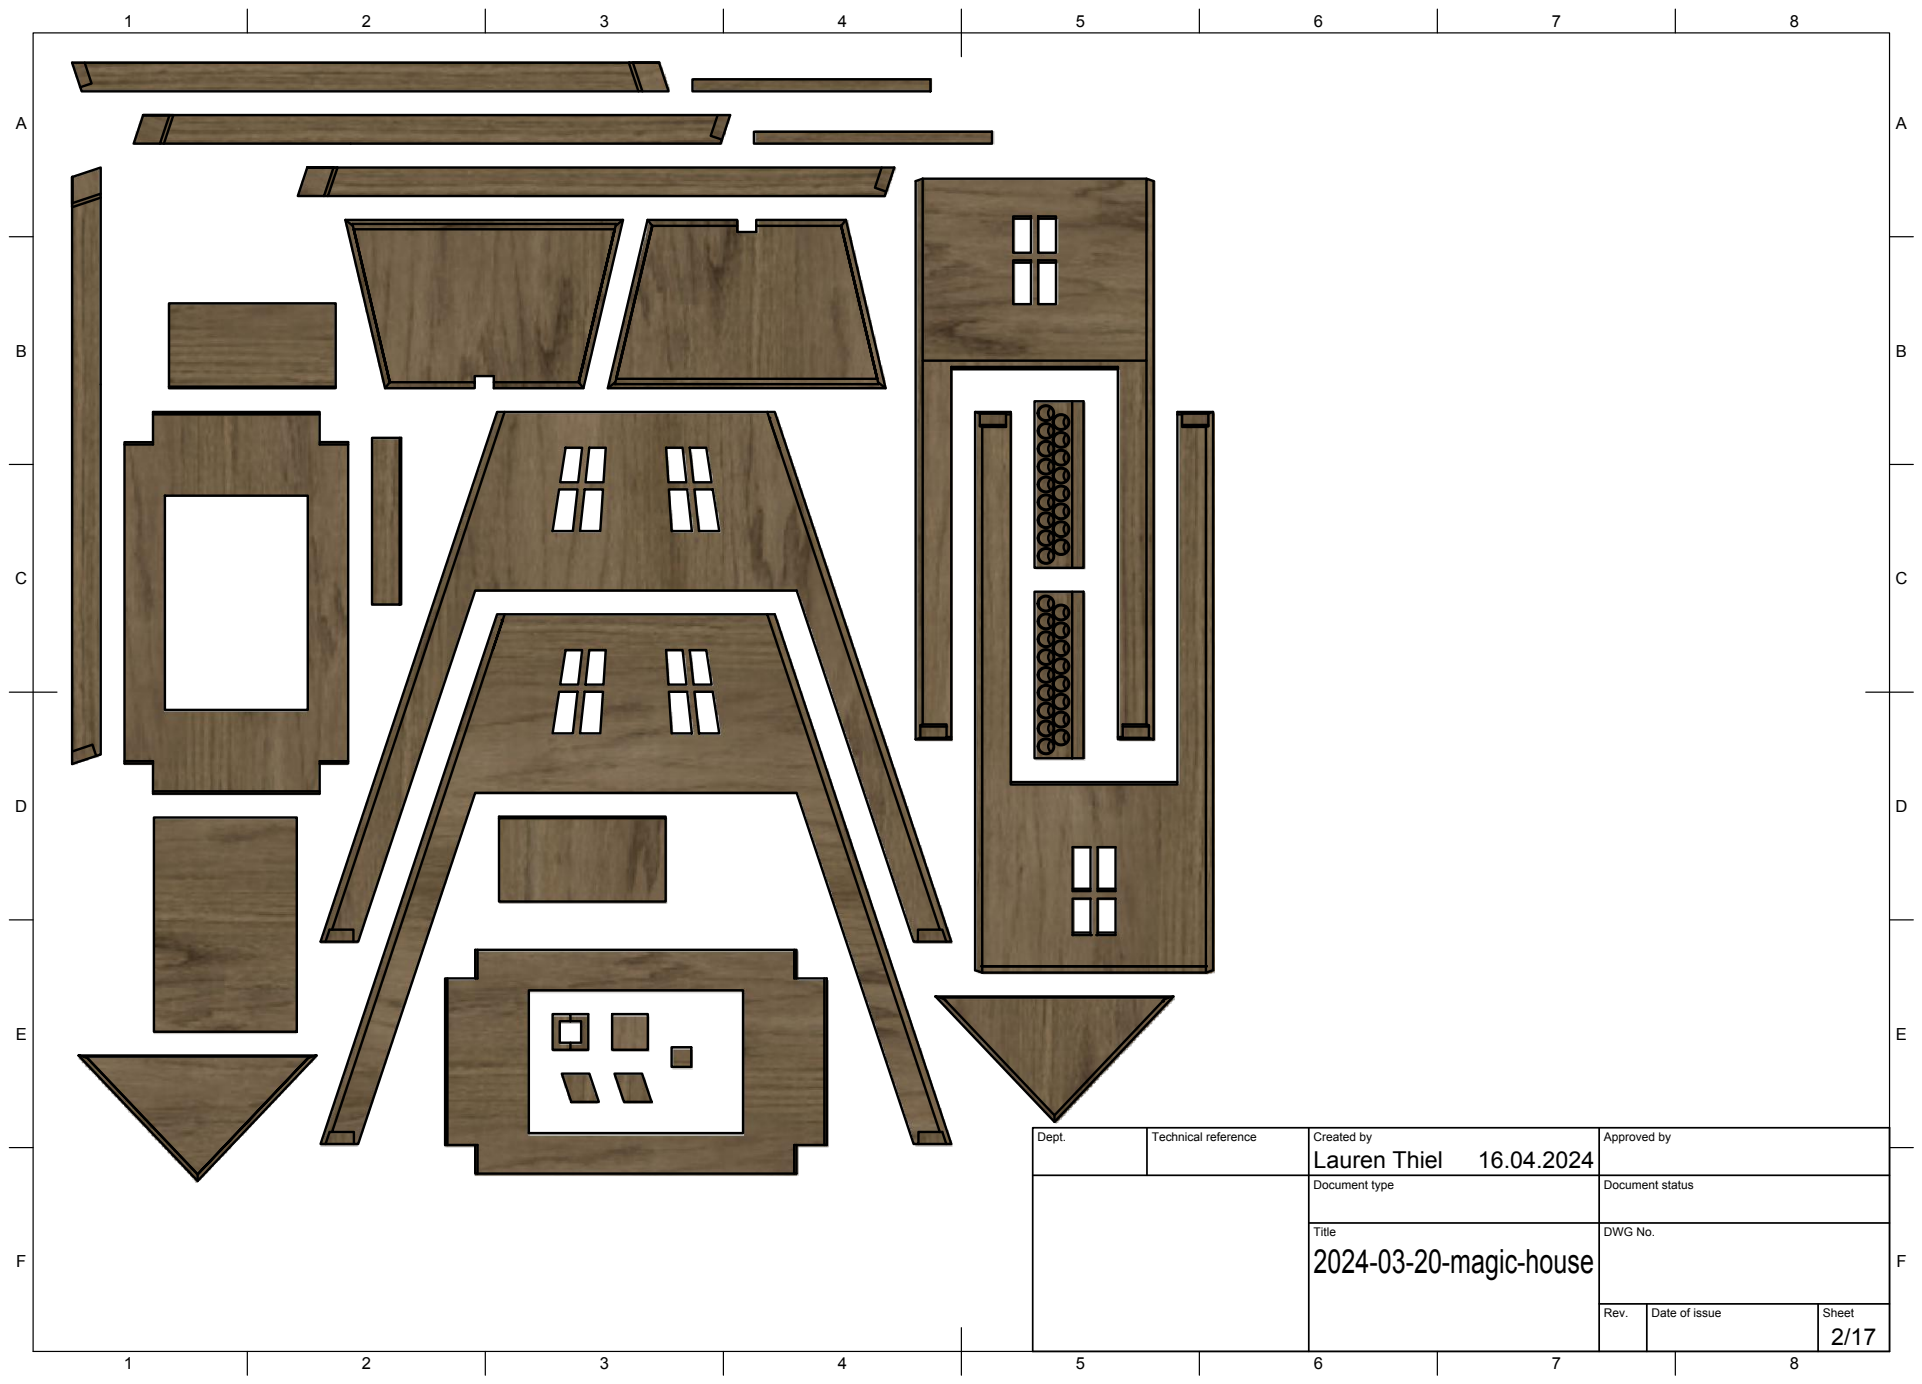
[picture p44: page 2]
Title; DWG No.

Dept. | Technical reference | Created by Lauren Thiel 16.04.2024 | Approved by

Document type | Document status

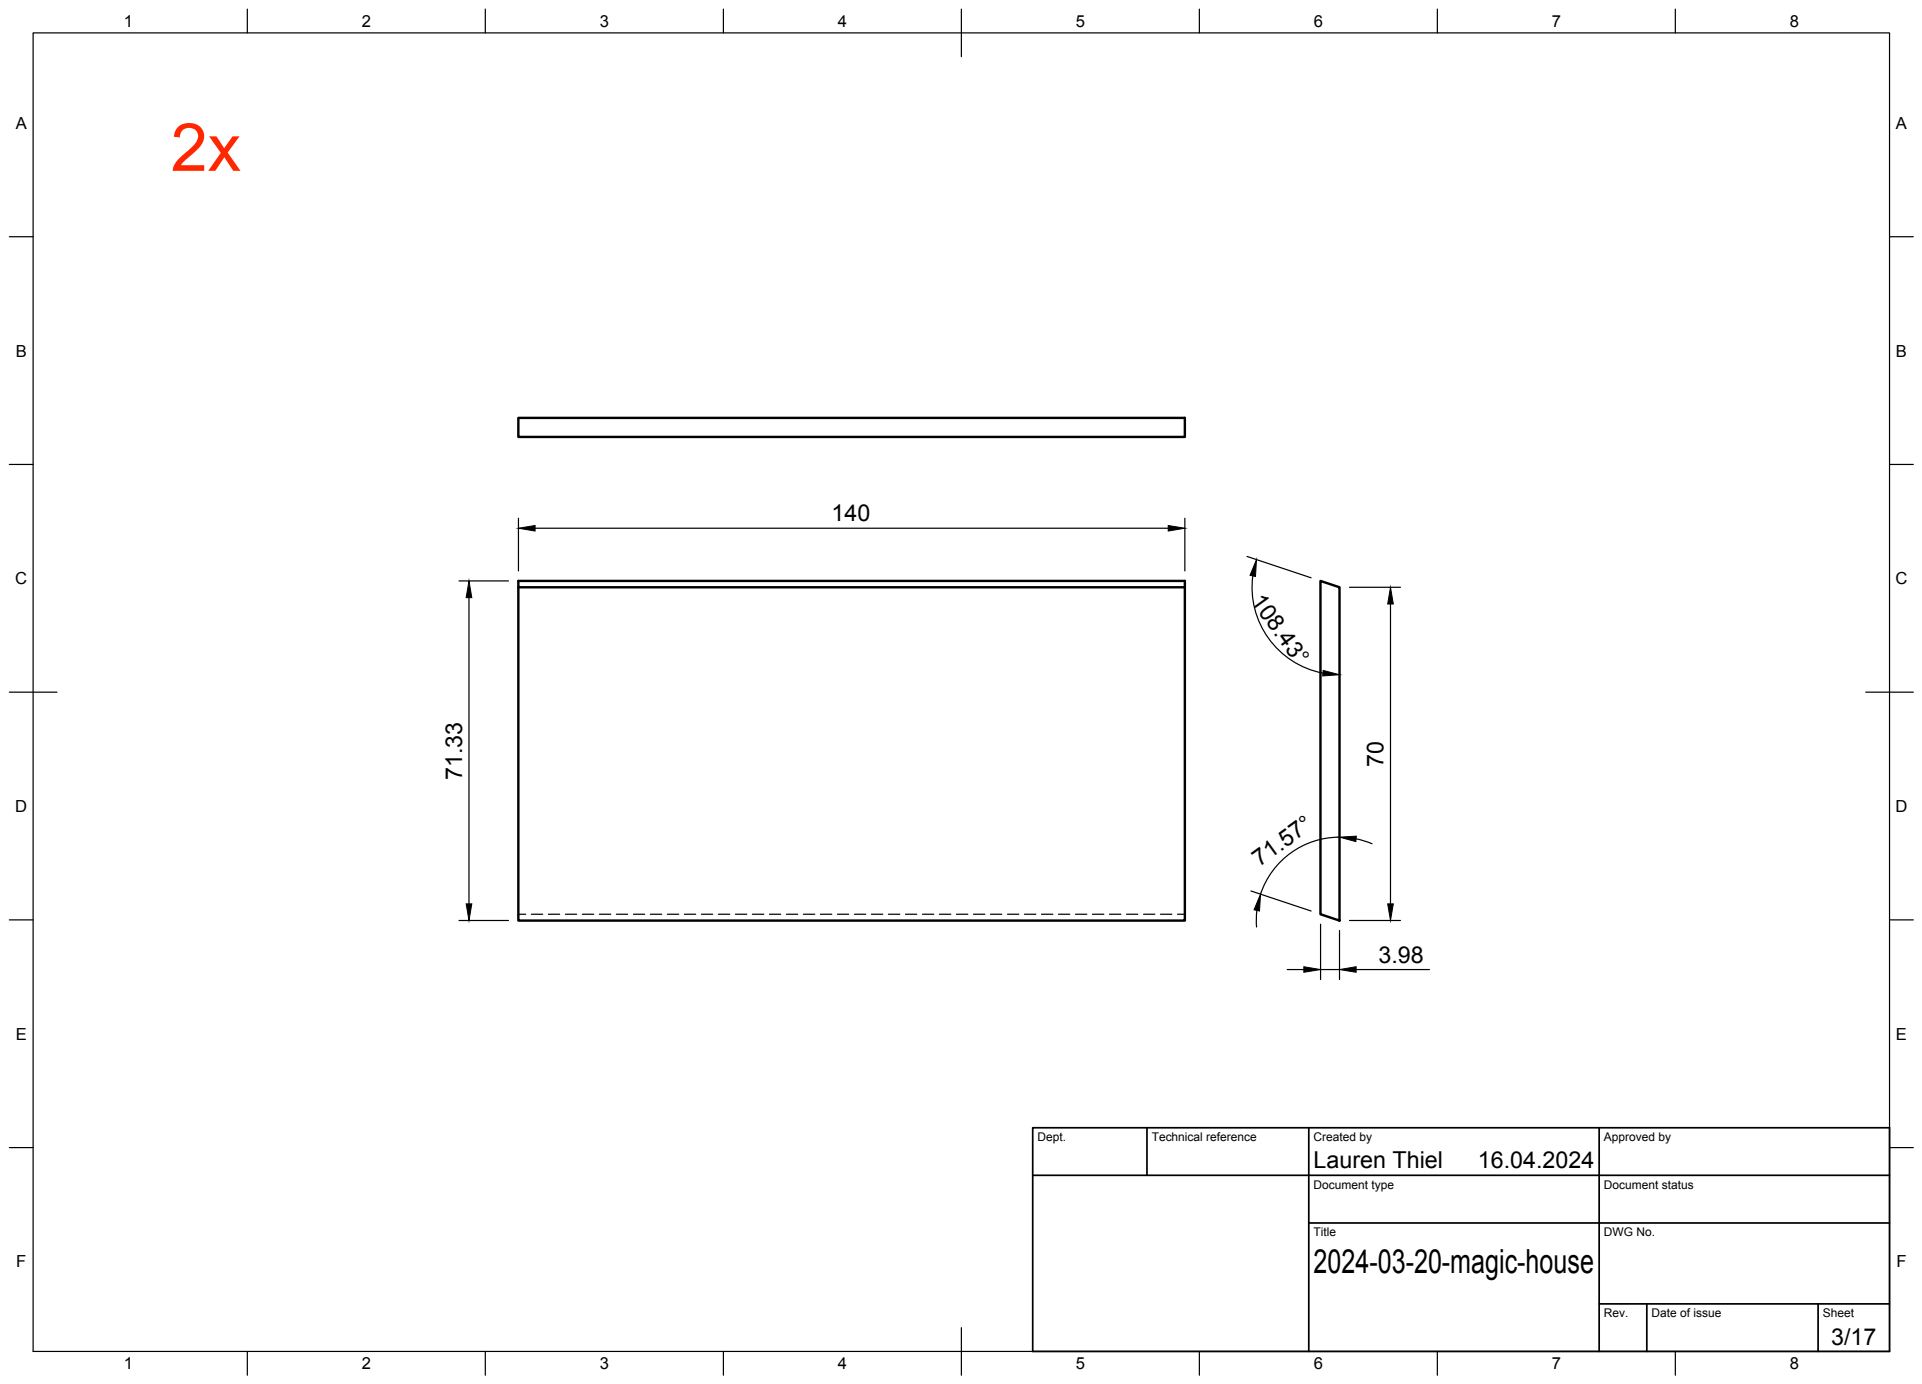
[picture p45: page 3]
Title; DWG No.

Dept. | Technical reference | Created by Lauren Thiel 16.04.2024 | Approved by

Document type | Document status

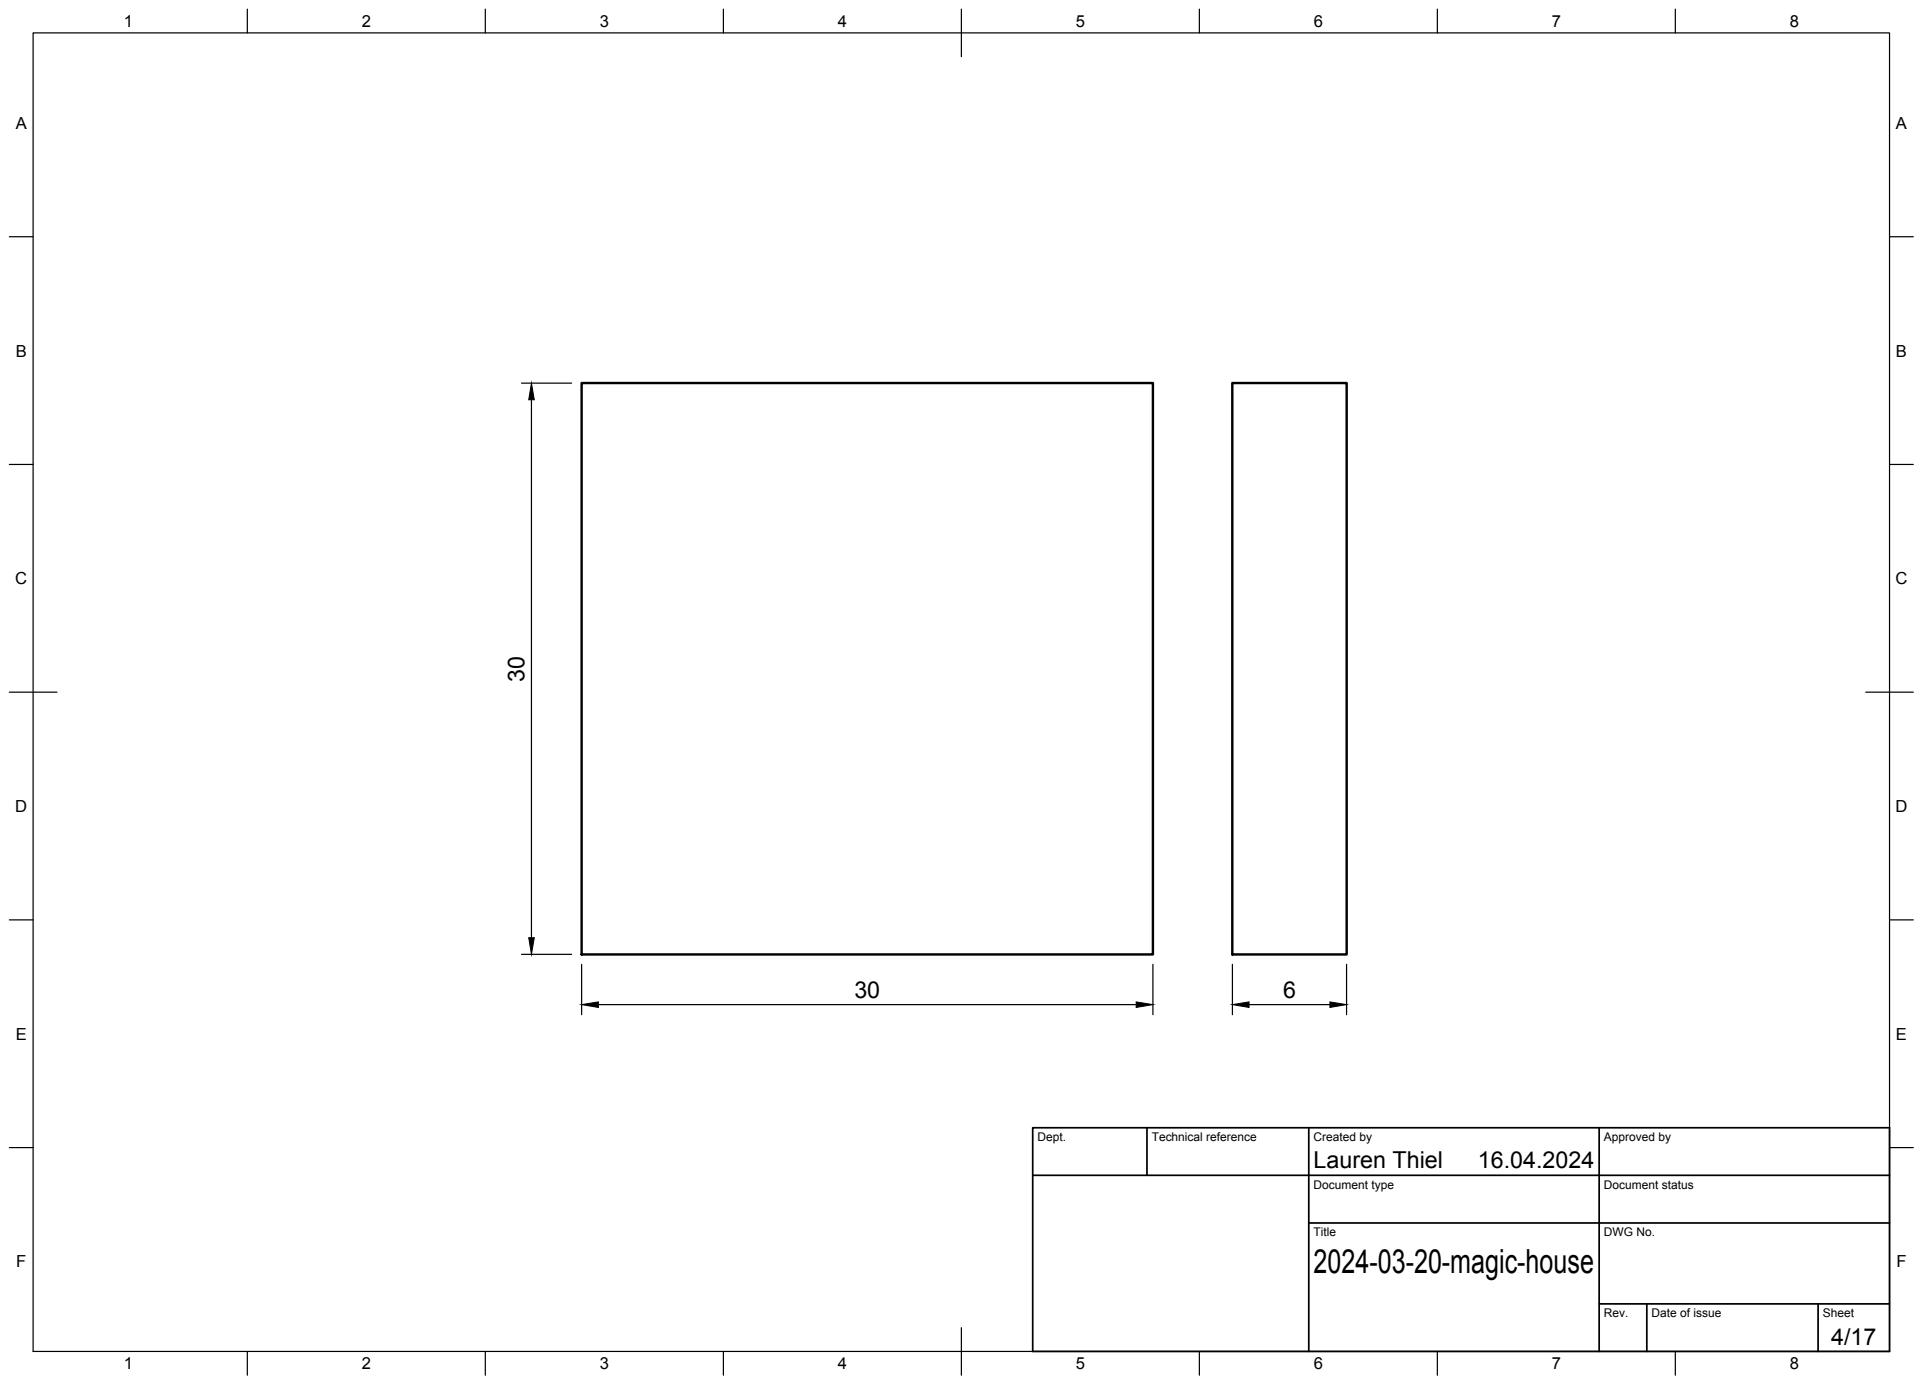
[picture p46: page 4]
Title; DWG No.

Dept. | Technical reference | Created by Lauren Thiel 16.04.2024 | Approved by

Document type | Document status

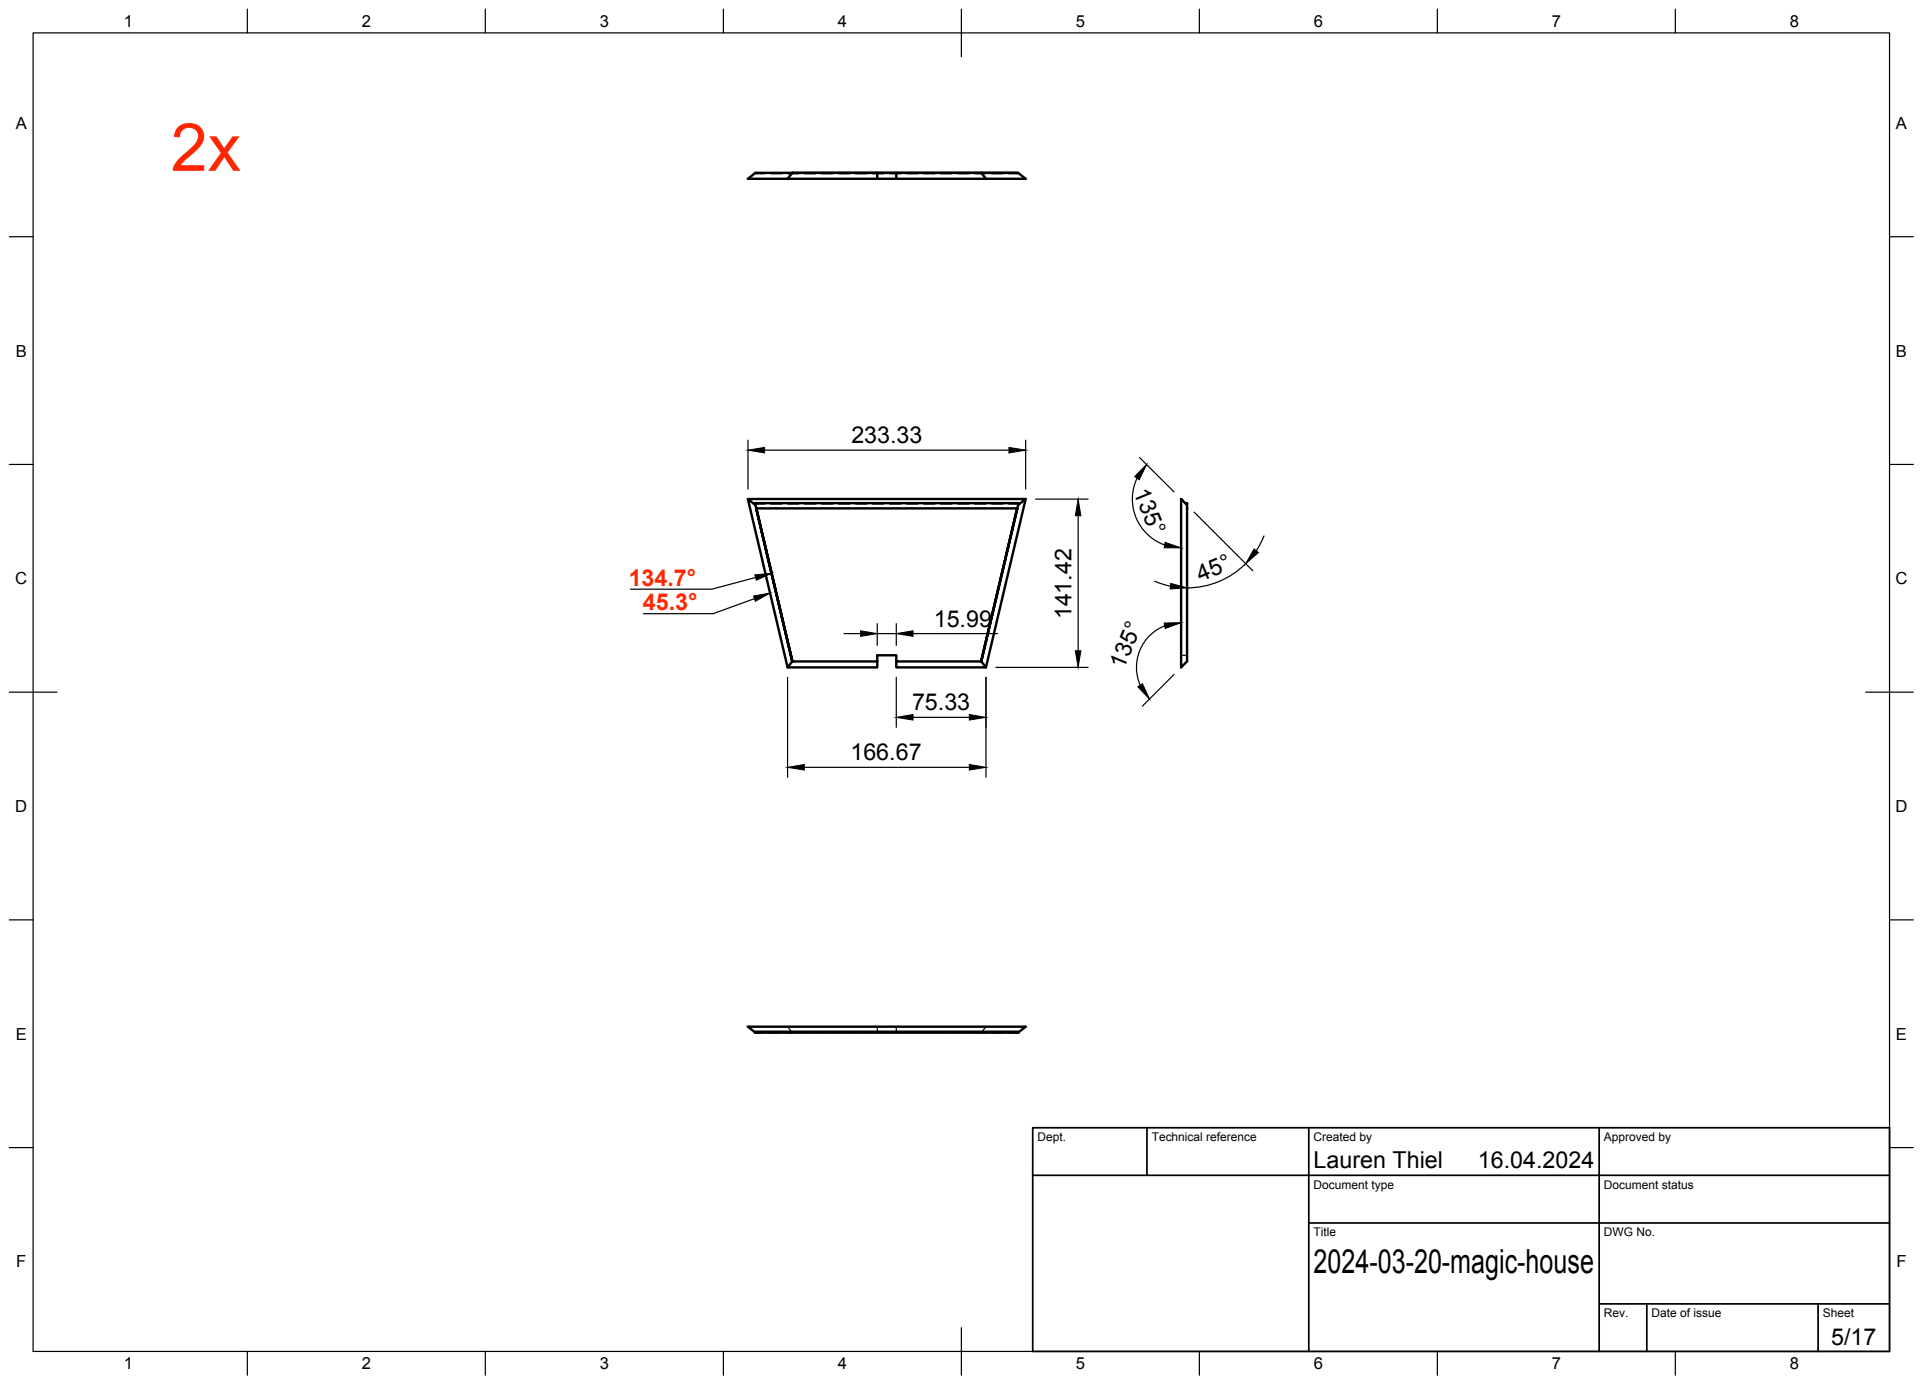
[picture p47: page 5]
Title; DWG No.

Dept. | Technical reference | Created by Lauren Thiel 16.04.2024 | Approved by

Document type | Document status

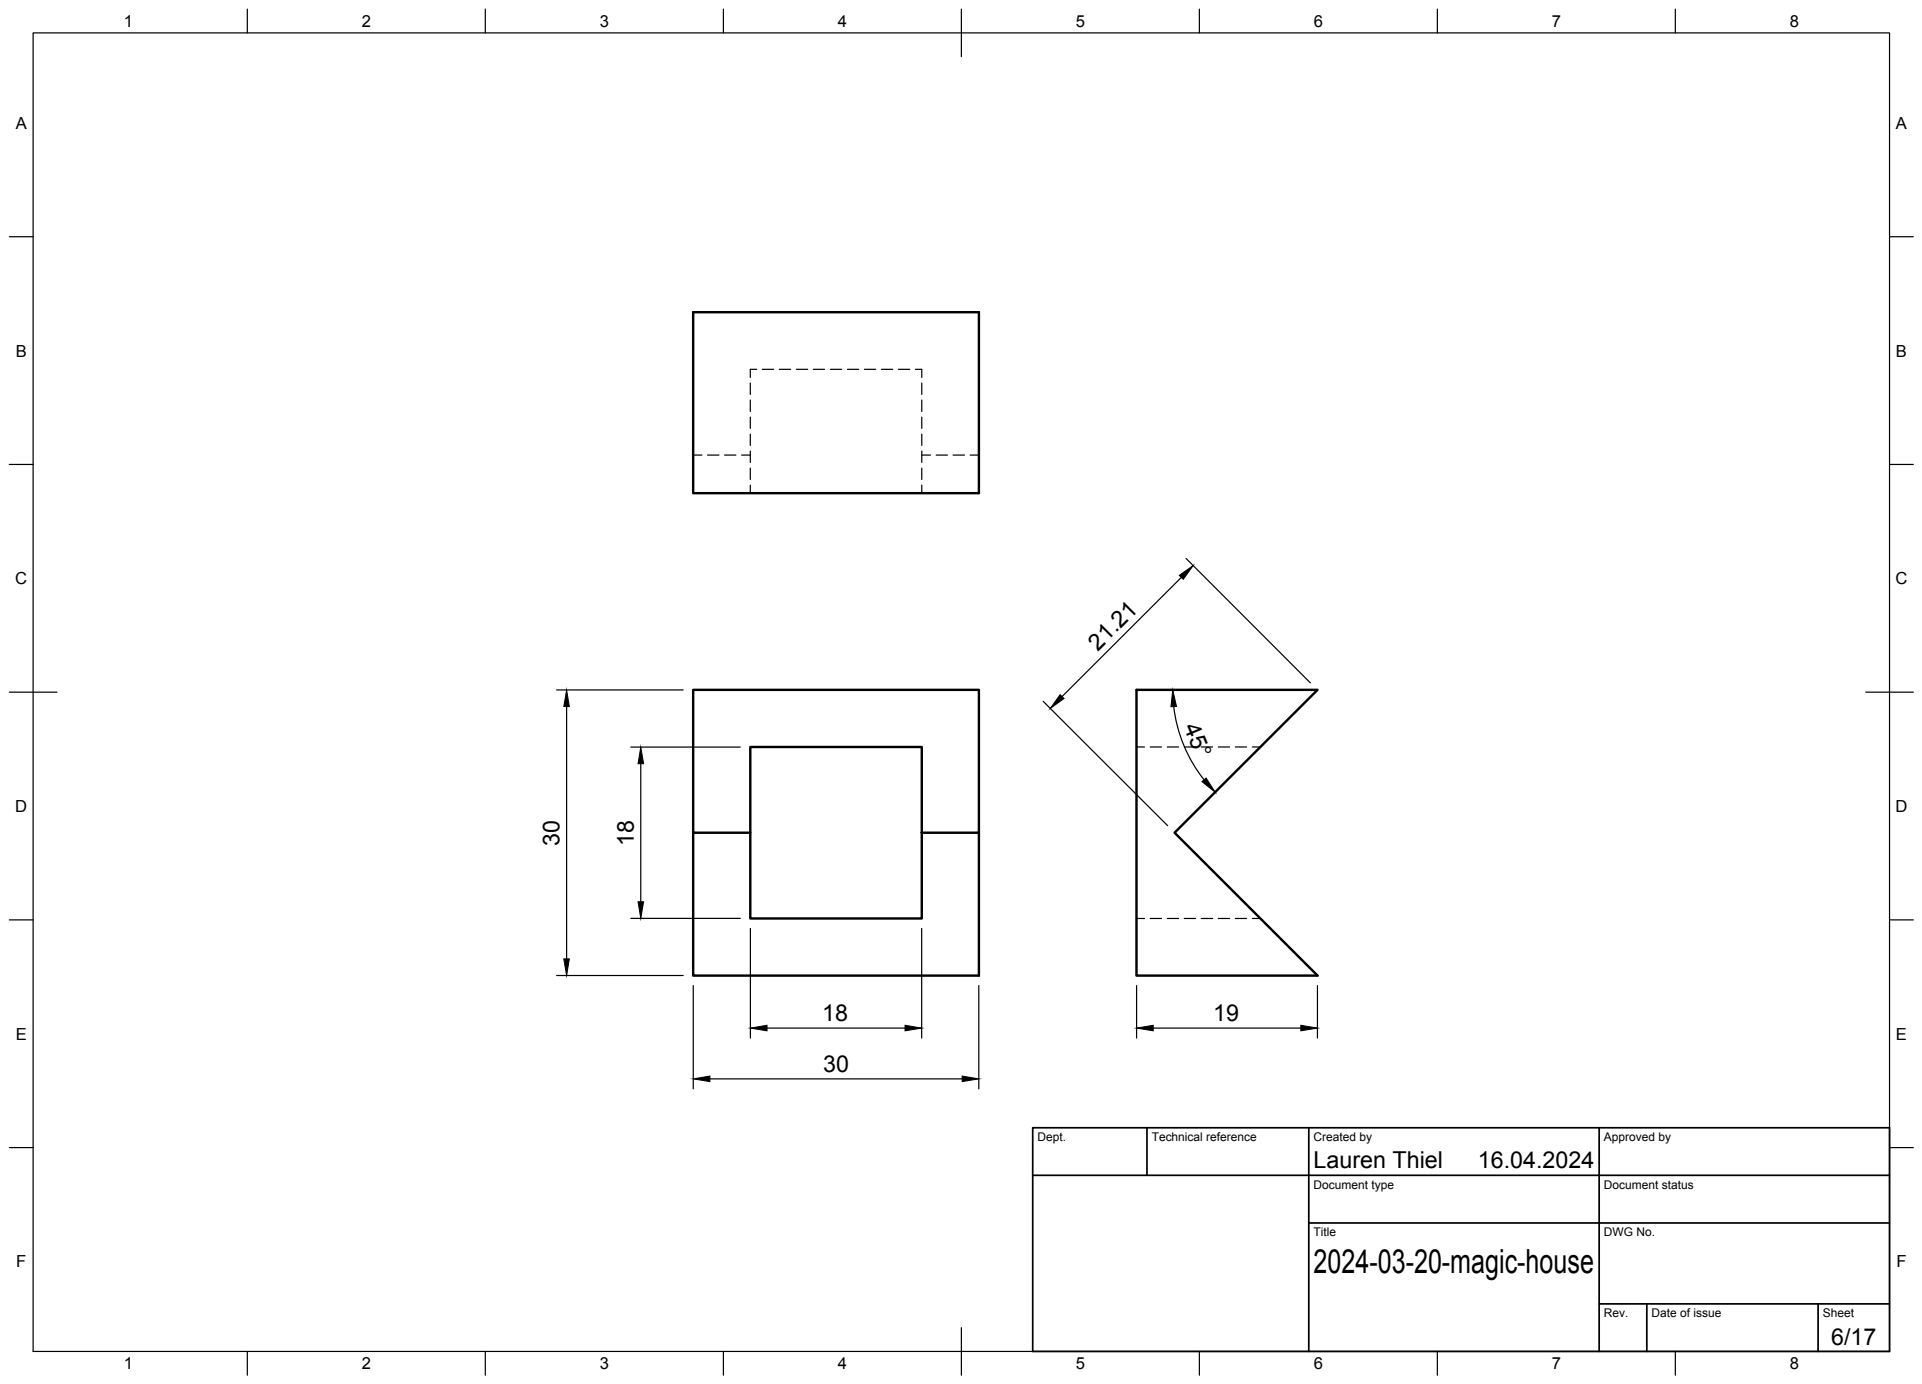
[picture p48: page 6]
Title; DWG No.

Dept. | Technical reference | Created by Lauren Thiel 16.04.2024 | Approved by

Document type | Document status

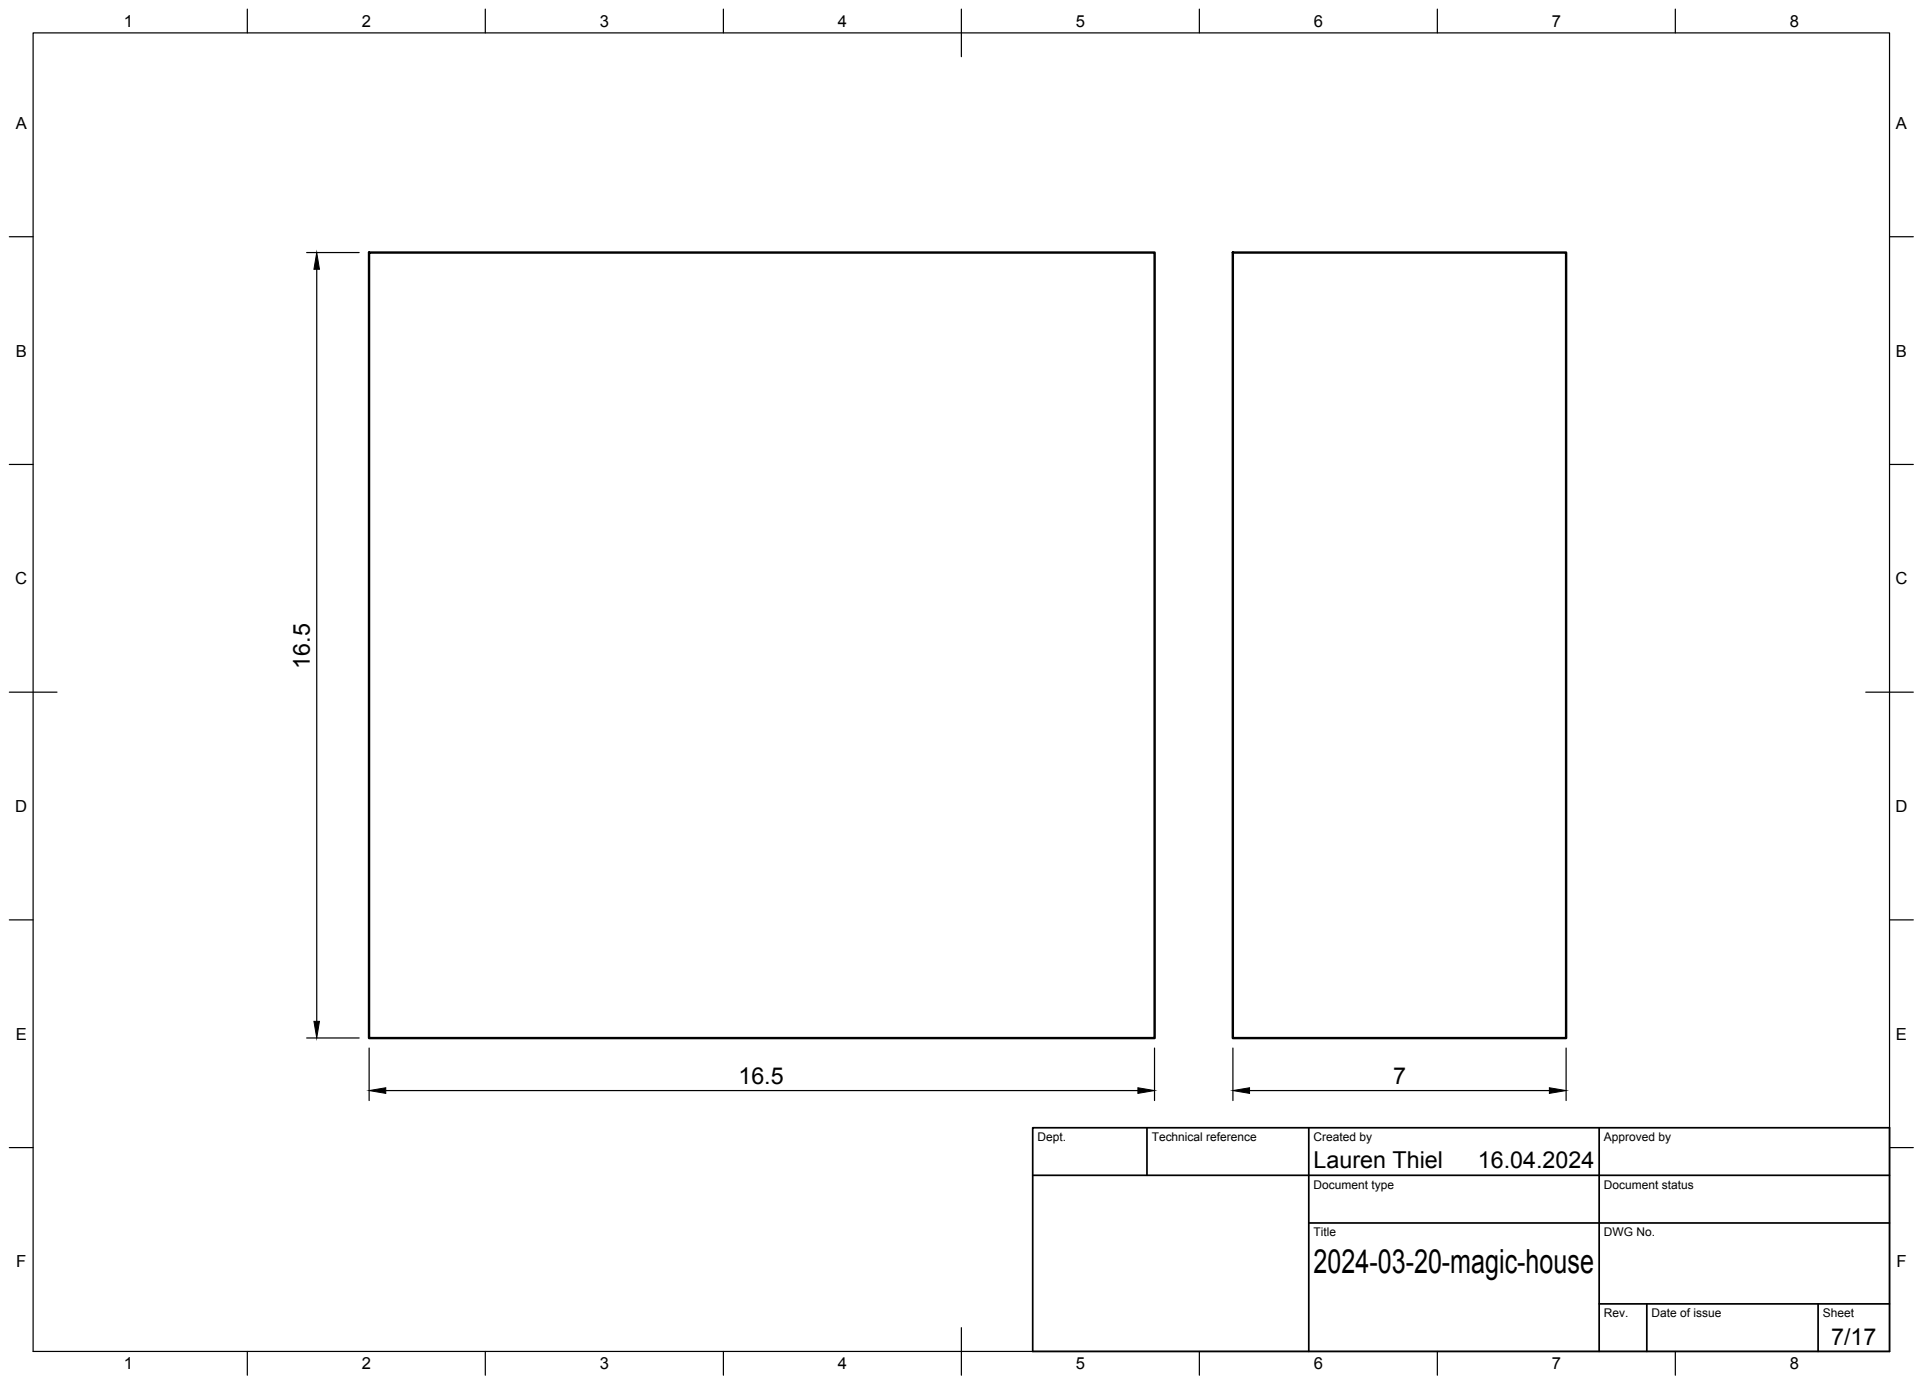
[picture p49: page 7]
Title; DWG No.

Dept. | Technical reference | Created by Lauren Thiel 16.04.2024 | Approved by

Document type | Document status

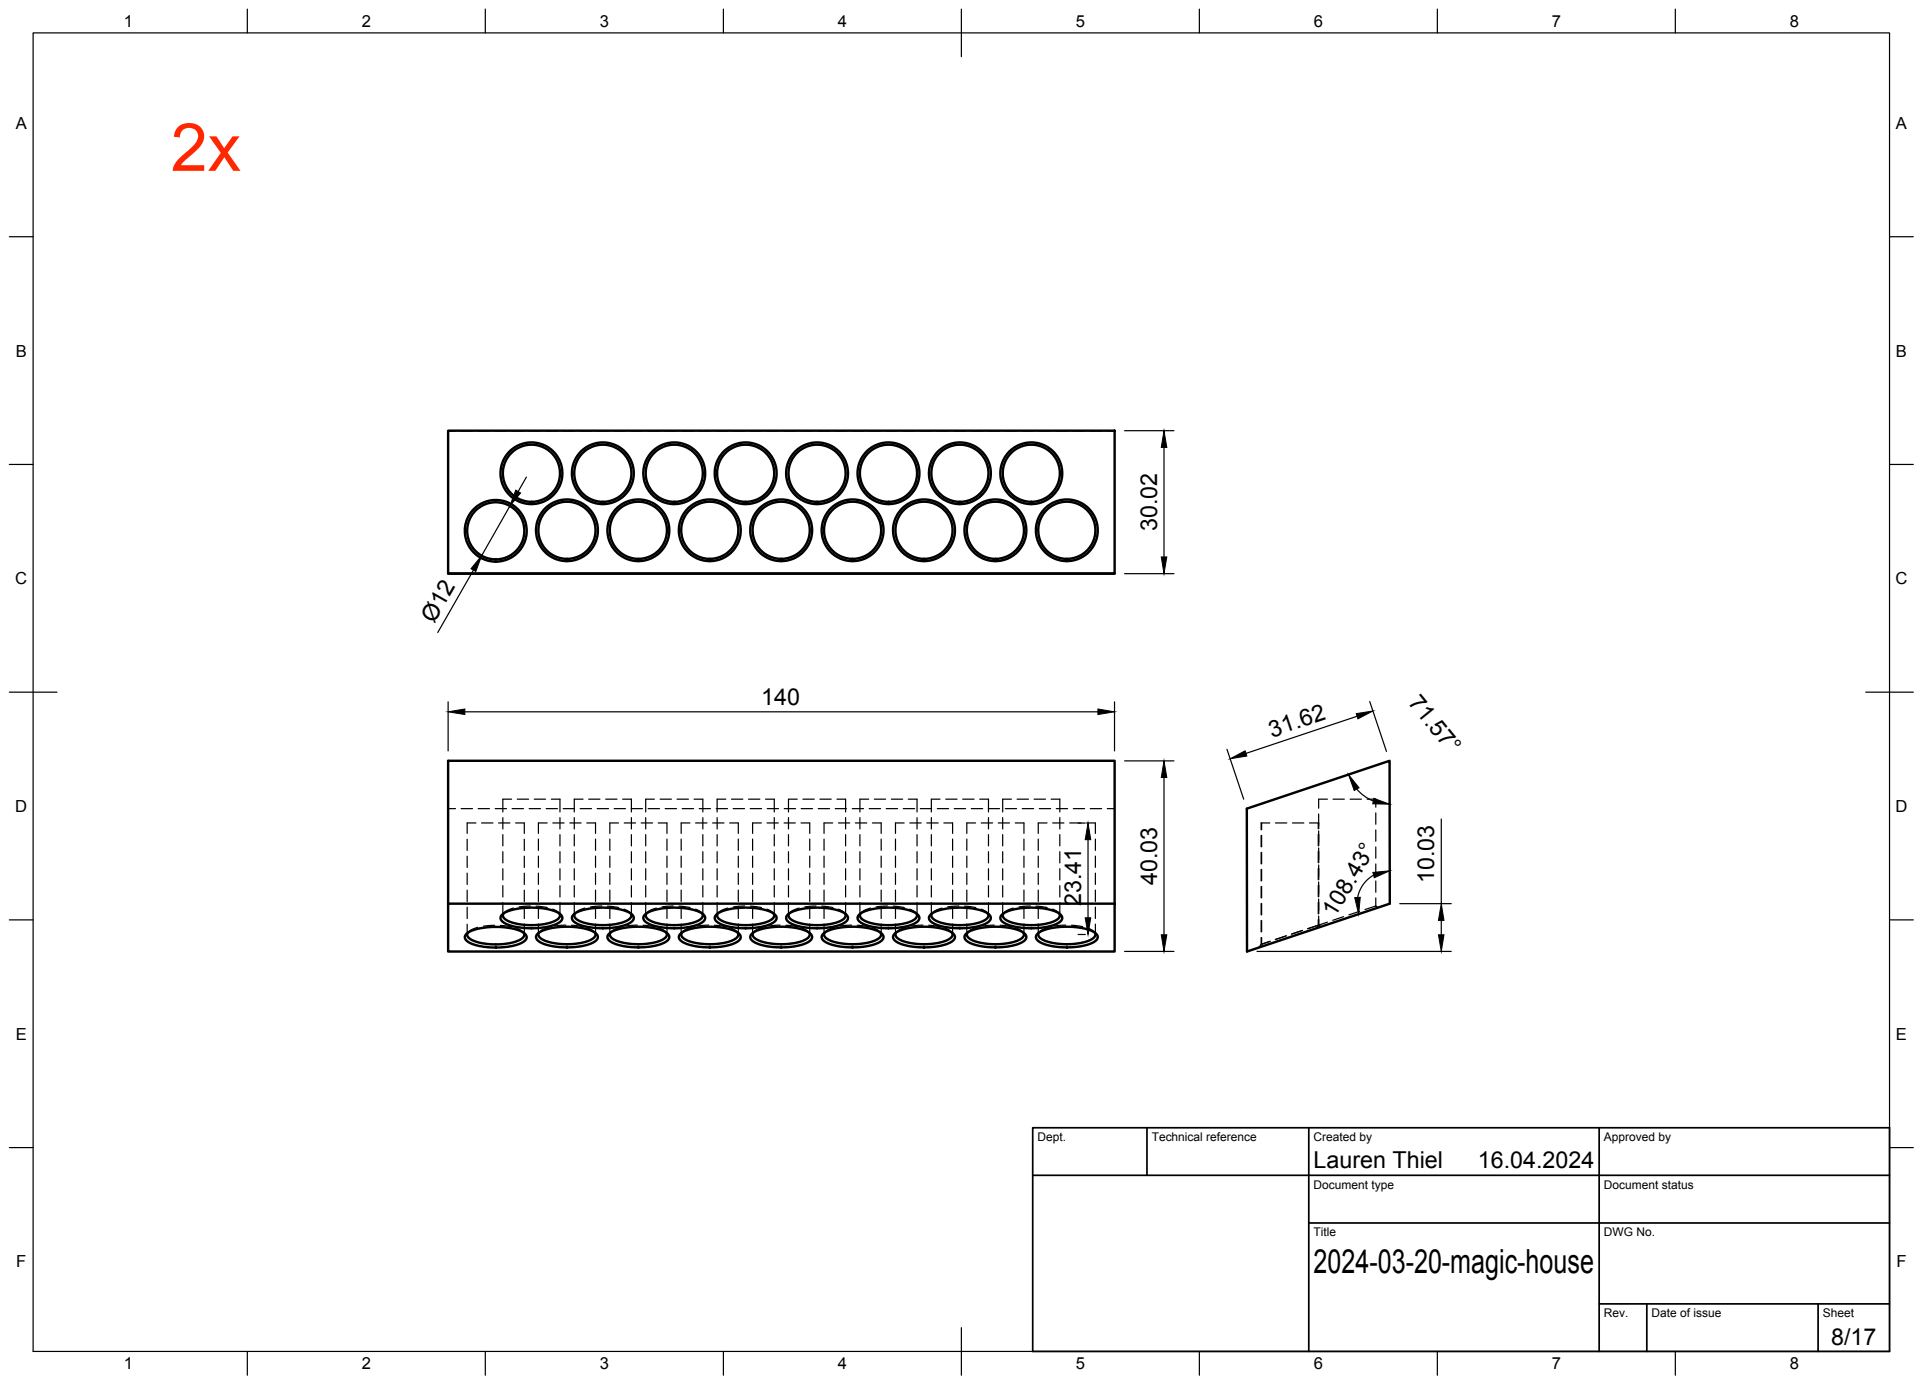
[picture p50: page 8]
Title; DWG No.

Dept. | Technical reference | Created by Lauren Thiel 16.04.2024 | Approved by

Document type | Document status

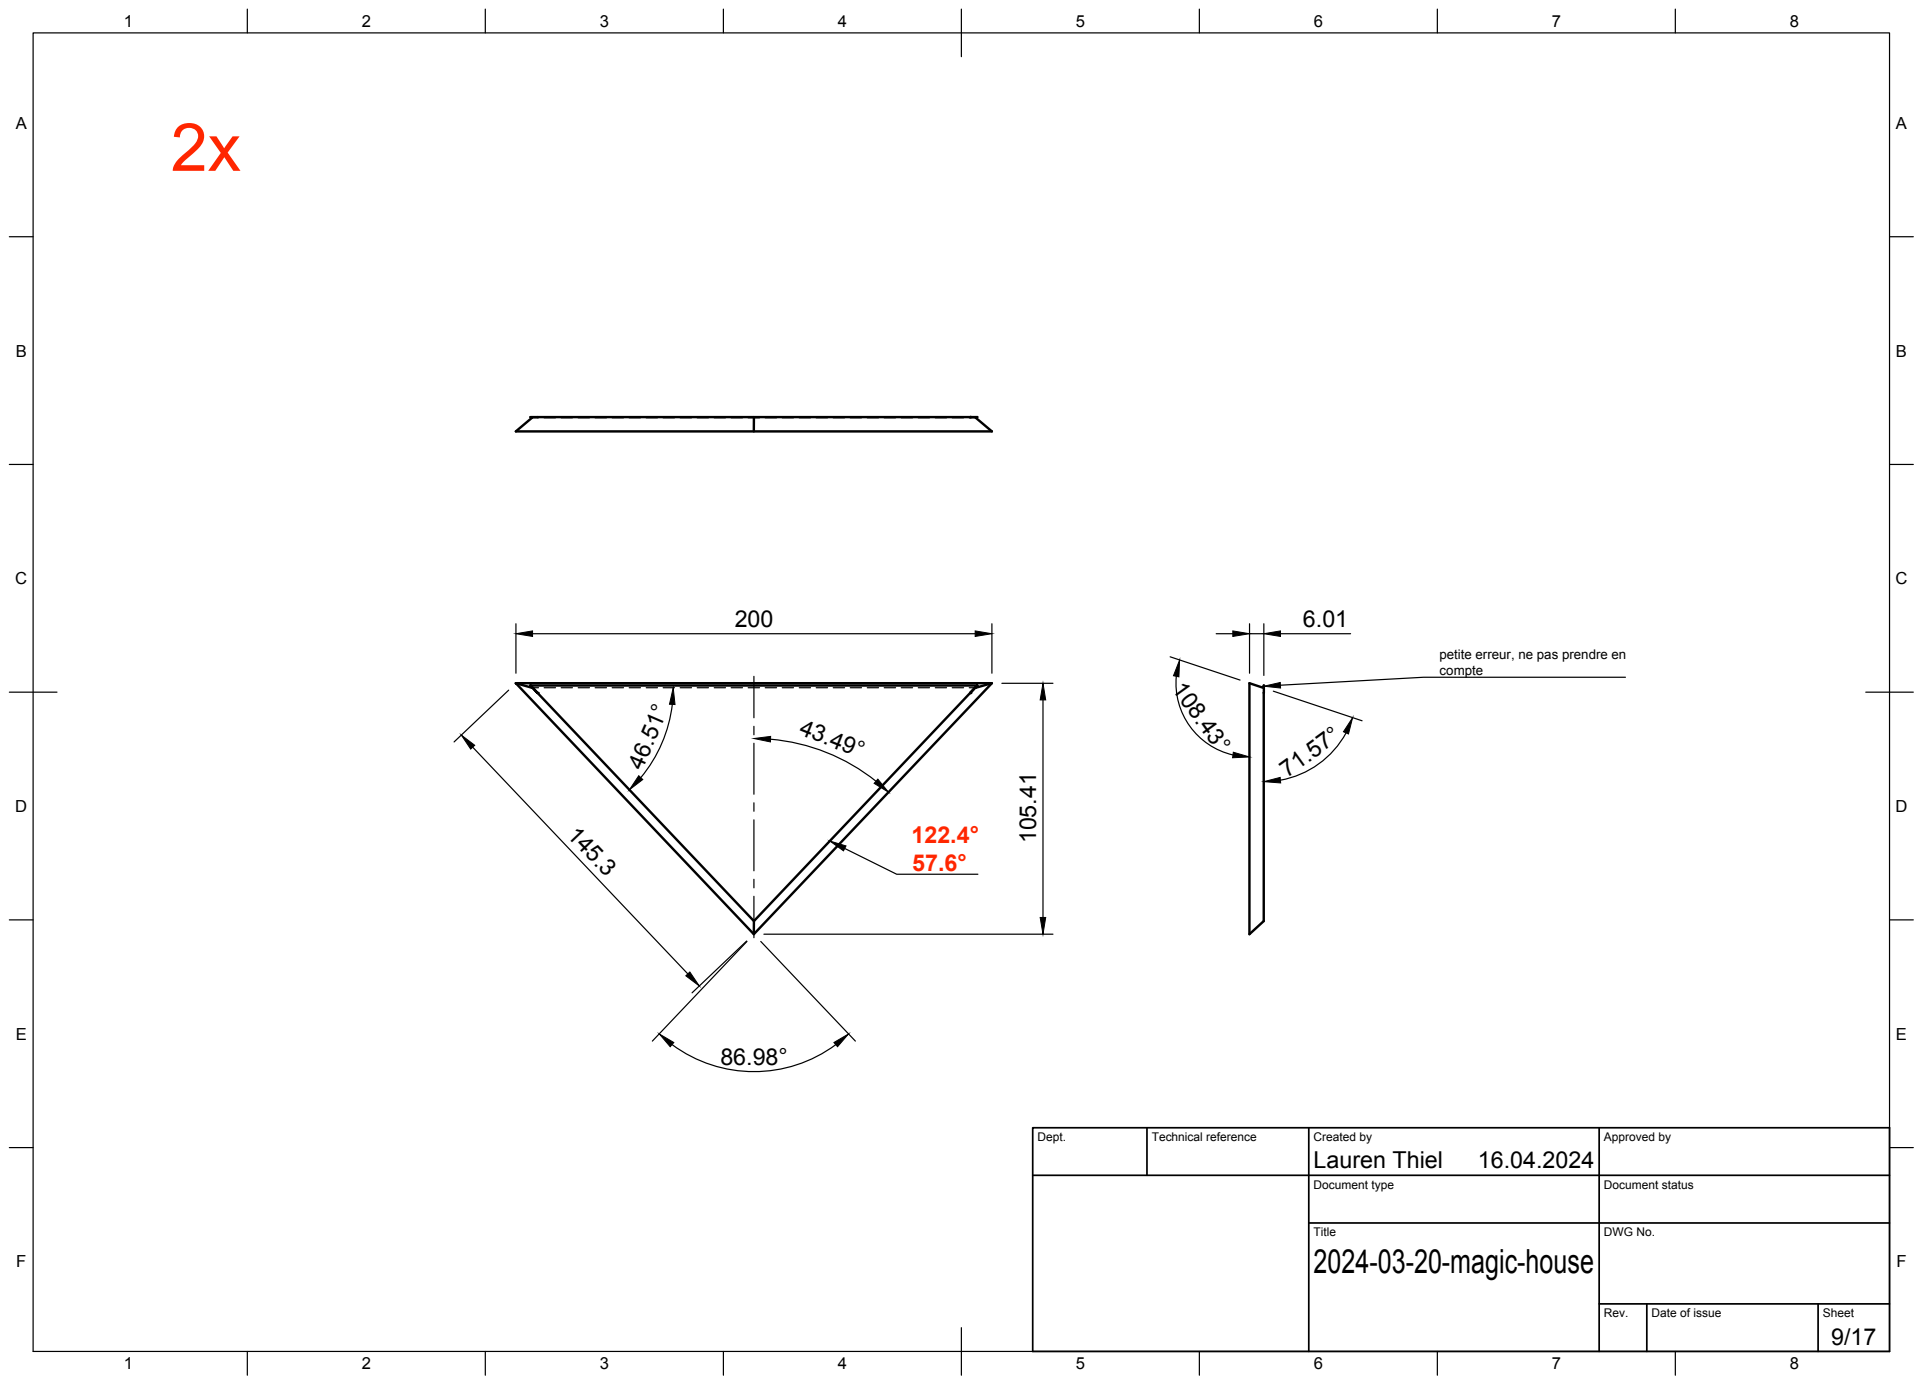
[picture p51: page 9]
Title; DWG No.

petite erreur, ne pas prendre en
compte

Dept. | Technical reference | Created by Lauren Thiel 16.04.2024 | Approved by

Document type | Document status

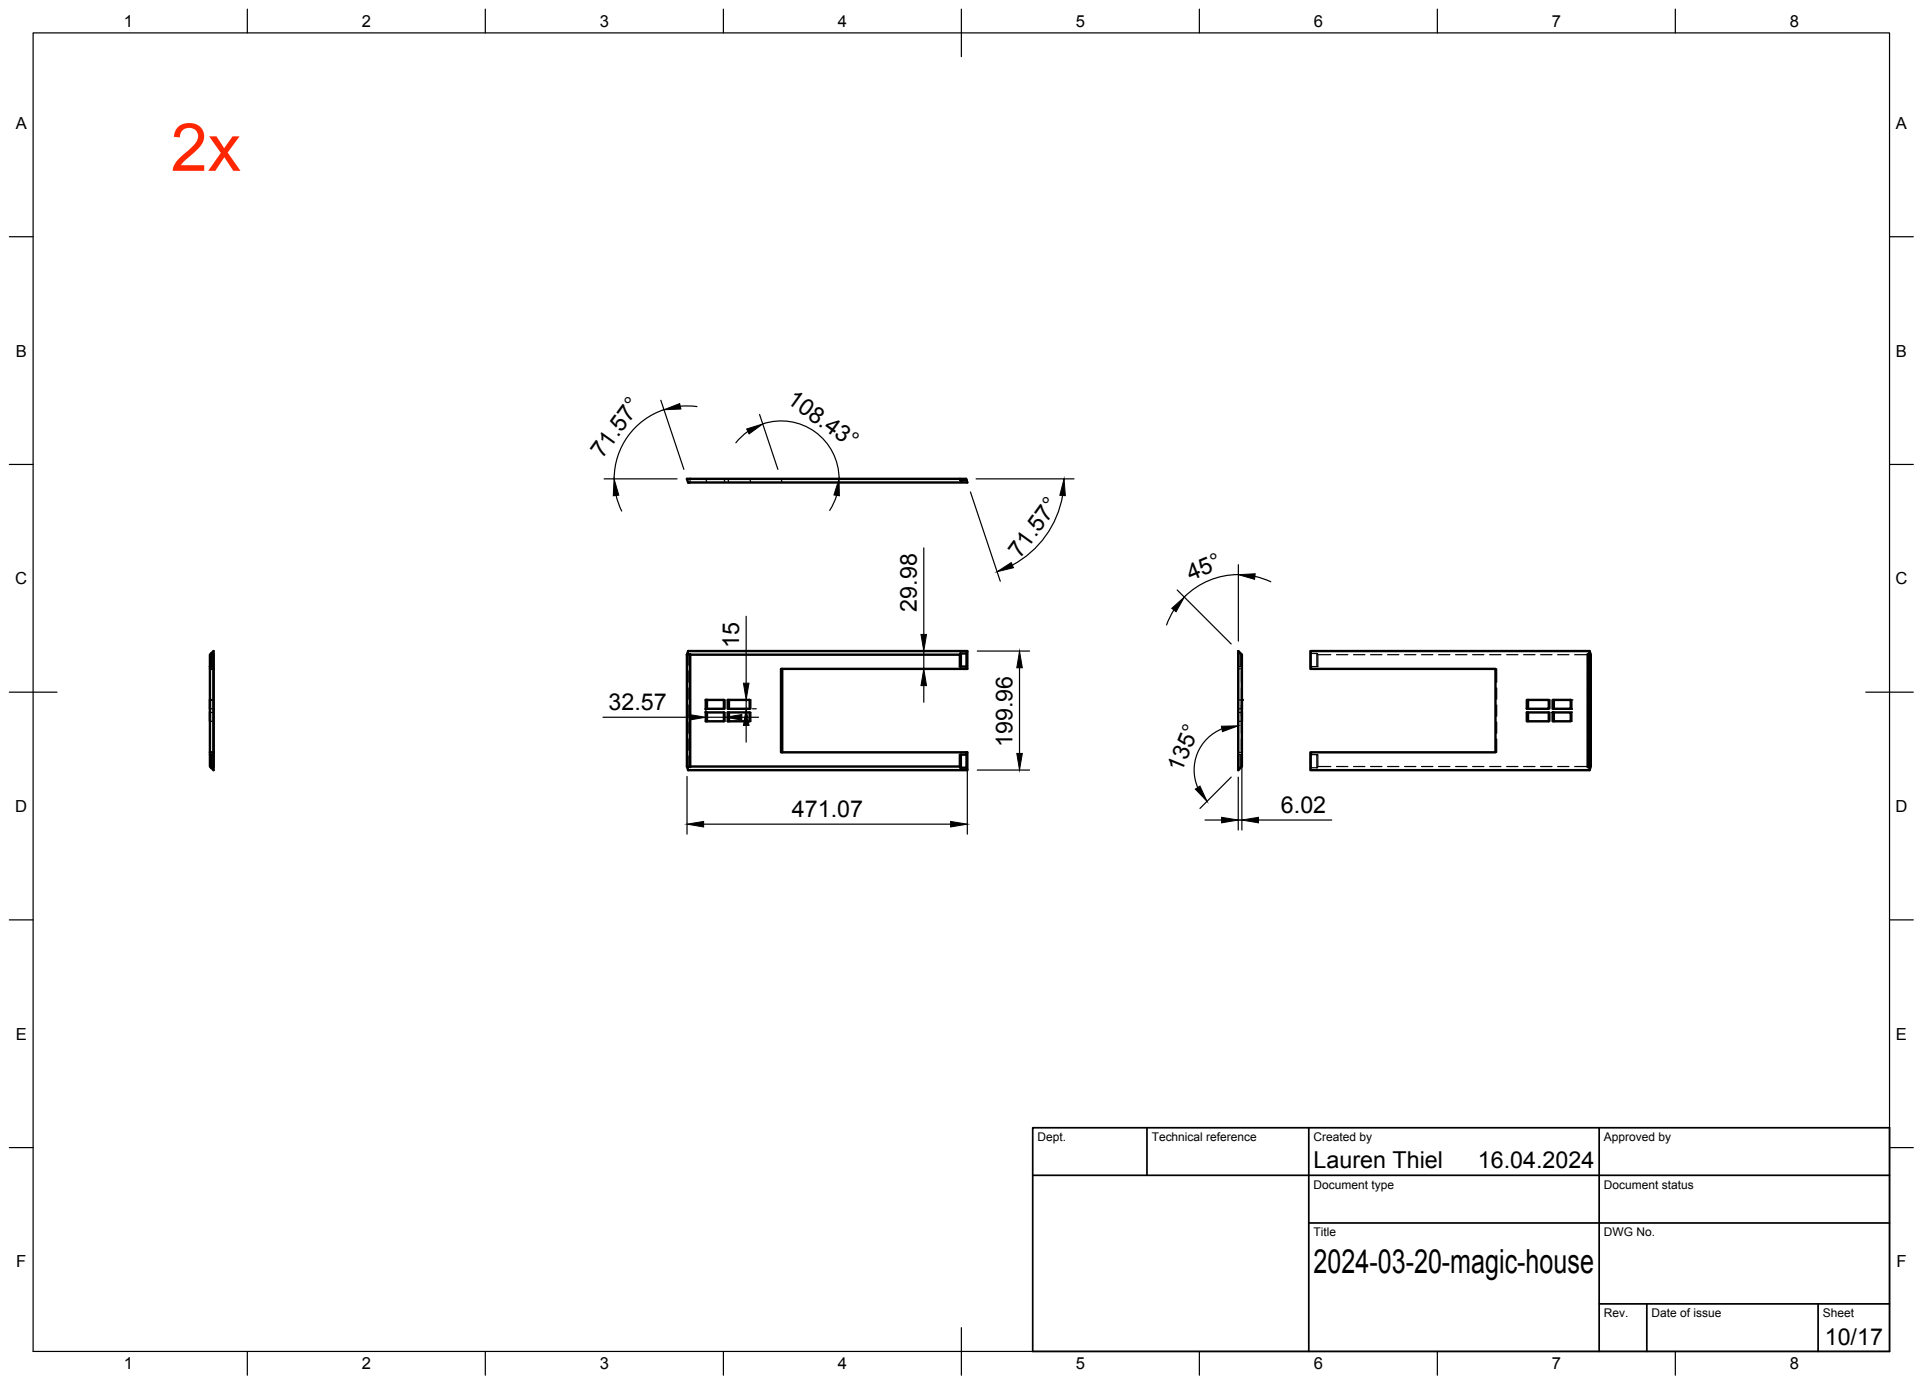
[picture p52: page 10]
Title; DWG No.; Lauren Thiel 199.96

Dept. | Technical reference | Created by 16.04.2024 | Approved by

Document type | Document status

Title; DWG No.

Dept. | Technical reference | Created by Lauren Thiel 16.04.2024 | Approved by

Document type | Document status

Title; DWG No.

Dept. | Technical reference | Created by Lauren Thiel 16.04.2024 | Approved by

Document type | Document status

Title; DWG No.

Dept. | Technical reference | Created by Lauren Thiel 16.04.2024 | Approved by

Document type | Document status

Title; DWG No.

Dept. | Technical reference | Created by Lauren Thiel 16.04.2024 | Approved by

Document type | Document status

Title; DWG No.

Dept. | Technical reference | Created by Lauren Thiel 16.04.2024 | Approved by

Document type | Document status

Title; DWG No.

Dept. | Technical reference | Created by Lauren Thiel 16.04.2024 | Approved by

Document type | Document status

Title; DWG No.

Dept. | Technical reference | Created by Lauren Thiel 16.04.2024 | Approved by

Document type | Document status

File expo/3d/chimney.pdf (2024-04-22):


Dept. | Technical reference | Created by Lauren Thiel 22.04.2024 | Approved by

Document type | Document status

Title 2024-03-20-magic-house | DWG No.

Rev. | Date of issue | Sheet 1/1

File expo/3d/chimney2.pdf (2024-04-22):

Title; DWG No.; Rev.; Date of issue; Sheet

Dept. | Technical reference | Created by Lauren Thiel 22.04.2024 | Approved by

Document type | Document status

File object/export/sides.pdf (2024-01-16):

Title; DWG No.; Rev.; Date of issue; Sheet

Dept. | Technical reference | Created by Lauren Thiel 15.01.24 | Approved by

Document type | Document status


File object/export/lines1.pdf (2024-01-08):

24 BADCFEHGIKJMLONP; BADCFEHGIKJMLONP Dept.; Technical reference; Created by; Approved by Document type; Document status Title; DWG No. Rev.; Date of issue; Sheet 07.01.24; 1/1 form10 Lauren Thiel

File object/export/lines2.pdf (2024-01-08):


Dept. | Technical reference | Created by Lauren Thiel 07.01.24 | Approved by

Document type | Document status

Title form10 | DWG No.

Rev. | Date of issue | Sheet 1/1

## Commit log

2023-11-13 wrote pitch and key insights
2023-12-20 form stuff
    [cat v1.f3d, test_1 v3.f3d, test_3 v2.f3d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]
2023-12-20 form ideas
    [form 8 v3.f3d, form 9 v6.f3d]
2024-01-08 vectors for lazer and python script
    [form10 v5.f3d]
2024-01-10 uploaded schematics for electronics
    [diagram.fzz, shematic.fzz]
2024-01-16 Final updates !!
    [Lauren_Thiel_animation_studio.f3d, shematic.fzz]
2024-03-20 added expo files and fusion redesign
    [FORM1.f3d]
2024-03-20 renamed 3d file
    [2024-03-20-magic-house.f3d]
2024-04-12 expo readme
    [2024-03-20-magic-house.f3d]
2024-04-22 monday of carendach week
    [roues.stl]
